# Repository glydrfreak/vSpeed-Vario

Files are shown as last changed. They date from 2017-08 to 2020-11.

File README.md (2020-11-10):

### This repository contains all previous prototypes. </br>
### Click <a href="https://github.com/glydrfreak/vSpeedVario-mini">here</a> for the final product repository. </br>
<table float="center">
  <tr>
    <td align="center" width=50%>
      <h1>v^Speed Vario</h1>
      Contents:</br>
      <a href="https://github.com/glydrfreak/vSpeedVario-mini">v^SPEED VARIO mini</a></br>
      <a href="#compare">Compare</a> </br>
      <a href="#vspeed-vario">Android App</a></br>
      <a href="#flyskyhy">iPhone App</a> </br>
      <a href="#solidworks">3D Printing</a> </br>
      <a href="#arduino-ide">Arduino Code</a> </br>
      <a href="#eagle-cad">Custom Circuit Board</a> </br>
      <a href="#bill-of-materials">Parts List</a> </br>
    </td>
    <td align="center"> 
      <h3>DIY Paragliding Variometer</h3>
       
      <h6>(Vertical Speed Indicator)</h6>
    </td>
  </tr>
</table>

<table>
  <tr>
    <td width=33% vAlign="top" align="center">
      <h2>v^SPEED VARIO mini</h2>
      <h3>$99</h3>
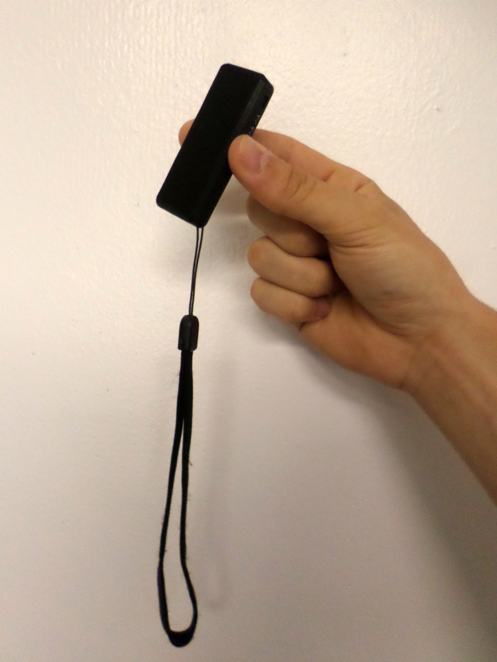
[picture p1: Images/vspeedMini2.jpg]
       </br>
         Email vSpeedVario@gmail.com to purchase </br>
      <a href="#vspeed-vario">Back to Top</a> </br>
    </td>
    <td width=66%> 
      <ul>
        <h3>SPECS:</h3>
        <li>Ultra-high precision barometric pressure sensor detects altitude changes as small as 10cm</li>
        <li>Lowest priced Bluetooth Variometer on the market</li>
        <li>iPhone users: Fully compatible with <a href="#flyskyhy">FlySkyHy</a> app</li>
        <li>Android users: <a href="#vspeed">v^SPEED</a> app new in Google Play Store</li>
        <li>Fully compatiple with Arduino IDE to easily change custom settings</li>
        <li>Mounts on risers with velcro</li>
        (leash, and velcro for both riser and vario included)
        <li>Tiny Size: 68x25x10mm (about the size of a man's thumb)</li>
        <li>3D printed cover screws onto circuit board </li>
          (black, white, yellow, or light blue)
        <li>Power switch, and volume buttons</li>
        <li>100mAh lipo battery with microUSB charging port</li>
        <li>7hr battery life while streaming bluetooth data</li>
        <li>1hr charging time</li>
        <li>Sale price: $99 each (subject to change)</li>
        <h3>OR -- DIY! --</h3><h6>(assuming you have a 3D printer, an SWD programmer, and a reflow oven)</h6>
        <li>1 hand assembled: ~ $70 each </li>
        <li>10 hand assembled: ~ $38 each</li>
        <li>10 machine assembled: ~ $89 each</li>
        <li>100 machine assembled: ~ $59 each</li>
      </ul>
    </td>
  </tr>
</table>

<table>
  <tr>
    <td width=33% vAlign="top" align="center">
      <h2>v^SPEED Vario</h2>
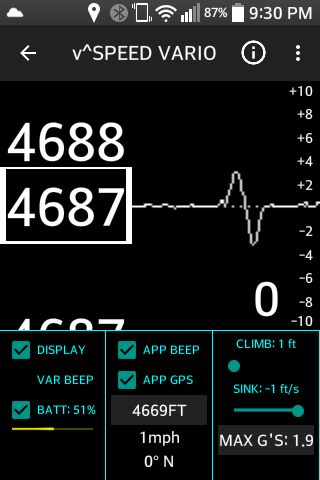
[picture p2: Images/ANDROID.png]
      
      <a href="#vspeed-vario">Back to Top</a> </br>
    </td>
    <td width="66%"> 
      <ul>
        <h3>Android App--</h3>
        I have modified Adafruit's "Bluefruit LE Connect" for Android and the source code can be found in the Android folder. Now published to Google Play! </br>
  </br>
        This app will give you a better image of what your v^SPEED Vario is doing as it transmits live bluetooth data of barometric altitude, vertical speed, and battery level. Other features include implemented GPS for GPS altitude, ground speed, and heading. The implemented Audio beeps are helpful for listening to each foot of climb as well as a variable sink tone. An implemented accelerometer is for keeping track of max G-force during a hard turn or spiral. The visual display includes a line chart of vertical speed, as well as scrolling altitude numbers so you can see your precise vertical velocity. The climb and sink thresholds are adjustable within the app, which also change the thresholds on the external vario automatically.
      </ul>
    </td>
  </tr>
</table>

<table>
  <tr>
    <td width=33% vAlign="top" align="center">
      <h2>Flyskyhy</h2>
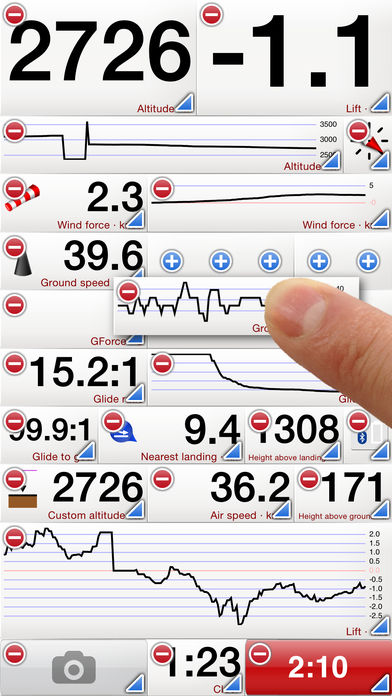
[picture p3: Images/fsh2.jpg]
      
      <a href="#vspeed-vario">Back to Top</a> </br>
    </td>
    <td width=66%> 
      <ul>
        <h3>iOS App by Renevision--</h3>
        I've been working with Rene to get v^SPEED VARIO compatible with the World's most popular Paragliding app! He's been very helpful throughout the process, and Flyskyhy is an unbeatable iPhone application when it comes to flying. v^Speed Vario is currently using the same protocol as SkyDrop variometers, so in the app when selecting your device, you must choose SkyDrop for the time being.  
      </ul>
    </td>
  </tr>
</table>

<h1>Prior Prototypes:</h1>

<table>
  <tr>
    <td width=33% vAlign="top" align="center">
      <h2>PROTOTYPE5</h2>
      <h4>(In Progress)</h4>
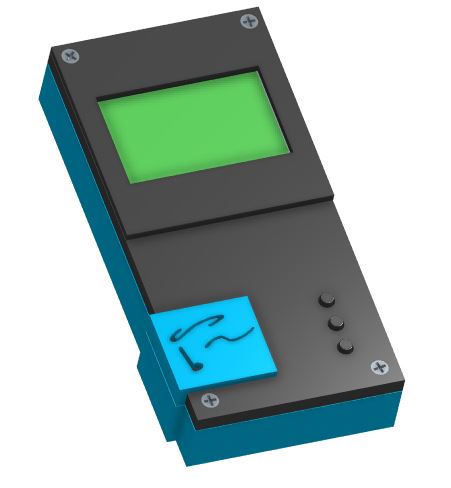
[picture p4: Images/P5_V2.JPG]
      
      <a href="#vspeed-vario">Back to Top</a> </br>
    </td>
    <td width=66%> 
      <ul>
        <h3>IMPROVEMENTS:</h3>
        <li>Nokia 5110 LCD is much cheaper</li>
        <li>2.9" e-Paper display was having interference issues</li>
        <li>Three buttons used for interfacing with menu</li>
        <li>Screw-together 3D printed case is much more printer friendly</li>
        <li>Size: 97x47x18mm</li>
        <li>Material cost for ten: ~ $54 each</li>
        <li>Material cost for one: ~ $96 each</li>
      </ul>
    </td>
  </tr>
</table>

<table>
  <tr>
    <td width=33% vAlign="top" align="center">
      <h2>PROTOTYPE4</h2>
      <h4>(Aborted)</h4>
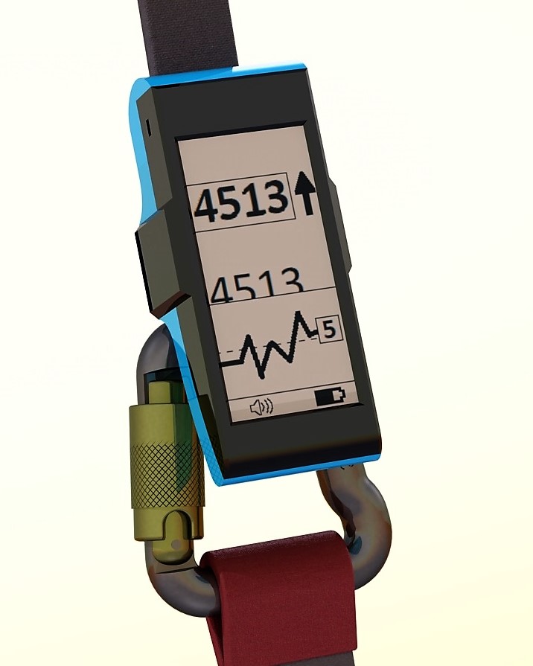
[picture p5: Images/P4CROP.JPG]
      
      <a href="#vspeed-vario">Back to Top</a> </br>
    </td>
    <td width=66%> 
      <ul>
        <h3>IMPROVEMENTS:</h3>
        <li>Bluetooth compatible with:</li>
        <ul>
          <li>iPhone: Flyskyhy</li>
          <li>Android: v^Speed (soon to be published)</li>
        </ul>
        <li>2.9" e-Paper display is much larger</li>
        <li>Amplified electromagnetic buzzer is much louder</li>
        <li>Micro SD saves settings and any desired flight data</li>
        <li>Single Button power-on also used for interfacing with menu</li>
        <li>Machine assembly potential: All SMD components, except the switch</li>
        <li>Size: 100x40x30mm</li>
        <li>Material cost for ten: $69 each</li>
        <li>Material cost for one: $111 each</li>
      </ul>
    </td>
  </tr>
</table>

<table>
  <tr>
    <td width=33% align="center" vAlign="top">
      <h2>PROTOTYPE3</h2>
      <h4>(Fully Working)</h4>
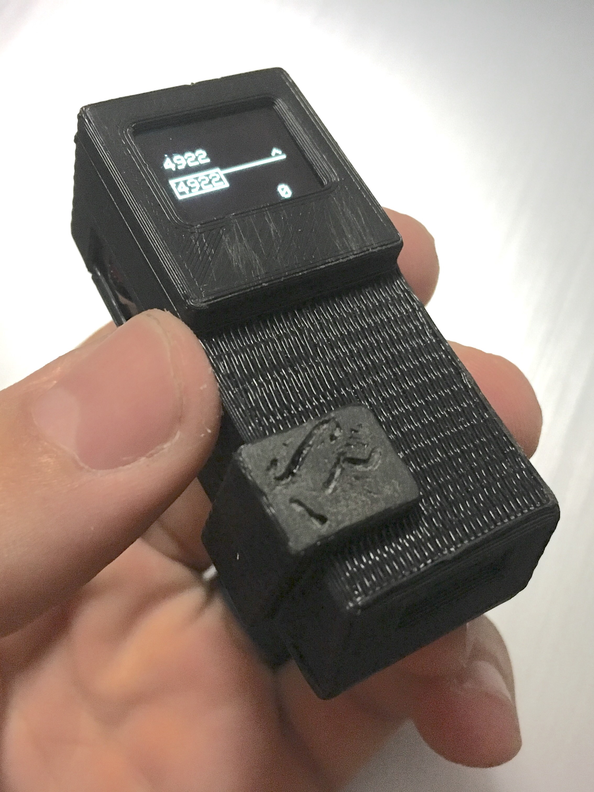
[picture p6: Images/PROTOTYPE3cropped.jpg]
       
      <a href="#vspeed-vario">Back to Top</a> </br>
    </td>
    <td width=66%> 
      <ul>
        <h3>IMPROVEMENTS:</h3>
        <li>Bluetooth compatible with:</li>
        <ul>
          <li>iPhone: Flyskyhy</li>
          <li>Android: v^SPEED (soon to be published)</li>
        </ul>
        <li>Adafruit Feather Bluefruit M0</li>
        <li>MS5611 Barometric Pressure/Temperature Sensor (SPI mode) </li>
        <li>Less than several INCHES of altitude noise with a simple averaging filter</li>
        <li>37 Altitude samples per second with the display screen ON</li>
        <li>56 Altitude samples per second while connected to your phone with the display screen OFF</li>
        <li>Size: 60x28x20mm (perfect for wrist watch, or riser mounting)</li>
        <li>0.66" OLED display (SPI mode)</li>
        <li>PS1740 Piezo Buzzer</li>
        <li>3D Printed Case</li>
        <li>Custom designed PCB</li>
        <li>Audio and a handful of widgets are implemented in each app</li>
        <li>Material cost for ten: $45 each</li>
        <li>Material cost for one: $77 each</li>
      </ul>
    </td>
  </tr>
</table>

<table>
  <tr>
    <td width=33% align="center" vAlign="top">
      <h2>PROTOTYPE2</h2>
      <h4>(Discontinued)</h4>
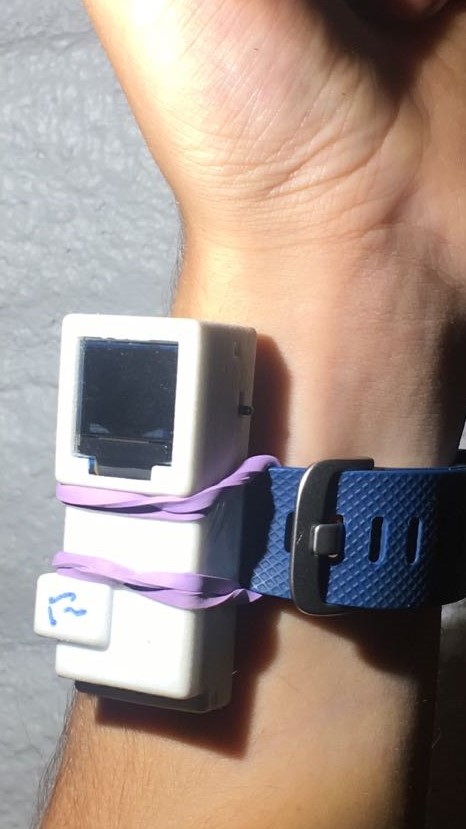
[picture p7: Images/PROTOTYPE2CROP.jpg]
       
      <a href="#vspeed-vario">Back to Top</a> </br>
    </td>
    <td width=66%> 
      <ul>
        <h3>IMPROVEMENTS:</h3>
        <li>Bluetooth compatible with:</li>
        <ul>
          <li>iPhone: (Not yet compatible) </li>
          <li>Android: v^SPEED (soon to be published)</li>
        </ul>
        <li>Adafruit Feather Bluefruit 32u4</li>
        <li>MS5611 Barometric Pressure/Temperature Sensor (SPI mode) </li>
        <li>Less than several INCHES of altitude noise with a simple averaging filter</li>
        <li>21 Altitude samples per second with the display screen ON</li>
        <li>49 Altitude samples per second while connected to your phone with the display screen OFF</li>
        <li>Size: 60x20x28mm (perfect for wrist watch, or riser mounting)</li>
        <li>0.66" OLED display (SPI mode)</li>
        <li>PS1740 Piezo Buzzer</li>
        <li>3D Printed Case</li>
        <li>Custom designed PCB</li>
        <li>Audio and a handful of widgets are implemented in the  v^SPEED app</li>
        <li>Material cost for ten: $45 each</li>
        <li>Material cost for one: $77 each</li>
      </ul>
    </td>
  </tr>
</table>

<table>
  <tr>
    <td width=33% align="center" vAlign="top">
      <h2>PROTOTYPE1</h2>
      <h4>(One of a kind)</h4>
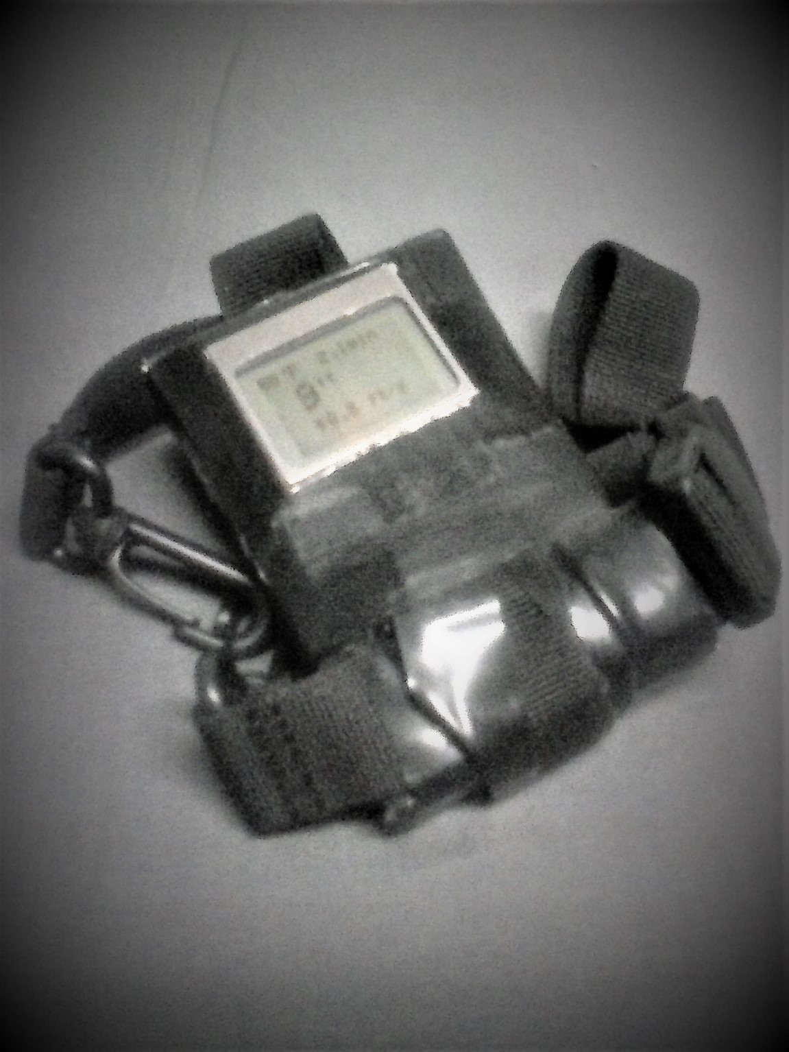
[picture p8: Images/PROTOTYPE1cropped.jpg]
      
      <a href="#vspeed-vario">Back to Top</a> </br>
    </td>
    <td width=66%> 
      <ul>
        <h3>SPECIFICATIONS:</h3>
        <li>Arduino Nano</li>
        <li>BMP180 Barometric Pressure/Temperature Sensor (I2C mode)</li>
        <li>Just about a foot of altitude noise with a simple averaging filter</li>
        <li>13 Altitude samples per second</li>
        <li>Size: 60x20x28mm (perfect for wrist watch, or riser mounting)</li>
        <li>NOKIA5110 LCD Display (SPI mode)</li>
        <li>Backlight Control</li>
        <li>Volume Control</li>
        <li>PS1240 Piezo Buzzer</li>
        <li>Material cost for one: $20</li>
      </ul>
    </td>
  </tr>
</table>

<table border="1" align="center" >
  <tr> 
    <td VAlign="bottom"> 
      <h3>COMPARE:</h3><br/>
      <a href="#vspeed-vario">Back to Top</a> </br>
       
    </td>
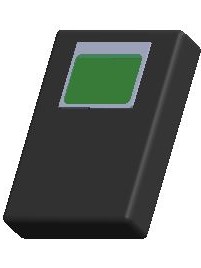
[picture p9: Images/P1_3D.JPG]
    <td width="20%" align="center"> 	</td>
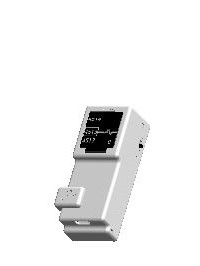
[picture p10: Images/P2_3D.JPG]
    <td width="20%" align="center"> 	</td>	
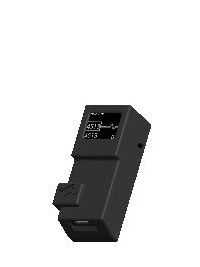
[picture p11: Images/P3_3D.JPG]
    <td width="20%" align="center"> 	</td>
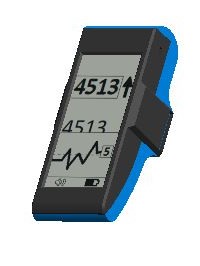
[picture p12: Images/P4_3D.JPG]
    <td width="20%" align="center"> 	</td>
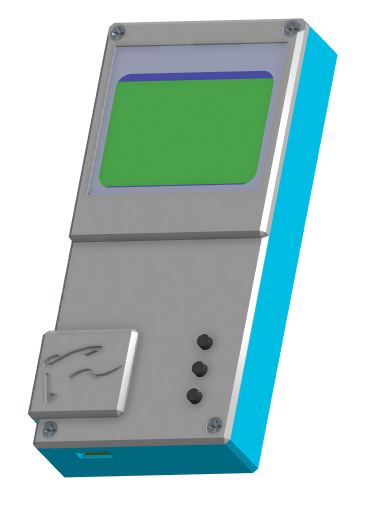
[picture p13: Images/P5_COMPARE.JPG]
    <td width="20%" align="center"> 	</td>
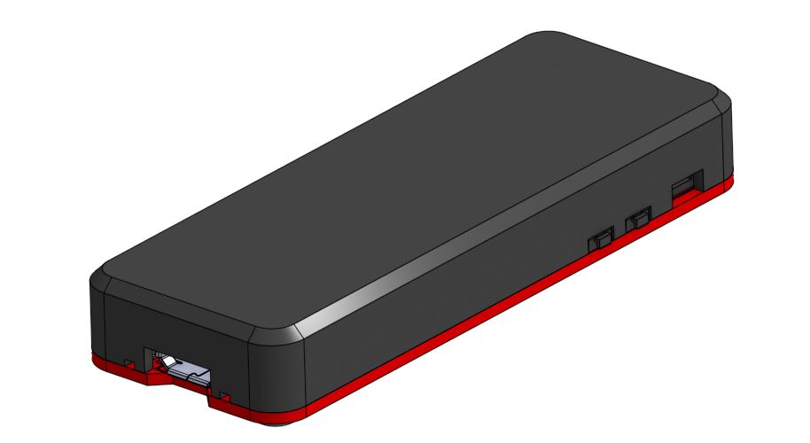
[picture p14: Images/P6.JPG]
    <td width="20%" align="center"> 	</td>
  </tr>
  <tr> 
    <td align="center"> <b>Model</b> </td>
    <td align="center"> <b>PROTOTYPE1</b>	</td>
    <td align="center"> <b>PROTOTYPE2</b>	</td>	
    <td align="center"> <b>PROTOTYPE3</b>	</td>
    <td align="center"> <b>PROTOTYPE4</b>	</td>
    <td align="center"> <b>PROTOTYPE5</b>	</td>
    <td align="center"> <b>PROTOTYPE6</b>	</td>
  </tr>
  <tr> 
    <td align="center"> <b>Height x Width x Thickness (mm)</b>	 </td>
    <td align="center"> 100 x 70 x 20		</td>
    <td align="center"> 	60 x 28 x 20	</td>	
    <td align="center">  60 x 28 x 20	</td>
    <td align="center"> 100 x 40 x 30	</td>
    <td align="center"> 97 x 47 x 18	</td>
    <td align="center"> 68 x 25 x 10	</td>
  </tr>
  <tr> 
    <td align="center"> <b>Controller</b>	 </td>
    <td align="center"> Arduino Nano		</td>
    <td align="center"> Bluefruit Feather 32u4	</td>	
    <td align="center"> Bluefruit Feather M0	</td>
    <td align="center"> Bluefruit Feather M0	</td>
    <td align="center"> Bluefruit Feather M0	</td>
    <td align="center"> ATSAMD21G18A-MU	</td>
  </tr>
  <tr> 
    <td align="center"> <b>Barometer</b>	 </td>
    <td align="center"> BMP180		</td>
    <td align="center"> MS5611	</td>	
    <td align="center"> MS5611	</td>
    <td align="center"> MS5611	</td>
    <td align="center"> MS5611	</td>
    <td align="center"> MS5611	</td>
  </tr>
  <tr> 
    <td align="center"> <b>Altitude Sample Rate (Hz)</b>	 </td>
    <td align="center"> 13		</td>
    <td align="center"> 21-49	</td>	
    <td align="center"> 37-56	</td>
    <td align="center"> (Not Tested Yet)	</td>
    <td align="center"> ~ 60 </td>
    <td align="center"> ~ 80 </td>
  </tr>  
  <tr> 
    <td align="center"> <b>Altitude Precision (cm)</b> </td>
    <td align="center"> 35		</td>
    <td align="center"> 11	</td>	
    <td align="center"> 10	</td>
    <td align="center"> (Not Tested Yet)	</td>
    <td align="center"> 10	</td>
    <td align="center"> ~ 8	</td>
  </tr>  
  <tr> 
    <td align="center"> <b>Android App Compatibility</b> </td>
    <td align="center"> -		</td>
    <td align="center"> v^SPEED	</td>	
    <td align="center"> v^SPEED	</td>
    <td align="center"> v^SPEED	</td>
    <td align="center"> v^SPEED	</td>
    <td align="center"> v^SPEED	</td>
  </tr> 
  <tr> 
    <td align="center"> <b>iPhone App Compatibility</b> </td>
    <td align="center"> - </td>
    <td align="center"> -	</td>	
    <td align="center"> Flyskyhy	</td>
    <td align="center"> Flyskyhy	</td>
    <td align="center"> Flyskyhy	</td>
    <td align="center"> Flyskyhy	</td>
  </tr> 
  <tr> 
    <td align="center"> <b>Battery</b> </td>
    <td align="center"> 9V </td>
    <td align="center"> BTG 150 mAh Li-Po 3.7V	</td>	
    <td align="center"> BTG 150 mAh Li-Po 3.7V	</td>
    <td align="center"> BTG 150 mAh Li-Po 3.7V	</td>
    <td align="center"> BTG 150 mAh Li-Po 3.7V	</td>
    <td align="center"> Adafruit 100 mAh Li-Po 3.7V	</td>
  </tr> 
  <tr> 
    <td align="center"> <b>Battery Life w/ Full Function</b> </td>
    <td align="center"> (Hasn't Died Yet) </td>
    <td align="center"> (Approx 8 hr)	</td>	
    <td align="center"> (Approx 8 hr)	</td>
    <td align="center"> (Not Tested Yet)	</td>
    <td align="center"> (Not Tested Yet)	</td>
    <td align="center"> (Not Tested Yet)	</td>
  </tr> 
  <tr> 
    <td align="center"> <b>Buzzer</b> </td>
    <td align="center"> PS1240 </td>
    <td align="center"> PS1740	</td>	
    <td align="center"> PS1740	</td>
    <td align="center"> BOT-03D-BUJEON	</td>
    <td align="center"> BOT-03D-BUJEON	</td>
    <td align="center"> SMT-1127-S-R	</td>
  </tr> 
  <tr> 
    <td align="center"> <b>Amplification</b> </td>
    <td align="center"> - </td>
    <td align="center"> - </td>	
    <td align="center"> -	</td>
    <td align="center"> Yes	</td>
    <td align="center"> Yes	</td>
    <td align="center"> Yes	</td>
  </tr> 
  <tr> 
    <td align="center"> <b>Volume Control</b> </td>
    <td align="center"> Thumbwheel </td>
    <td align="center"> Thumbwheel	</td>	
    <td align="center"> Thumbwheel	</td>
    <td align="center"> Digital	</td>
    <td align="center"> Digital	</td>
    <td align="center"> Digital	</td>
  </tr> 
  <tr> 
    <td align="center"> <b>Display</b> </td>
    <td align="center"> Nokia5110 LCD </td>
    <td align="center"> 0.66" OLED	</td>	
    <td align="center"> 0.66" OLED	</td>
    <td align="center"> 2.9" e-Paper	</td>
    <td align="center"> Nokia5110 LCD </td>
    <td align="center"> (Use Bluetooth) </td>
  </tr> 
  <tr> 
    <td align="center"> <b>Micro SD Slot</b> </td>
    <td align="center"> - </td>
    <td align="center"> -	</td>	
    <td align="center"> -	</td>
    <td align="center"> Yes	</td>
    <td align="center"> Yes	</td>
    <td align="center"> -	</td>
  </tr> 
  <tr> 
    <td align="center"> <b>User Control</b> </td>
    <td align="center"> Volume, Brightness, Power </td>
    <td align="center"> Volume, Power	</td>	
    <td align="center"> Volume, Power	</td>
    <td align="center"> Single Button	</td>
    <td align="center"> Three Button, Power	</td>
    <td align="center"> Two Button, Power	</td>
  </tr> 
  <tr> 
    <td align="center"> <b>Custom Settings</b> </td>
    <td align="center"> Arduino Upload </td>
    <td align="center"> Arduino Upload </td>	
    <td align="center"> Arduino Upload </td>
    <td align="center"> Settings Menu	</td>
    <td align="center"> Settings Menu	</td>
    <td align="center"> Arduino Upload </td>
  </tr> 
  <tr> 
    <td align="center"> <b>Mounting</b> </td>
    <td align="center"> Leg Strap </td>
    <td align="center"> Riser, Wrist	</td>	
    <td align="center"> Riser, Wrist	</td>
    <td align="center"> Riser	</td>
    <td align="center"> Leg Strap </td>
    <td align="center"> Leg Strap, Riser </td>
  </tr> 
  <tr> 
    <td align="center"> <b>Assembly</b> </td>
    <td align="center"> Cardboard, Protoboard, Wire </td>
    <td align="center"> Custom PCB Through-hole </td>    
    <td align="center"> Custom PCB Through-hole </td>
    <td align="center"> Custom PCB Surface Mount </td>  
    <td align="center"> Custom PCB Surface Mount </td>  
    <td align="center"> 100% machine assembly potential </td>  
  </tr> 
  <tr> 
    <td align="center"> <b>Qty 10 Unit Material Cost (USD)</b> </td>
    <td align="center"> $20 </td>
    <td align="center"> $45 </td>    
    <td align="center"> $45 </td>
    <td align="center"> $69 </td>  
    <td align="center"> $54 </td> 
    <td align="center"> $37 </td> 
  </tr> 
  <tr> 
    <td align="center"> <b>Qty 1 Unit Material Cost (USD)</b> </td>
    <td align="center"> $20 </td>
    <td align="center"> $77 </td>    
    <td align="center"> $77 </td>
    <td align="center"> $111 </td> 
    <td align="center"> $96 </td> 
    <td align="center"> $70 </td> 
  </tr> 
</table>

## ADDITIONAL INFORMATION: <br />
### Footage: <br />
Introduction: https://www.youtube.com/watch?v=gFNgn0X94sw <br />
In-Flight Test: https://www.youtube.com/watch?v=RXyAx8dpHaY <br />

The only footage I have for the app is during an Imagine Dragons concert in a low averaging setting--  <br />
Android App: https://www.youtube.com/watch?v=2kcBOBjCzPE&t=4s <br />
(At about 1:20 the heavy base ramps up during the song and makes the barometric sensor data go nuts!) <br />

## Contact with questions or concerns:
Contact: vSpeedVario@gmail.com

#### This is an open-source project 

<table>
  <tr>
    <td width=33% vAlign="top" align="center">
      <h2>SolidWorks</h2>
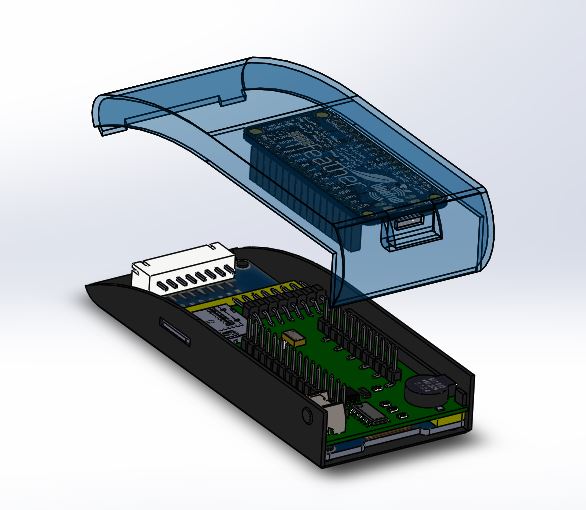
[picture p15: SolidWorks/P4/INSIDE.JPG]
      
      <a href="#vspeed-vario">Back to Top</a> </br>
    </td>
    <td width="66%"> 
      <ul>
        <h3>3D Printing--</h3>
        Printing the cases for each variometer should be quite a bit cheaper now that my dad purchased a Prusa i3 MK3 3D printer. SOLIDWORKS is my software of choice, but if it's not available for you, I would suggest OnShape.com for designing your 3D printed parts.
      </ul>
    </td>
  </tr>
</table>

<table>
  <tr>
    <td width=33% vAlign="top" align="center">
      <h2>Arduino IDE</h2>
      
      <a href="#vspeed-vario">Back to Top</a> </br>
    </td>
    <td width="66%"> 
      <ul>
        <h3>Programing Code--</h3>
        The Arduino integrated development environment (IDE) is the free software and programming language compatible with this device. Paul McWhorter got me hooked on his YouTube video series of lessons for learning Arduino. Before the summer of 2017, I had no interest in electronics, until I realized you can do almost anything when you combine it with computer programming. I ended up pulling an all nighter as I watched every single one of those videos, and suddenly I knew how electronics worked, and I knew how to implement my own ideas in the Arduino Software. 
      </ul>
    </td>
  </tr>
</table>

<table>
  <tr>
    <td width=33% vAlign="top" align="center">
      <h2>Eagle CAD</h2>
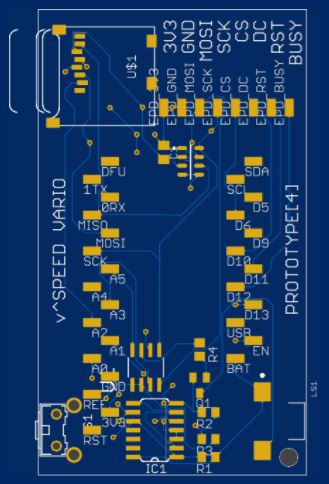
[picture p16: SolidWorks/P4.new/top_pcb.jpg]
      
      <a href="#vspeed-vario">Back to Top</a> </br>
    </td>
    <td width="66%"> 
      <ul>
        <h3>Custom PCB--</h3>
        A Custom PCB is designed in the free Eagle CAD software and ordered through SEEED Studios. 
      </ul>
    </td>
  </tr>
</table>

<table>
  <tr>
    <td width=33% vAlign="top" align="center">
      <h2>Bill of Materials</h2>
      
      <a href="#vspeed-vario">Back to Top</a> </br>
    </td>
    <td width="66%"> 
      <ul>
        <h3>Full Parts List--</h3>
        <a href="https://github.com/glydrfreak/vSpeedVario/blob/master/BillOfMaterials/P5_BOM.xlsx?raw=true">Download PROTOTYPE5 Parts List</a></br>
        <a href="https://github.com/glydrfreak/vSpeedVario/blob/master/BillOfMaterials/P6_BOM.xlsx?raw=true">Download PROTOTYPE6 Parts List</a></br>
      </ul>
    </td>
  </tr>
</table>

##### Where Did I Learn All This?--
Besides the fact that I've been teaching myself all this stuff,<br />
HUGE bragging rights within this project can be claimed by:<br />
Paul Butler ( my Dad )<br />
Paul McWhorter ( http://toptechboy.com )<br />
Adafruit Industries ( https://www.adafruit.com/ )<br />
Sparkfun Electronics ( https://www.sparkfun.com/ )<br />
BlueFlyVario ( http://blueflyvario.blogspot.com.au/ )<br />

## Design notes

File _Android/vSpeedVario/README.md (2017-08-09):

v^SPEED VARIO for Android
================================

## (Modified) Bluefruit LE Connect for Android

Android port of Adafruit's Bluefruit LE Connect app for iOS.

This application works with the following Adafruit breakouts:

- [Bluefruit LE Friend](https://www.adafruit.com/product/2267)
- [Bluefruit LE UART Friend](https://www.adafruit.com/product/2479)
- [Bluefruit LE SPI Friend](https://www.adafruit.com/product/2633)
- [Bluefruit LE Shield](https://www.adafruit.com/products/2746)
- [Bluefruit LE Micro](https://www.adafruit.com/product/2661)
- [Feather 32u4 Bluefruit LE](https://www.adafruit.com/product/2829)
- [Feather M0 Bluefruit LE](https://www.adafruit.com/products/2995)

Bluefruit LE Connect enables the exchange of information between your Bluefruit LE breakout and your BLE enabled Android device (Android 4.4 and higher required).  

The application also enables [over the air updates](https://learn.adafruit.com/introducing-the-adafruit-bluefruit-le-uart-friend/dfu-updates) to keep your Bluefruit module up to date with the latest [Bluefruit LE firmware](https://github.com/adafruit/Adafruit_BluefruitLE_Firmware).

## License

Unless otherwise specified, all files produced by Adafruit are covered by an [MIT license](https://github.com/adafruit/Bluefruit_LE_Connect_Android/blob/master/license.txt).  

Files produced by Nordic Semiconductors are covered by their own license terms, as detailed in the file headers and appropriate folders. Please carefully review the license requirements before using this source code in your own application.

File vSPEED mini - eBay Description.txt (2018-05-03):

<table float="center">
  <tr>
    <td align="center" width=50%>
      <h1>v^Speed Vario</h1>
      <h3>DIY Paragliding Variometer</h3>
       
      <h6>(Vertical Speed Indicator)</h6>
    </td>
  </tr>
</table>

</br>
</br>

<table>
  <tr>
    <td width=33% vAlign="top" align="center">
      <h2>v^SPEED VARIO mini</h2>
      <h3>$99</h3>
      
      <h2>COMING SOON</h2></br>
        Be the first to know about availability! </br>
        (contact seller through eBay) </br>
    </td>
    <td width=66%> 
      <ul>
        <h3>SPECS:</h3>
        <li>Ultra-high precision barometric pressure sensor detects altitude changes as small as 10cm</li>
        <li>Lowest priced Bluetooth Variometer on the market</li>
        <li>iPhone users: Fully compatible with FlySkyHy</li>
        <li>Android users: Fully compatible with v^SPEED</li>
        <li>Fully compatiple with Arduino IDE to easily change custom settings</li>
        <li>Mounts on risers with sticky velcro</li>
        (leash, and velcro for both riser and vario included)
        <li>Tiny Size: 68x25x10mm (about the size of a man's thumb)</li>
        <li>3D printed cover screws onto circuit board </li>
          (black, white, yellow, or light blue)
        <li>Power switch, and volume buttons</li>
        <li>100mAh lipo battery with microUSB charging port</li>
        <li>Battery should last all day while streaming bluetooth data (not yet tested)</li>
      </ul>
    </td>
  </tr>
</table>

</br>
</br>

<table>
  <tr>
    <td width=33% vAlign="top" align="center">
      <h2>v^SPEED</h2>
      
    </td>
    <td width="66%"> 
      <ul>
        <h3>Android App--</h3>
        I have modified Adafruit's "Bluefruit LE Connect" for Android and the source code can be found in the Android folder. Coming soon to Google Play, but for now, just plop it into Android Studio and upload it to your Android device.
      </ul>
    </td>
  </tr>
</table>

</br>
</br>

<table>
  <tr>
    <td width=33% vAlign="top" align="center">
      <h2>Flyskyhy</h2>
      
    </td>
    <td width=66%> 
      <ul>
        <h3>iOS App by Renevision--</h3>
        I've been working with Rene to get v^SPEED VARIO compatible with the World's most popular Paragliding app! He's been very helpful throughout the process, and Flyskyhy is an unbeatable iPhone application when it comes to flying. v^Speed Vario is currently using the same protocol as SkyDrop variometers, so in the app when selecting your device, you must choose SkyDrop for the time being.  
      </ul>
    </td>
  </tr>
</table>

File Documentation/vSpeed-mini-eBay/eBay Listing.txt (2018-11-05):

<table float="center">
  <tr>
    <td align="center" width=66%>
      <h1>v^SPEED Vario mini</h1>
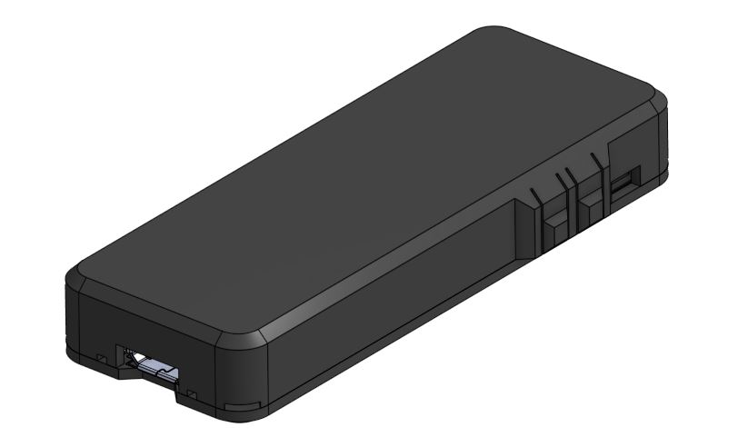
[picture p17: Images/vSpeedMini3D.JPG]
      
    </td>
    <td align="center" width=33%> 
      <h3>Open Source Paragliding Variometer</h3>
       
      <h6>(Vertical Speed Indicator)</h6>
    </td>
  </tr>
</table>

<h2>ABOUT</h2>
This is an open source project, with all public files available at the "vSpeed-Vario" repository on GitHub. The v^SPEED mini is based on PROTOTYPE6, which is found within that same repository. This variometer was designed to be compatible with the Arduino IDE for advanced usage, which allows users to modify the existing source code to their pleasure. In another GitHub repository called "vSpeedVario-mini", you will find the most up-to-date source code for use in the Arduino IDE. The hardware is based on another great open source product, Adafruit's Bluefruit Feather M0. The v^SPEED mini is basically just a Bluefruit Feather M0 development board, but without the header pins broken out, and with the added variometer circuitry.
</br>
</br>
</br>
</br>
<table>
  <tr>
    <td width=66%> 
      <ul>
        <h3>SPECS:</h3>
        <li>Ultra-high precision barometric pressure sensor detects altitude changes as small as 10cm</li>
        <li>Measures altitude 84 times per second</li>
          (72 while transmitting bluetooth data)
        <li>Lowest priced Bluetooth Variometer on the market</li>
        <li>iPhone users: Fully compatible with FlySkyHy app</li>
        <li>Android users: v^SPEED app new in Google Play Store</li>
        <li>Fully compatiple with Arduino IDE to easily change custom settings</li>
          (such as beep thresholds, audio pitches, startup bluetooth mode, etc...)
        <li>Mounts on risers with velcro</li>
          (Leash, and velcro for both riser and vario included)
        <li>Tiny Size: 68x25x10mm (about the size of a man's thumb)</li>
        <li>3D printed cover screws onto circuit board </li>
        <li>Power switch, and volume buttons</li>
        <li>Amplified buzzer for audio beeps</li>
        <li>150mAh lipo battery with microUSB charging port</li>
        <li>~10hr battery life while streaming bluetooth data</li>
        <li>~1.5hr charging time</li>
         (Micro USB cable included)
        <li>Sale price: $99 each</li>
      </ul>
    </td>
    <td width=33% vAlign="top" align="center">
      <h2>v^SPEED VARIO mini</h2>
      <h3>$99</h3>
      
    </td>
  </tr>
</table>
</br>
</br>
</br>
</br>
More information including instructions for usage, see https://github.com/glydrfreak/vSpeedVario-mini

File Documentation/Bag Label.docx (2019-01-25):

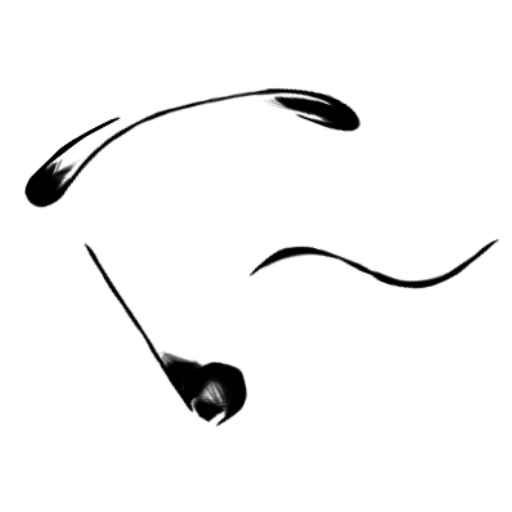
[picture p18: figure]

v^SPEED VARIO mini

Instructions:

github.com/glydrfreak/vSpeedVario-mini#start-here

v^SPEED VARIO mini

Instructions:

github.com/glydrfreak/vSpeedVario-mini#start-here

PART QTY _

v^SPEED VARIO mini 1

Micro USB Cable 1

6’’ x 2’’ Double Sided Velcro Riser Wrap 1 _ _

Total (before tax) $99.00 USD

PART QTY _

v^SPEED VARIO mini 1

Micro USB Cable 1

6’’ x 2’’ Double Sided Velcro Riser Wrap 1 _ _

Total (before tax and shipping) $99.00 USD

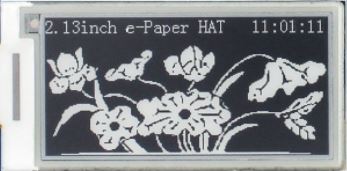
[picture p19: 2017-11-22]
SolidWorks/P4/P4_2.13_EPAPER.JPG

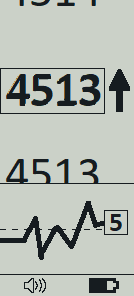
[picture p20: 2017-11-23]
SolidWorks/P4.new/epaper_graphic.png

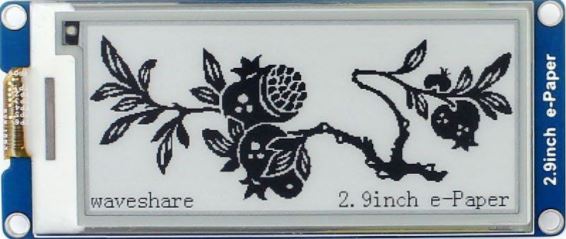
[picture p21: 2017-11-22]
SolidWorks/P4.new/p4_2.9_epaper.jpg

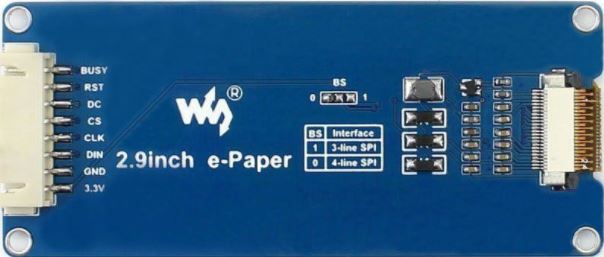
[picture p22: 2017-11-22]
SolidWorks/P4.new/p4_2.9_epaper_back.jpg

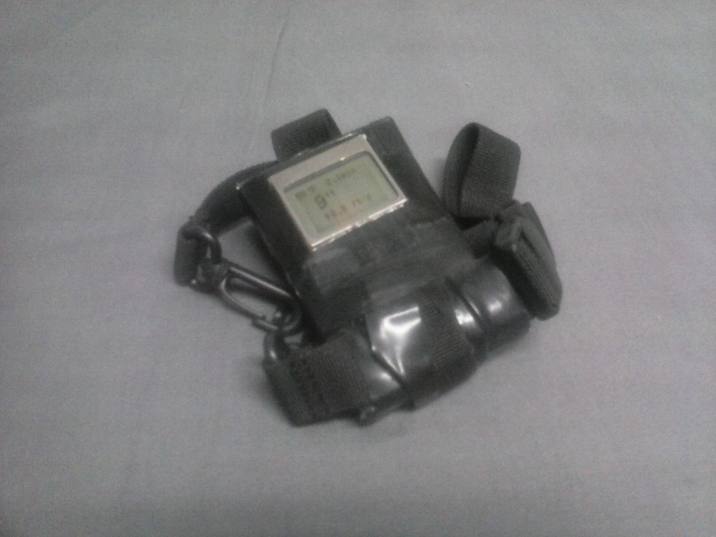
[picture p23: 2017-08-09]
PROTOTYPE1uncropped.jpg

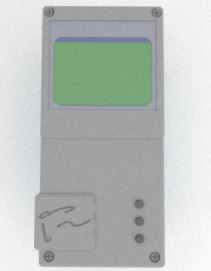
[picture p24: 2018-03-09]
Images/P5_FRONT.JPG

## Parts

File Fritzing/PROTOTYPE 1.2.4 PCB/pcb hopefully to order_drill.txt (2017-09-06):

; NON-PLATED HOLES START AT T1
; THROUGH (PLATED) HOLES START AT T100
M48
INCH
T100C0.015748
T101C0.035433
T102C0.011811
%
T100
X014360Y000342
X008360Y001342
X015354Y007345
X013360Y006342
X015360Y003342
X010360Y006342
X011360Y003342
X005360Y006342
X014360Y004342
X015360Y000342
X017362Y001349
X008360Y004342
X006360Y005342
X016358Y007338
X013360Y004342
X007360Y004342
X013368Y003336
T101
X001360Y000342
X018360Y007342
X015360Y002342
X010360Y000342
X018360Y005342
X014360Y006342
X007360Y008342
X019360Y007342
X008360Y008342
X011360Y000342
X012360Y006342
X014360Y002342
X019360Y002342
X016360Y006342
X018360Y002342
X015360Y006342
X018360Y001342
X018360Y006342
X008360Y002342
X018360Y003342
X009360Y008342
X000360Y008342
X019360Y001342
X009360Y000342
X019360Y004342
X019360Y006342
X003360Y000342
X010360Y008342
X012360Y000342
X018360Y004342
X005360Y008342
X016360Y002342
X019360Y005342
X019360Y003342
T102
X013360Y001342
X017360Y000342
T00
M30

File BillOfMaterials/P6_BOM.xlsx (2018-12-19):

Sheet: V1
INSTOCK | REQUIRED QTY | PRICE BREAKS | Parts | MPN | DESCRIPTION | DISTRIBUTER | PRICE @ QTY 1 VARIO | PRICE @ QTY 10 VARIOS
0 | 1 | 1, 10 | Q1 | MMBT2222LT1G (https://www.digikey.com/product-detail/en/on-semiconductor/MMBT2222LT1G/MMBT2222LT1GOSCT-ND/1139808) | NPN SOT23 | DIGIKEY | $0.1300 | $0.1150
9 | 1 | 1, 10 | C10 | CL21B104KOANNNC (https://www.digikey.com/scripts/DkSearch/dksus.dll?Detail&itemSeq=255687110&uq=636573319776344879) | CAP 0.1uF 0805 | DIGIKEY | $0.1000 | $0.0290
0 | 3 | 10, 100 | R1, R3, R6 | RC0603JR-07100KL (https://www.digikey.com/scripts/DkSearch/dksus.dll?Detail&itemSeq=255688809&uq=636573327832494815) | RES 100K 0603 | DIGIKEY | $0.0110 | $0.0046
0 | 1 | 1, 10 | R8 | RC0603JR-0710KL (https://www.digikey.com/scripts/DkSearch/dksus.dll?Detail&itemSeq=255688956&uq=636573328681559713) | RES 10K 0603 | DIGIKEY | $0.1000 | $0.0110
0 | 5 | 10, 100 | C3, C5, C6, C8, C9 | CL21A106KQCLRNC (https://www.digikey.com/scripts/DkSearch/dksus.dll?Detail&itemSeq=255687461&uq=636573320529169726) | CAP 10uF 0805 | DIGIKEY | $0.0700 | $0.0313
0 | 2 | 10, 100 | R2, R9 | RC0603JR-071KL (https://www.digikey.com/scripts/DkSearch/dksus.dll?Detail&itemSeq=255689053&uq=636573329310919726) | RES 1K 0603 | DIGIKEY | $0.0110 | $0.0046
0 | 3 | 10, 100 | C1, C7, C14 | CL10A105KQ8NNNC (https://www.digikey.com/scripts/DkSearch/dksus.dll?Detail&itemSeq=255687743&uq=636573321888037133) | CAP 1uF 0603 | DIGIKEY | $0.0320 | $0.0143
0 | 3 | 10, 100 | R4, R7, R10 | RC0603JR-072K2L (https://www.digikey.com/scripts/DkSearch/dksus.dll?Detail&itemSeq=255689221&uq=636573330063847928) | RES 2.2K 0603 | DIGIKEY | $0.0110 | $0.0046
0 | 2 | 10, 100 | C2, C4 | CL10C220JB8NCNC (https://www.digikey.com/scripts/DkSearch/dksus.dll?Detail&itemSeq=255687905&uq=636573322862249726) | CAP 22pF 0603 | DIGIKEY | $0.0320 | $0.0143
0 | 1 | 10, 10 | X2 | XTAL3215 | CRYSTAL 32.768KHz | EBAY | $2.1600 | $2.1600
0 | 1 | 1, 10 | X5 | 3220-10-0300-00 (https://www.digikey.com/scripts/DkSearch/dksus.dll?Detail&itemSeq=255577954&uq=636573292806079726) | SWD 10PIN CONNECTOR | DIGIKEY | $0.6100 | $0.5700
0 | 1 | 1, 10 | U2 | AP2112K-3.3TRG1 (https://www.digikey.com/scripts/DkSearch/dksus.dll?Detail&itemSeq=255007807&uq=636573292806059726) | VOLTAGE REGULATOR | DIGIKEY | $0.4800 | $0.3620
0 | 1 | 1, 25 | U$4 | ATSAMD21G18A-MU (https://www.digikey.com/scripts/DkSearch/dksus.dll?Detail&itemSeq=255008032&uq=636573292806069726) | ATSAMD21G18_QFN | DIGIKEY | $3.1800 | $2.8832
0 | 1 | 1, 10 | D3 | XZCBD54W-1 (https://www.digikey.com/scripts/DkSearch/dksus.dll?Detail&itemSeq=255686028&uq=636573315948419447) | LED BLUE 0805 | DIGIKEY | $0.5000 | $0.3560
0 | 1 | 1, 10 | S1 | JS202011SCQN (https://www.digikey.com/scripts/DkSearch/dksus.dll?Detail&itemSeq=255287263&uq=636573292806069726) | SLIDE SWITCH | DIGIKEY | $0.4800 | $0.4630
1 | 1 | 1, 10 | X1 | S2B-PH-SM4-TB(LF)(SN) (https://www.digikey.com/scripts/DkSearch/dksus.dll?Detail&itemSeq=255006885&uq=636573277011671173) | JSTPH | DIGIKEY | $0.5800 | $0.5470
0 | 1 | 1, 10 | D1 | MBR120LSFT3G (https://www.digikey.com/scripts/DkSearch/dksus.dll?Detail&itemSeq=255007915&uq=636573292806059726) | DIODE | DIGIKEY | $0.4300 | $0.3210
0 | 1 | 1, 10 | U1 | MDBT40 | NRF51822 BLE MODULE | EBAY | $10.5000 | $6.5250
0 | 1 | 1, 25 | U3 | MCP73831T-2ACI/OT (https://www.digikey.com/scripts/DkSearch/dksus.dll?Detail&itemSeq=255007731&uq=636573292806049726) | LIPO CHARGER | DIGIKEY | $0.5900 | $0.4984
0 | 1 | 1, 1 | IC2 | MS5611 | PRESSURE SENSOR | EBAY | $7.4300 | $7.4300
0 | 1 | 1, 10 | CHG | XZMOK54W-1 (https://www.digikey.com/scripts/DkSearch/dksus.dll?Detail&itemSeq=255685923&uq=636573315130419726) | LED ORANGE 0805 | DIGIKEY | $0.4400 | $0.3170
0 | 2 | 10, 25 | D2, L | XZMDK54W-1 (https://www.digikey.com/scripts/DkSearch/dksus.dll?Detail&itemSeq=255686232&uq=636573317079069726) | LED RED 0805 | DIGIKEY | $0.3170 | $0.2428
13 | 1 | 1, 10 | LS1 | SMT-1127-S-R (https://www.digikey.com/scripts/DkSearch/dksus.dll?Detail&itemSeq=255683609&uq=636573305216640966) | SMT-1127-S-R | DIGIKEY | $2.2700 | $2.0630
0 | 3 | 10, 50 | SW1, SW2, SW3 | KMR231NG LFS (https://www.digikey.com/scripts/DkSearch/dksus.dll?Detail&itemSeq=255008508&uq=636573292806069726) | TACT SWITCH | DIGIKEY | $0.4990 | $0.4712
0 | 1 | 1, 10 | IC1 | X9313ZSZ (https://www.digikey.com/scripts/DkSearch/dksus.dll?Detail&itemSeq=255582543&uq=636573277011711177) | DIGIPOT 1K SOIC8 | DIGIKEY | $3.6000 | $3.2370
0 | 1 | 1, 10 | X3 | 10118194-0001LF (https://www.digikey.com/scripts/DkSearch/dksus.dll?Detail&itemSeq=255006924&uq=636573277011681174) | microUSB | DIGIKEY | $0.4600 | $0.4370
0 | 1 | 10, 10 |  |  | PCB AND STENCIL | SEEED | $29.3500 | $2.9350
 |  |  |  | 1570 (https://www.digikey.com/scripts/DkSearch/dksus.dll?Detail&itemSeq=255712800&uq=636573577435916489) | 100 mAh LIPO | DIGIKEY | $5.9500 | $5.9500
 |  |  |  |  |  |  | $70.3230 | $37.9973

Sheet: V3
INSTOCK | REQUIRED QTY | PRICE BREAKS | Parts | MPN | DESCRIPTION | DISTRIBUTER | PRICE @ QTY 1 VARIO | PRICE @ QTY 10 VARIOS | EXTENDED PRICE | EXTENDED PRICE
0 | 3 | 10, 100 | C1, C7, C14 | CL10A105KQ8NNNC (https://www.digikey.com/scripts/DkSearch/dksus.dll?Detail&itemSeq=255687743&uq=636573321888037133) | CAP 1uF 0603 | DIGIKEY | $0.0320 | $0.0143 | $0.10 | $0.04
9 | 1 | 1, 10 | C10 | CL21B104KOANNNC (https://www.digikey.com/scripts/DkSearch/dksus.dll?Detail&itemSeq=255687110&uq=636573319776344879) | CAP 0.1uF 0805 | DIGIKEY | $0.1000 | $0.0290 | $0.10 | $0.03
0 | 2 | 10, 100 | C2, C4 | CL10C220JB8NCNC (https://www.digikey.com/scripts/DkSearch/dksus.dll?Detail&itemSeq=255687905&uq=636573322862249726) | CAP 22pF 0603 | DIGIKEY | $0.0320 | $0.0143 | $0.06 | $0.03
0 | 5 | 10, 100 | C3, C5, C6, C8, C9 | CL21A106KQCLRNC (https://www.digikey.com/scripts/DkSearch/dksus.dll?Detail&itemSeq=255687461&uq=636573320529169726) | CAP 10uF 0805 | DIGIKEY | $0.0700 | $0.0313 | $0.35 | $0.16
0 | 1 | 1, 10 | CHG | XZMOK54W-1 (https://www.digikey.com/scripts/DkSearch/dksus.dll?Detail&itemSeq=255685923&uq=636573315130419726) | LED ORANGE 0805 | DIGIKEY | $0.4400 | $0.3170 | $0.44 | $0.32
0 | 1 | 1, 10 | D1 | MBR120LSFT3G (https://www.digikey.com/scripts/DkSearch/dksus.dll?Detail&itemSeq=255007915&uq=636573292806059726) | DIODE | DIGIKEY | $0.4300 | $0.3210 | $0.43 | $0.32
0 | 2 | 10, 25 | D2, L | XZMDK54W-1 (https://www.digikey.com/scripts/DkSearch/dksus.dll?Detail&itemSeq=255686232&uq=636573317079069726) | LED RED 0805 | DIGIKEY | $0.3170 | $0.2428 | $0.63 | $0.49
0 | 1 | 1, 10 | D3 | XZCBD54W-1 (https://www.digikey.com/scripts/DkSearch/dksus.dll?Detail&itemSeq=255686028&uq=636573315948419447) | LED BLUE 0805 | DIGIKEY | $0.5000 | $0.3560 | $0.50 | $0.36
0 | 1 | 1, 10 | IC1 | X9313ZSZ (https://www.digikey.com/scripts/DkSearch/dksus.dll?Detail&itemSeq=255582543&uq=636573277011711177) | DIGIPOT 1K SOIC8 | DIGIKEY | $3.6000 | $3.2370 | $3.60 | $3.24
0 | 1 | 1, 1 | IC2 | MS5611 | PRESSURE SENSOR | EBAY | $7.4300 | $7.4300 | $7.43 | $7.43
13 | 1 | 1, 10 | LS1 | SMT-1127-S-R (https://www.digikey.com/scripts/DkSearch/dksus.dll?Detail&itemSeq=255683609&uq=636573305216640966) | SMT-1127-S-R | DIGIKEY | $2.2700 | $2.0630 | $2.27 | $2.06
0 | 1 | 1, 10 | Q1 | MMBT2222LT1G (https://www.digikey.com/product-detail/en/on-semiconductor/MMBT2222LT1G/MMBT2222LT1GOSCT-ND/1139808) | NPN SOT23 | DIGIKEY | $0.1300 | $0.1150 | $0.13 | $0.12
0 | 3 | 10, 100 | R1, R3, R6 | RC0603JR-07100KL (https://www.digikey.com/scripts/DkSearch/dksus.dll?Detail&itemSeq=255688809&uq=636573327832494815) | RES 100K 0603 | DIGIKEY | $0.0110 | $0.0046 | $0.03 | $0.01
0 | 4 | 10, 100 | R2, R5, R9, R11 | RC0603JR-071KL (https://www.digikey.com/scripts/DkSearch/dksus.dll?Detail&itemSeq=255689053&uq=636573329310919726) | RES 1K 0603 | DIGIKEY | $0.0110 | $0.0046 | $0.04 | $0.02
0 | 3 | 10, 100 | R4, R7, R10 | RC0603JR-072K2L (https://www.digikey.com/scripts/DkSearch/dksus.dll?Detail&itemSeq=255689221&uq=636573330063847928) | RES 2.2K 0603 | DIGIKEY | $0.0110 | $0.0046 | $0.03 | $0.01
0 | 1 | 1, 10 | R8 | RC0603JR-0710KL (https://www.digikey.com/scripts/DkSearch/dksus.dll?Detail&itemSeq=255688956&uq=636573328681559713) | RES 10K 0603 | DIGIKEY | $0.1000 | $0.0110 | $0.10 | $0.01
0 | 1 | 1, 10 | S2 | PCM12SMTR (https://www.digikey.com/scripts/DkSearch/dksus.dll?Detail&itemSeq=255287263&uq=636573292806069726) | SLIDE SWITCH | DIGIKEY | $0.9100 | $0.8700 | $0.91 | $0.87
0 | 1 | 1, 10 | SW1 | KMR231NG LFS (https://www.digikey.com/scripts/DkSearch/dksus.dll?Detail&itemSeq=255008508&uq=636573292806069726) | TACT SWITCH | DIGIKEY | $0.5200 | $0.4990 | $0.52 | $0.50
0 | 1 | 1, 25 | U$4 | ATSAMD21G18A-MU (https://www.digikey.com/scripts/DkSearch/dksus.dll?Detail&itemSeq=255008032&uq=636573292806069726) | ATSAMD21G18_QFN | DIGIKEY | $3.1800 | $2.8832 | $3.18 | $2.88
0 | 1 | 1, 10 | U1 | MDBT40 | NRF51822 BLE MODULE | EBAY | $10.5000 | $6.5250 | $10.50 | $6.53
0 | 1 | 1, 10 | U2 | AP2112K-3.3TRG1 (https://www.digikey.com/scripts/DkSearch/dksus.dll?Detail&itemSeq=255007807&uq=636573292806059726) | VOLTAGE REGULATOR | DIGIKEY | $0.4800 | $0.3620 | $0.48 | $0.36
0 | 2 | 10, 25 | U25, U41 | EVQ-P7A01P (https://www.digikey.com/scripts/DkSearch/dksus.dll?Detail&itemSeq=255882403&uq=636583008495157306) | TACT SWITCH RA | DIGIKEY | $0.2850 | $0.2748 | $0.57 | $0.55
0 | 1 | 1, 25 | U3 | MCP73831T-2ACI/OT (https://www.digikey.com/scripts/DkSearch/dksus.dll?Detail&itemSeq=255007731&uq=636573292806049726) | LIPO CHARGER | DIGIKEY | $0.5900 | $0.4984 | $0.59 | $0.50
1 | 1 | 1, 10 | X1 | S2B-PH-SM4-TB(LF)(SN) (https://www.digikey.com/scripts/DkSearch/dksus.dll?Detail&itemSeq=255006885&uq=636573277011671173) | JSTPH | DIGIKEY | $0.5800 | $0.5470 | $0.58 | $0.55
0 | 1 | 10, 10 | X2 | FC-135 32.7680KA-A5 (https://www.digikey.com/scripts/DkSearch/dksus.dll?Detail&itemSeq=256670207&uq=636583008495177308) | CRYSTAL 32.768KHz | DIGIKEY | $0.5900 | $0.4950 | $0.59 | $0.49
0 | 1 | 1, 10 | X3 | 10118194-0001LF (https://www.digikey.com/scripts/DkSearch/dksus.dll?Detail&itemSeq=255006924&uq=636573277011681174) | microUSB | DIGIKEY | $0.4600 | $0.4370 | $0.46 | $0.44
0 | 1 | 1, 10 | X5 | 3220-10-0300-00 (https://www.digikey.com/scripts/DkSearch/dksus.dll?Detail&itemSeq=255577954&uq=636573292806079726) | SWD 10PIN CONNECTOR | DIGIKEY | $0.6100 | $0.5700 | $0.61 | $0.57
0 | 1 | 10, 10 |  |  | PCB AND STENCIL | SEEED | $29.3500 | $2.9350 | $29.35 | $2.94
0 | 1 | 1, 1 |  | 1570 (https://www.digikey.com/scripts/DkSearch/dksus.dll?Detail&itemSeq=255712800&uq=636573577435916489) | 100 mAh LIPO | DIGIKEY | $5.9500 | $5.9500 | $5.95 | $5.95
 |  |  |  |  |  |  |  |  | $70.5440 | $37.7598

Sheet: V4
QTY REQUIRED | QTY PURCHASED | PRICE BREAKS | Parts | MPN | DESCRIPTION | DISTRIBUTER | PRICE @ QTY 1 VARIO | PRICE @ QTY 10 VARIOS | EXTENDED PRICE | PRICE @ QTY PURCHASED | PRICE PER VARIO
3 | 30 | 10, 100 | C1, C7, C14 | CL10A105KQ8NNNC (https://www.digikey.com/scripts/DkSearch/dksus.dll?Detail&itemSeq=255687743&uq=636573321888037133) | CAP 1uF 0603 | DIGIKEY | $0.0320 | $0.0143 | $0.10 | $0.9600 | $0.10
1 | 10 | 1, 10 | C10 | CL21B104KOANNNC (https://www.digikey.com/scripts/DkSearch/dksus.dll?Detail&itemSeq=255687110&uq=636573319776344879) | CAP 0.1uF 0805 | DIGIKEY | $0.1000 | $0.0290 | $0.10 | $0.2900 | $0.03
2 | 20 | 10, 100 | C2, C4 | CL10C220JB8NCNC (https://www.digikey.com/scripts/DkSearch/dksus.dll?Detail&itemSeq=255687905&uq=636573322862249726) | CAP 22pF 0603 | DIGIKEY | $0.0320 | $0.0143 | $0.06 | $0.6400 | $0.06
5 | 50 | 10, 100 | C3, C5, C6, C8, C9 | CL21A106KQCLRNC (https://www.digikey.com/scripts/DkSearch/dksus.dll?Detail&itemSeq=255687461&uq=636573320529169726) | CAP 10uF 0805 | DIGIKEY | $0.0700 | $0.0313 | $0.35 | $3.5000 | $0.35
1 | 10 | 1, 10 | CHG | XZMOK54W-1 (https://www.digikey.com/scripts/DkSearch/dksus.dll?Detail&itemSeq=255685923&uq=636573315130419726) | LED ORANGE 0805 | DIGIKEY | $0.4400 | $0.3170 | $0.44 | $3.1700 | $0.32
1 | 10 | 1, 10 | D1 | MBR120LSFT3G (https://www.digikey.com/scripts/DkSearch/dksus.dll?Detail&itemSeq=255007915&uq=636573292806059726) | DIODE | DIGIKEY | $0.4300 | $0.3210 | $0.43 | $3.2100 | $0.32
2 | 25 | 10, 25 | D2, L | XZMDK54W-1 (https://www.digikey.com/scripts/DkSearch/dksus.dll?Detail&itemSeq=255686232&uq=636573317079069726) | LED RED 0805 | DIGIKEY | $0.3170 | $0.2428 | $0.63 | $6.0700 | $0.61
1 | 10 | 1, 10 | D3 | XZCBD54W-1 (https://www.digikey.com/scripts/DkSearch/dksus.dll?Detail&itemSeq=255686028&uq=636573315948419447) | LED BLUE 0805 | DIGIKEY | $0.5000 | $0.3560 | $0.50 | $3.5600 | $0.36
1 | 10 | 1, 10 | IC1 | X9313ZSZ (https://www.digikey.com/scripts/DkSearch/dksus.dll?Detail&itemSeq=255582543&uq=636573277011711177) | DIGIPOT 1K SOIC8 | DIGIKEY | $3.6000 | $3.2370 | $3.60 | $32.3700 | $3.24
1 | 10 | 1, 1 | IC2 | MS5611 | PRESSURE SENSOR | EBAY | $7.4300 | $7.4300 | $7.43 | $74.3000 | $7.43
1 | 10 | 1, 10 | LS1 | SMT-1127-S-R (https://www.digikey.com/scripts/DkSearch/dksus.dll?Detail&itemSeq=255683609&uq=636573305216640966) | SMT-1127-S-R | DIGIKEY | $2.2700 | $2.0630 | $2.27 | $20.6300 | $2.06
1 | 10 | 1, 10 | Q1 | MMBT2222LT1G (https://www.digikey.com/product-detail/en/on-semiconductor/MMBT2222LT1G/MMBT2222LT1GOSCT-ND/1139808) | NPN SOT23 | DIGIKEY | $0.1300 | $0.1150 | $0.13 | $1.1500 | $0.12
3 | 30 | 10, 100 | R1, R3, R6 | RC0603JR-07100KL (https://www.digikey.com/scripts/DkSearch/dksus.dll?Detail&itemSeq=255688809&uq=636573327832494815) | RES 100K 0603 | DIGIKEY | $0.0110 | $0.0046 | $0.03 | $0.3300 | $0.03
4 | 40 | 10, 100 | R2, R5, R9, R11 | RC0603JR-071KL (https://www.digikey.com/scripts/DkSearch/dksus.dll?Detail&itemSeq=255689053&uq=636573329310919726) | RES 1K 0603 | DIGIKEY | $0.0110 | $0.0046 | $0.04 | $0.4400 | $0.04
3 | 30 | 10, 100 | R4, R7, R10 | RC0603JR-072K2L (https://www.digikey.com/scripts/DkSearch/dksus.dll?Detail&itemSeq=255689221&uq=636573330063847928) | RES 2.2K 0603 | DIGIKEY | $0.0110 | $0.0046 | $0.03 | $0.3300 | $0.03
1 | 10 | 1, 10 | R8 | RC0603JR-0710KL (https://www.digikey.com/scripts/DkSearch/dksus.dll?Detail&itemSeq=255688956&uq=636573328681559713) | RES 10K 0603 | DIGIKEY | $0.1000 | $0.0110 | $0.10 | $0.1100 | $0.01
1 | 10 | 1, 10 | S2 | PCM12SMTR (https://www.digikey.com/scripts/DkSearch/dksus.dll?Detail&itemSeq=255287263&uq=636573292806069726) | SLIDE SWITCH | DIGIKEY | $0.9100 | $0.8700 | $0.91 | $8.7000 | $0.87
1 | 10 | 1, 10 | SW1 | KMR231NG LFS (https://www.digikey.com/scripts/DkSearch/dksus.dll?Detail&itemSeq=255008508&uq=636573292806069726) | TACT SWITCH | DIGIKEY | $0.5200 | $0.4990 | $0.52 | $4.9900 | $0.50
1 | 10 | 1, 25 | U$4 | ATSAMD21G18A-MU (https://www.digikey.com/scripts/DkSearch/dksus.dll?Detail&itemSeq=255008032&uq=636573292806069726) | ATSAMD21G18_QFN | DIGIKEY | $3.1800 | $2.8832 | $3.18 | $31.8000 | $3.18
1 | 10 | 1, 10 | U1 | MDBT40 | NRF51822 BLE MODULE | EBAY | $10.5000 | $6.5250 | $10.50 | $65.2500 | $6.53
1 | 10 | 1, 10 | U2 | AP2112K-3.3TRG1 (https://www.digikey.com/scripts/DkSearch/dksus.dll?Detail&itemSeq=255007807&uq=636573292806059726) | VOLTAGE REGULATOR | DIGIKEY | $0.4800 | $0.3620 | $0.48 | $3.6200 | $0.36
2 | 25 | 10, 25 | U25, U41 | EVQ-P7A01P (https://www.digikey.com/scripts/DkSearch/dksus.dll?Detail&itemSeq=255882403&uq=636583008495157306) | TACT SWITCH RA | DIGIKEY | $0.2850 | $0.2748 | $0.57 | $6.8700 | $0.69
1 | 10 | 1, 25 | U3 | MCP73831T-2ACI/OT (https://www.digikey.com/scripts/DkSearch/dksus.dll?Detail&itemSeq=255007731&uq=636573292806049726) | LIPO CHARGER | DIGIKEY | $0.5900 | $0.4984 | $0.59 | $5.9000 | $0.59
1 | 10 | 1, 10 | X1 | S2B-PH-SM4-TB(LF)(SN) (https://www.digikey.com/scripts/DkSearch/dksus.dll?Detail&itemSeq=255006885&uq=636573277011671173) | JSTPH | DIGIKEY | $0.5800 | $0.5470 | $0.58 | $5.4700 | $0.55
1 | 10 | 1, 10 | X2 | FC-135 32.7680KA-A5 (https://www.digikey.com/scripts/DkSearch/dksus.dll?Detail&itemSeq=256670207&uq=636583008495177308) | CRYSTAL 32.768KHz | DIGIKEY | $0.5900 | $0.4950 | $0.59 | $4.9500 | $0.49
1 | 10 | 1, 10 | X3 | 10118193-0001LF (https://www.digikey.com/scripts/DkSearch/dksus.dll?Detail&itemSeq=260619861&uq=636617232035274916) | microUSB | DIGIKEY | $0.4200 | $0.3930 | $0.42 | $3.9300 | $0.39
1 | 10 | 10, 10 |  |  | PCB AND STENCIL | SEEED | $29.3500 | $2.9350 | $29.35 | $29.3500 | $2.94
1 | 10 | 1, 1 |  | 1570 (https://www.digikey.com/scripts/DkSearch/dksus.dll?Detail&itemSeq=255712800&uq=636573577435916489) | 100 mAh LIPO | DIGIKEY | $5.9500 | $5.9500 | $5.95 | $59.5000 | $5.95
1 | 5 |  |  |  | VELCRO WRAP | EBAY |  |  |  | $23.3500 | $2.33
1 | 5 |  |  |  | VELCRO STICKY | EBAY |  |  |  | $14.2500 | $1.43
1 | 2 |  |  |  | MOUNTING LEASH | EBAY |  |  |  | $11.2000 | $1.12
 | 10 | 1, 1 |  |  | USB CABLE | EBAY |  |  |  | $9.1000 | $0.91
 |  |  |  |  | DIGIKEY SHIPPING | DIGIKEY |  |  |  | $8.9900 | $0.90
 |  |  |  |  | DIGIKEY SALES TAX | DIGIKEY |  |  |  | $2.5900 | $0.26
 |  |  |  |  |  |  |  |  | $69.8940 | PRODUCTION | $45.0870
 |  |  |  |  |  |  |  |  |  | SELL PRICE | $99.00
 |  |  |  |  |  |  |  |  |  | LISTING FEES | $13.37
 |  |  |  |  |  |  |  |  |  | PROFIT | $40.55
 |  |  |  |  |  |  |  |  |  | INVESTMENT | $448.28
 |  |  |  |  |  |  |  |  |  | GROSS | $856.35
 |  |  |  |  |  |  |  |  |  | NET | $408.07

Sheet: SALES PLAN
DESCRIPTION | Parts | MPN | DISTRIBUTER | REQUIRED QTY | INVENTORY | NEED | INVEST | NEW INVENTORY | SELL | INVENTORY | NEED | INVEST | NEW INVENTORY | SELL | INVENTORY | NEED | INVEST | NEW INVENTORY | SELL | INVENTORY
CAP 1uF 0603 | C1, C7, C14 | CL10A105KQ8NNNC (https://www.digikey.com/scripts/DkSearch/dksus.dll?Detail&itemSeq=255687743&uq=636573321888037133) | DIGIKEY | 3 | 4 |  |  | 4 | 1 | 1 | 100 | $1.43 | 101 | 1 | 98 |  |  | 98 | 3 | 89
CAP 0.1uF 0805 | C10 | CL21B104KOANNNC (https://www.digikey.com/scripts/DkSearch/dksus.dll?Detail&itemSeq=255687110&uq=636573319776344879) | DIGIKEY | 1 | 8 |  |  | 8 |  | 7 |  |  | 7 |  | 6 |  |  | 6 |  | 3
CAP 22pF 0603 | C2, C4 | CL10C220JB8NFNC (https://www.digikey.com/scripts/DkSearch/dksus.dll?Detail&itemSeq=255687905&uq=636573322862249726) | DIGIKEY | 2 | 6 |  |  | 6 |  | 4 |  |  | 4 |  | 2 | 100 | $2.23 | 102 |  | 96
CAP 10uF 0805 | C3, C5, C6, C8, C9 | CL21A106KQCLRNC (https://www.digikey.com/scripts/DkSearch/dksus.dll?Detail&itemSeq=255687461&uq=636573320529169726) | DIGIKEY | 5 | 0 | 100 | $4.44 | 100 |  | 95 |  |  | 95 |  | 90 |  |  | 90 |  | 75
LED ORANGE 0805 | CHG | XZMOK54W-1 (https://www.digikey.com/scripts/DkSearch/dksus.dll?Detail&itemSeq=255685923&uq=636573315130419726) | DIGIKEY | 1 | 9 |  |  | 9 |  | 8 |  |  | 8 |  | 7 |  |  | 7 |  | 4
DIODE | D1 | MBR120LSFT3G (https://www.digikey.com/scripts/DkSearch/dksus.dll?Detail&itemSeq=255007915&uq=636573292806059726) | DIGIKEY | 1 | 0 | 10 | $3.21 | 10 |  | 9 |  |  | 9 |  | 8 |  |  | 8 |  | 5
LED RED 0805 | D2, L | XZMDK54W-1 (https://www.digikey.com/scripts/DkSearch/dksus.dll?Detail&itemSeq=255686232&uq=636573317079069726) | DIGIKEY | 2 | 18 |  |  | 18 |  | 16 |  |  | 16 |  | 14 |  |  | 14 |  | 8
LED BLUE 0805 | D3 | XZCBD54W-1 (https://www.digikey.com/scripts/DkSearch/dksus.dll?Detail&itemSeq=255686028&uq=636573315948419447) | DIGIKEY | 1 | 9 |  |  | 9 |  | 8 |  |  | 8 |  | 7 |  |  | 7 |  | 4
DIGIPOT 1K SOIC8 | IC1 | X9313ZSZ (https://www.digikey.com/scripts/DkSearch/dksus.dll?Detail&itemSeq=255582543&uq=636573277011711177) | DIGIKEY | 1 | 0 | 1 | $3.60 | 1 |  | 0 | 10 | $32.37 | 10 |  | 9 |  |  | 9 |  | 6
SMT-1127-S-R | LS1 | SMT-1127-S-R (https://www.digikey.com/scripts/DkSearch/dksus.dll?Detail&itemSeq=255683609&uq=636573305216640966) | DIGIKEY | 1 | 9 |  |  | 9 |  | 8 |  |  | 8 |  | 7 |  |  | 7 |  | 4
NPN SOT23 | Q1 | MMBT2222LT1G (https://www.digikey.com/product-detail/en/on-semiconductor/MMBT2222LT1G/MMBT2222LT1GOSCT-ND/1139808) | DIGIKEY | 1 | 0 | 10 | $1.18 | 10 |  | 9 |  |  | 9 |  | 8 |  |  | 8 |  | 5
RES 100K 0603 | R1, R3, R6 | RC0603JR-07100KL (https://www.digikey.com/scripts/DkSearch/dksus.dll?Detail&itemSeq=255688809&uq=636573327832494815) | DIGIKEY | 3 | 4 |  |  | 4 |  | 1 | 100 | $0.51 | 101 |  | 98 |  |  | 98 |  | 89
RES 1K 0603 | R2, R5, R9, R11 | RC0603JR-071KL (https://www.digikey.com/scripts/DkSearch/dksus.dll?Detail&itemSeq=255689053&uq=636573329310919726) | DIGIKEY | 4 | 2 | 100 | $0.51 | 102 |  | 98 |  |  | 98 |  | 94 |  |  | 94 |  | 82
RES 2.2K 0603 | R4, R7, R10 | RC0603JR-072K2L (https://www.digikey.com/scripts/DkSearch/dksus.dll?Detail&itemSeq=255689221&uq=636573330063847928) | DIGIKEY | 3 | 4 |  |  | 4 |  | 1 | 100 | $0.51 | 101 |  | 98 |  |  | 98 |  | 89
RES 10K 0603 | R8 | RC0603JR-0710KL (https://www.digikey.com/scripts/DkSearch/dksus.dll?Detail&itemSeq=255688956&uq=636573328681559713) | DIGIKEY | 1 | 8 |  |  | 8 |  | 7 |  |  | 7 |  | 6 |  |  | 6 |  | 3
SLIDE SWITCH | S2 | PCM12SMTR (https://www.digikey.com/scripts/DkSearch/dksus.dll?Detail&itemSeq=255287263&uq=636573292806069726) | DIGIKEY | 1 | 0 | 1 | $0.91 | 1 |  | 0 | 10 | $8.70 | 10 |  | 9 |  |  | 9 |  | 6
TACT SWITCH | SW1 | KMR231NG LFS (https://www.digikey.com/scripts/DkSearch/dksus.dll?Detail&itemSeq=255008508&uq=636573292806069726) | DIGIKEY | 1 | 0 | 1 | $0.52 | 1 |  | 0 | 10 | $4.99 | 10 |  | 9 |  |  | 9 |  | 6
ATSAMD21G18_QFN | U$4 | ATSAMD21G18A-MU (https://www.digikey.com/scripts/DkSearch/dksus.dll?Detail&itemSeq=255008032&uq=636573292806069726) | DIGIKEY | 1 | 0 | 1 | $3.09 | 1 |  | 0 | 1 | $3.09 | 1 |  | 0 | 3 | $9.27 | 3 |  | 0
VOLTAGE REGULATOR | U2 | AP2112K-3.3TRG1 (https://www.digikey.com/scripts/DkSearch/dksus.dll?Detail&itemSeq=255007807&uq=636573292806059726) | DIGIKEY | 1 | 0 | 10 | $3.62 | 10 |  | 9 |  |  | 9 |  | 8 |  |  | 8 |  | 5
TACT SWITCH RA | U25, U41 | EVQ-P7A01P (https://www.digikey.com/scripts/DkSearch/dksus.dll?Detail&itemSeq=255882403&uq=636583008495157306) | DIGIKEY | 2 | 0 | 10 | $2.85 | 10 |  | 8 |  |  | 8 |  | 6 |  |  | 6 |  | 0
LIPO CHARGER | U3 | MCP73831T-2ACI/OT (https://www.digikey.com/scripts/DkSearch/dksus.dll?Detail&itemSeq=255007731&uq=636573292806049726) | DIGIKEY | 1 | 0 | 10 | $5.80 | 9 |  | 8 |  |  | 8 |  | 7 |  |  | 7 |  | 4
JSTPH | X1 | S2B-PH-SM4-TB(LF)(SN) (https://www.digikey.com/scripts/DkSearch/dksus.dll?Detail&itemSeq=255006885&uq=636573277011671173) | DIGIKEY | 1 | 0 | 1 | $0.58 | 1 |  | 0 | 10 | $5.47 | 10 |  | 9 |  |  | 9 |  | 6
CRYSTAL 32.768KHz | X2 | FC-135 32.7680KA-A5 (https://www.digikey.com/scripts/DkSearch/dksus.dll?Detail&itemSeq=256670207&uq=636583008495177308) | DIGIKEY | 1 | 0 | 10 | $4.95 | 10 |  | 9 |  |  | 9 |  | 8 |  |  | 8 |  | 5
microUSB | X3 | 10118193-0001LF (https://www.digikey.com/scripts/DkSearch/dksus.dll?Detail&itemSeq=260619861&uq=636617232035274916) | DIGIKEY | 1 | 0 | 1 | $0.42 | 1 |  | 0 | 10 | $3.93 | 10 |  | 9 |  |  | 9 |  | 6
150 mAh LIPO |  | 1317 (https://www.digikey.com/scripts/DkSearch/dksus.dll?Detail&itemSeq=255712800&uq=636573577435916489) | DIGIKEY | 1 | 0 | 1 | $5.95 | 1 |  | 0 | 1 | $5.95 | 1 |  | 0 | 3 | $17.85 | 3 |  | 0
PCB AND STENCIL |  |  | SEEED | 1 | 8 |  |  | 7 |  | 6 |  |  | 6 |  | 0 | 10 | $24.17 | 10 |  | 7
PRESSURE SENSOR | IC2 | MS5611 | EBAY | 1 | 0 | 2 | $13.03 | 2 |  | 2 |  |  | 2 |  | 1 | 5 | $29.80 | 6 |  | 3
NRF51822 BLE MODULE | U1 | MDBT40 | EBAY | 1 | 0 | 4 | $35.32 | 2 |  | 1 |  |  | 1 |  | 0 | 5 | $36.25 | 5 |  | 2
IPA WIPES |  |  | EBAY | 1 | 0 | 100 | $3.66 | 100 |  | 99 |  |  | 99 |  | 98 |  |  | 98 |  | 95
VELCRO WRAP |  |  | EBAY | 1 | 1 | 2 | $4.67 | 3 |  | 2 |  |  | 2 |  | 0 | 4 | $9.34 | 4 |  | 1
VELCRO STICKY |  |  | EBAY | 1 | 2 |  |  | 2 |  | 128 |  |  | 128 |  | 127 |  |  | 127 |  | 124
MOUNTING LEASH |  |  | EBAY | 1 | 3 |  |  | 3 |  | 1 |  |  | 1 |  | 0 | 25 | $12.71 | 25 |  | 21
USB CABLE |  |  | EBAY | 1 | 0 | 1 | $0.88 | 1 |  | 0 | 10 | $8.80 | 10 |  | 9 |  |  | 9 |  | 6
M2 X 10 BOLTS |  |  | EBAY | 4 | 26 |  |  | 26 |  | 22 |  |  | 22 |  | 0 | 20 | $6.26 | 20 |  | 8
DIGIKEY SHIPPING |  |  | DIGIKEY |  |  | SHIPPING | $8.99 |  |  |  | SHIPPING | $8.99 |  |  |  | SHIPPING | $8.99
EBAY LISTING FEE |  |  |  |  |  |  | $8.00 |  |  |  |  | $9.90 |  |  |  | EBAY | $29.70
PAYPAL FEE |  |  |  |  |  |  | $2.62 |  |  |  |  | $3.17 |  |  |  | PAYPAL | $9.50
FIRST CLASS SHIPPING |  |  |  |  |  |  | $2.66 |  |  |  |  | $2.79 |  |  |  | FIRST CLASS | $8.37
DIGIKEY SALES TAX |  |  | DIGIKEY | 5.37% |  | SALES TAX | $2.24 |  |  |  | SALES TAX | $3.60 |  |  |  | SALES TAX | $2.01
SPENDINGS/EARNINGS |  |  |  |  |  | EXPENSES | -$123.70 | INCOME | $69.20 |  | EXPENSES | -$104.20 | INCOME | $99.00 |  | EXPENSES | -$206.45 | INCOME | $297.00
PROFIT |  |  |  |  |  |  |  | INVEST | -$54.50 |  |  |  | PROFIT | -$5.20 |  |  |  | PROFIT | $90.55
 |  |  |  |  | PHASE 1 |  |  |  |  | PHASE 2 |  |  |  |  | PHASE 3
 |  |  |  |  |  | SELL PRICE: | $80.00

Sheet: Just One More Build
DESCRIPTION | Parts | MPN | DISTRIBUTER | REQUIRED QTY | INVENTORY | NEED | INVEST | NEW INVENTORY | SELL
CAP 1uF 0603 | C1, C7, C14 | CL10A105KQ8NNNC (https://www.digikey.com/scripts/DkSearch/dksus.dll?Detail&itemSeq=255687743&uq=636573321888037133) | DIGIKEY | 3 | 4 |  |  | 4 | 1
CAP 0.1uF 0805 | C10 | CL21B104KOANNNC (https://www.digikey.com/scripts/DkSearch/dksus.dll?Detail&itemSeq=255687110&uq=636573319776344879) | DIGIKEY | 1 | 8 |  |  | 8
CAP 22pF 0603 | C2, C4 | CL10C220JB8NCNC (https://www.digikey.com/scripts/DkSearch/dksus.dll?Detail&itemSeq=255687905&uq=636573322862249726) | DIGIKEY | 2 | 6 |  |  | 6
CAP 10uF 0805 | C3, C5, C6, C8, C9 | CL21A106KQCLRNC (https://www.digikey.com/scripts/DkSearch/dksus.dll?Detail&itemSeq=255687461&uq=636573320529169726) | DIGIKEY | 5 | 0 | 100 | $4.44 | 100
LED ORANGE 0805 | CHG | XZMOK54W-1 (https://www.digikey.com/scripts/DkSearch/dksus.dll?Detail&itemSeq=255685923&uq=636573315130419726) | DIGIKEY | 1 | 9 |  |  | 9
DIODE | D1 | MBR120LSFT3G (https://www.digikey.com/scripts/DkSearch/dksus.dll?Detail&itemSeq=255007915&uq=636573292806059726) | DIGIKEY | 1 | 0 | 10 | $3.21 | 10
LED RED 0805 | D2, L | XZMDK54W-1 (https://www.digikey.com/scripts/DkSearch/dksus.dll?Detail&itemSeq=255686232&uq=636573317079069726) | DIGIKEY | 2 | 18 |  |  | 18
LED BLUE 0805 | D3 | XZCBD54W-1 (https://www.digikey.com/scripts/DkSearch/dksus.dll?Detail&itemSeq=255686028&uq=636573315948419447) | DIGIKEY | 1 | 9 |  |  | 9
DIGIPOT 1K SOIC8 | IC1 | X9313ZSZ (https://www.digikey.com/scripts/DkSearch/dksus.dll?Detail&itemSeq=255582543&uq=636573277011711177) | DIGIKEY | 1 | 0 | 1 | $3.60 | 1
SMT-1127-S-R | LS1 | SMT-1127-S-R (https://www.digikey.com/scripts/DkSearch/dksus.dll?Detail&itemSeq=255683609&uq=636573305216640966) | DIGIKEY | 1 | 9 |  |  | 9
NPN SOT23 | Q1 | MMBT2222LT1G (https://www.digikey.com/product-detail/en/on-semiconductor/MMBT2222LT1G/MMBT2222LT1GOSCT-ND/1139808) | DIGIKEY | 1 | 0 | 10 | $1.18 | 10
RES 100K 0603 | R1, R3, R6 | RC0603JR-07100KL (https://www.digikey.com/scripts/DkSearch/dksus.dll?Detail&itemSeq=255688809&uq=636573327832494815) | DIGIKEY | 3 | 4 |  |  | 4
RES 1K 0603 | R2, R5, R9, R11 | RC0603JR-071KL (https://www.digikey.com/scripts/DkSearch/dksus.dll?Detail&itemSeq=255689053&uq=636573329310919726) | DIGIKEY | 4 | 2 | 100 | $0.51 | 102
RES 2.2K 0603 | R4, R7, R10 | RC0603JR-072K2L (https://www.digikey.com/scripts/DkSearch/dksus.dll?Detail&itemSeq=255689221&uq=636573330063847928) | DIGIKEY | 3 | 4 |  |  | 4
RES 10K 0603 | R8 | RC0603JR-0710KL (https://www.digikey.com/scripts/DkSearch/dksus.dll?Detail&itemSeq=255688956&uq=636573328681559713) | DIGIKEY | 1 | 8 |  |  | 8
SLIDE SWITCH | S2 | PCM12SMTR (https://www.digikey.com/scripts/DkSearch/dksus.dll?Detail&itemSeq=255287263&uq=636573292806069726) | DIGIKEY | 1 | 0 | 1 | $0.91 | 1
TACT SWITCH | SW1 | KMR231NG LFS (https://www.digikey.com/scripts/DkSearch/dksus.dll?Detail&itemSeq=255008508&uq=636573292806069726) | DIGIKEY | 1 | 0 | 1 | $0.52 | 1
ATSAMD21G18_QFN | U$4 | ATSAMD21G18A-MU (https://www.digikey.com/scripts/DkSearch/dksus.dll?Detail&itemSeq=255008032&uq=636573292806069726) | DIGIKEY | 1 | 0 | 1 | $3.09 | 1
VOLTAGE REGULATOR | U2 | AP2112K-3.3TRG1 (https://www.digikey.com/scripts/DkSearch/dksus.dll?Detail&itemSeq=255007807&uq=636573292806059726) | DIGIKEY | 1 | 0 | 10 | $3.62 | 10
TACT SWITCH RA | U25, U41 | EVQ-P7A01P (https://www.digikey.com/scripts/DkSearch/dksus.dll?Detail&itemSeq=255882403&uq=636583008495157306) | DIGIKEY | 2 | 0 | 10 | $2.85 | 10
LIPO CHARGER | U3 | MCP73831T-2ACI/OT (https://www.digikey.com/scripts/DkSearch/dksus.dll?Detail&itemSeq=255007731&uq=636573292806049726) | DIGIKEY | 1 | 0 | 10 | $5.80 | 10
JSTPH | X1 | S2B-PH-SM4-TB(LF)(SN) (https://www.digikey.com/scripts/DkSearch/dksus.dll?Detail&itemSeq=255006885&uq=636573277011671173) | DIGIKEY | 1 | 0 | 1 | $0.58 | 1
CRYSTAL 32.768KHz | X2 | FC-135 32.7680KA-A5 (https://www.digikey.com/scripts/DkSearch/dksus.dll?Detail&itemSeq=256670207&uq=636583008495177308) | DIGIKEY | 1 | 0 | 10 | $4.95 | 10
microUSB | X3 | 10118193-0001LF (https://www.digikey.com/scripts/DkSearch/dksus.dll?Detail&itemSeq=260619861&uq=636617232035274916) | DIGIKEY | 1 | 0 | 1 | $0.42 | 1
150 mAh LIPO |  | 1317 (https://www.digikey.com/scripts/DkSearch/dksus.dll?Detail&itemSeq=255712800&uq=636573577435916489) | DIGIKEY | 1 | 0 | 1 | $5.95 | 1
PCB AND STENCIL |  |  | SEEED | 1 | 8 |  |  | 8
PRESSURE SENSOR | IC2 | MS5611 | EBAY | 1 | 0 | 1 | $7.44 | 1
NRF51822 BLE MODULE | U1 | MDBT40 | EBAY | 1 | 0 | 1 | $8.91 | 1
IPA WIPES |  |  | EBAY | 1 | 0 | 100 | $3.66 | 100
VELCRO WRAP |  |  | EBAY | 1 | 1 |  |  | 1
VELCRO STICKY |  |  | EBAY | 1 | 2 |  |  | 2
MOUNTING LEASH |  |  | EBAY | 1 | 3 |  |  | 3
USB CABLE |  |  | EBAY | 1 | 0 | 1 | $0.88 | 1
DIGIKEY SHIPPING |  |  | DIGIKEY |  |  | SHIPPING | $8.99
DIGIKEY SALES TAX |  |  | DIGIKEY | 5.37% |  | SALES TAX | $2.24
SPENDINGS/EARNINGS |  |  |  |  |  | EXPENSES | -$73.75 | INCOME | $99.00
PROFIT |  |  |  |  |  |  |  | PROFIT | $25.25
 |  |  |  |  | PHASE 1

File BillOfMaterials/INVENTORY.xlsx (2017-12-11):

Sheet: INVENTORY
 | ORDERED | ITEM | INCLUDED | PRICE | SUBTOTAL | SHIP | TAX | ORDER
 | 2017-05-27 | Arduino Nano | 1 | $6.99 | $48.10 | $0.00 |  | $48.10 | $6.99
 |  | BMP180 | 1 | $6.99 |  |  |  |  | $6.99
 |  | LARGE SWITCH | 20 | $4.97 |  |  |  |  | $0.25
 |  | 9V BATTERY CLIPS | 20 | $5.99 |  |  |  |  | $0.30
 |  | PS1240 PIEZO BUZZER | 1 | $6.25 |  |  |  |  | $6.25
 |  | 5 SIZES PCB | 20 | $11.59 |  |  |  |  | $0.58
 |  | B103 10K WHEEL POT | 5 | $5.32 |  |  |  |  | $1.06
 | 2017-05-31 | NOKIA 5110 LCD | 1 | $6.19 | $6.19 | $0.00 |  | $6.19
 | 2017-06-21 | Bluefruit Feather 32U4 | 1 | $33.57 | $33.57 | $0.00 |  | $33.57
 | 2017-06-21 | MS5611 | 1 | $6.56 | $7.55 | $0.00 |  | $7.55
 | 2017-06-21 | SMALL SWITCH | 50 | $0.99
 | 2017-07-08 | BTG 150MAH LIPO | 5 | $12.85 | $12.85 | $0.00 |  | $12.85
 | 2017-07-09 | 3V/3.3V 9x5.5mm Small Active Buzzer Alarm Continuous Beep | 10 | $2.56 | $17.23 | $5.65 |  | $22.88
 |  | 3V 80mA 2700Hz 92dB 9x3.2mm Black Passive Electromagnetic SMD Buzzer | 5 | $1.80
 |  | 8 PIN FEMALE HEADERS | 10 | $3.99
 |  | NOKIA 5110 LCD | 1 | $1.97
 |  | MS5611 | 1 | $6.91
 | 2017-07-11 | JST FEMALE | 1 | $0.75 | $3.44 | $4.99 |  | $8.43
 |  | JST MALE CABLE | 1 | $0.75
 |  | P081S-71F2CAR10K POT SWITCH | 1 | $1.94
 | 2017-07-13 | 0.66 INCH OLED | 1 | $5.22 | $5.22 | $1.97 |  | $7.19
 | 2017-07-13 | PS1740P02E PIEZO TRANSDUCER | 1 | $0.77 | $2.30 | $3.39 |  | $5.69
 |  | 3352T-1-102LF POT 1.0K OHM THUMBWHEEL | 1 | $1.53
 | 2017-07-14 | PROTOTYPE 1.2.4 PCB FROM SEEED | 10 | $4.90 | $4.90 | $10.37 |  | $15.27
 | 2017-07-15 | PROTOTYPE 1.2.4 SHAPEWAYS FRONT CASE | 1 | $5.72 | $8.55 | $4.99 |  | $13.54
 |  | PROTOTYPE 1.2.4 SHAPEWAYS BACK | 1 | $2.83
 | 2017-07-20 | ADJUSTABLE SOLDERING IRON | 1 | $10.58 | $18.65 | $0.25 |  | $18.90
 |  | 830 BREADBOARD + 65X JUMPERS | 1 | $3.86
 |  | SOLERDING IRON STAND | 1 | $1.89
 |  | SOLDERING IRON SPONGE | 10 | $0.94
 |  | 5FT 3MM SOLDERING WICK | 1 | $1.38
 | 2017-09-07 | 3D HUBS (BEN'S HUB) BLACK CASING V2 | 1 | $3.78 | $3.78 | $0.00 |  | $3.78
 | 2017-09-08 | 0.66 INCH OLED (EBAY) | 1 | $4.94 | $4.94 | $1.97 |  | $6.91
 | 2017-09-08 | FEATHER M0 BLUEFRUIT LE (DIGIKEY) | 1 | $29.95 | $34.38 | $3.03 |  | $37.41
 |  | PS1740 PIEZO TRANSDUCER (DIGIKEY) | 1 | $0.77
 |  | POT 1.0K OHM THUMBWHEEL (DIGIKEY) | 1 | $1.53
 | 2017-09-13 | FLYSKYHY IOS APP | 1 | $8.99 | $8.99 | $0.00 |  | $8.99
 | 2017-10-09 | MS5611 (EBAY) | 1 | $4.99 | $4.99 | $1.39 |  | $6.38
 | 2017-10-09 | BREAK AWAY 40 PIN FEMAL HEADER (EBAY) | 10 | $9.05 | $9.05 | $9.05 |  | $9.05
 | 1902-10-15 | 5PCS 40PIN SHORT FEMALE HEADER (EBAY) | 5 | $4.99 | $4.99 | $0.00 |  | $4.99
 | 2017-10-19 | 668 SMT 0931 MAGNETIC BUZZER (DIGIKEY) | 1 | $2.66 | $10.18 | $3.75 |  | $13.93
 |  | POT 1K THUMBWHEEL VERTICAL (DIGIKEY) | 1 | $1.53
 |  | PS1740 PIEZO TRANSDUCER (DIGIKEY) | 1 | $0.77
 |  | X9C102 DIP DIGITAL POT (DIGIKEY) | 1 | $5.22
 | 2017-10-28 | 10PCS DIAL TOGGLE SWITCH (ALIEXPRESS) | 10 | $1.51 | $1.51 | $0.00 |  | $1.51
 | 2017-11-01 | RES 100K OHM 1/4W 5% AXIAL (DIGIKEY) | 10 | $0.40 | $3.58 | $3.39 | $0.25 | $7.22 | TAX
 |  | RES 5.00M OHM 1/2W 1% AXIAL | 1 | $0.90 |  |  |  |  | $0.25
 |  | CAP CER 1UF 50V X5R RADIAL | 2 | $0.64
 |  | RES 30K OHM 1/4W 5% AXIAL | 10 | $0.40
 |  | MJTP1236G SWITCH TACTILE | 1 | $0.32
 |  | SN74HC00N IC GATE NAND 4CH 2-INP 14-DIP | 1 | $0.46
 |  | SN74HC08N IC GATE AND 4CH 2-INP 14-DIP | 1 | $0.46
 | 2017-11-06 | SWITCH TACTILE SPST-NO (DIGIKEY) | 1 | $0.10 | $4.15 | $3.93 | $0.27 | $8.35 | TAX
 |  | RES 1K OHM 1/4W 5% AXIAL | 10 | $0.40 |  |  |  |  | $0.27
 |  | RES 10K OHM 1/4W 5% AXIAL | 10 | $0.40
 |  | RES 200K OHM 1/4W 5% AXIAL | 10 | $0.40
 |  | CAP CER 10UF 25V X7R RADIAL | 1 | $0.63
 |  | DIODE SCHOTTKY 100V 1A DO41 | 1 | $0.55
 |  | ZVNL120A MOSFET N-CH | 1 | $0.86
 |  | TP2104N3-G MOSFET P-CH | 1 | $0.61
 |  | 2N3904BU TRANSISTOR NPN | 1 | $0.20
 |  | (DIGIKEY)
 | 2017-11-25 | RC0805FR-0730KL RES 30K 1% 0805 | 10 | $0.22 | $13.70 | $4.11 | $0.90 | $18.71
 |  | MJTP1236G TACTILE SWITCH | 1 | $0.32
 |  | 74HC00D,652 NAND 14-SO | 1 | $0.36
 |  | 08055C104JAT2A CAP 0.1UF 50V 0805 | 10 | $0.70
 |  | RC0805JR-0710KL RES 10K 5% 0805 | 10 | $0.19
 |  | RC0805JR-071KL RES 1K 5% 0805 | 20 | $0.38
 |  | 2908-05WB-MG MICRO SD SLOT | 1 | $3.60
 |  | AD8400ARZ1 DGTL POT 1K 8BIT 8-SOIC | 1 | $3.31
 |  | MMBT2222ALT1G NPN TRANSISTOR S0T23 | 1 | $0.12
 |  | B3F-3120 TACTILE SWITCH | 1 | $0.44
 |  | 878980426 4POS VERT HEADER SMD | 10 | $2.53
 |  | GEC08SBSN-M89 8POS RT/A HEADER SMD | 1 | $1.53
 |  | (EBAY)
 | 2017-11-24 | 10pcs Black Passive Electromagnetic SMD Buzzer 3V 80mA 2700Hz 92dB 9x3.2mm (https://www.ebay.com/itm/10pcs-Black-Passive-Electromagnetic-SMD-Buzzer-3V-80mA-2700Hz-92dB-9x3-2mm/361907482119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) | 10 | $3.61 | $27.87 | $0.00 | $0.00 | $31.04
 |  | 1PCS MS5611 Pressure Sensor Altimeter Sensor IC M (https://www.ebay.com/itm/1PCS-MS5611-Pressure-Sensor-Altimeter-Sensor-IC-M/191905077800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) | 1 | $5.58 |  | $1.85 | $0.00
 |  | 2.9 inch E-Ink Display e-Paper Module for Raspberry Pi3 Arduino SPI interface SG (https://www.ebay.com/itm/2-9-inch-E-Ink-Display-e-Paper-Module-for-Raspberry-Pi3-Arduino-SPI-interface-SG/112543054022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) | 1 | $18.68 |  | $1.32 | $0.00
 |  | (SEEED)
 | 2017-11-24 | PROTOTYPE4 PCB | 10 | $4.90 | $4.90 | $11.14 | - | $16.04
TODAY: | 2017-12-09 |  |  |  |  | TOTAL |  | $374.47 | IN | 6.4 | MONTHS
 |  |  |  |  |  | AVERAGE |  | $58.11 | PER |  | MONTH
 |  | PRICES BASED ON MY INVENTORY: | (NOT ACCURATE DUE TO QTY AND SHIPPING COSTS)
 | PROTOTYPE1
 |  | Arduino Nano |  | $2.19
 |  | BMP180 |  | $1.06
 |  | NOKIA 5110 LCD |  | $1.97
 |  | LARGE SWITCH |  | $0.25
 |  | 9V BATTERY CLIP |  | $0.30
 |  | 9V BATTERY CLIPS FOR WIRING (ESTIMATE) |  | $1.00
 |  | PS1240 PIEZO BUZZER |  | $6.25
 |  | BLANK PCB |  | $0.58
 |  | B103 10K WHEEL POT |  | $1.06
 |  | 63X100X18MM CARDBOARD BOX (ESTIMATE) |  | $0.50
 |  | 9V BATTERY (ESTIMATE) |  | $2.00
 |  |  |  | $17.16
 | PROTOTYPE2
 |  | PROTOTYPE2 ~~1.2.4~~ PCB FROM SEEED |  | $1.53
 |  | BLUEFRUIT FEATHER 32U4 |  | $33.57
 |  | MS5611 |  | $6.56
 |  | BTG 150MAH LIPO |  | $2.57
 |  | 0.66 INCH OLED |  | $5.22
 |  | 8 PIN FEMALE HEADER |  | $0.40
 |  | PS1740 PIEZO TRANSDUCER |  | $0.77
 |  | SMALL SWITCH |  | $0.02
 |  | PROTOTYPE2 ~~1.2.4~~ SHAPEWAYS FRONT CASE |  | $8.21
 |  | PROTOTYPE2 ~~1.2.4~~ SHAPEWAYS BACK |  | $5.33
 |  | POT 1.0K OHM THUMBWHEEL |  | $1.53
 |  |  |  | $65.71
 | PROTOTYPE3
 |  | PROTOTYPE2 PCB FROM SEEED |  | $1.53
 |  | BLUEFRUIT FEATHER M0 |  | $33.57
 |  | MS5611 |  | $6.56
 |  | 0.66 INCH OLED |  | $6.91
 |  | 8 PIN FEMALE HEADER |  | $0.40
 |  | BTG 150MAH LIPO |  | $2.57
 |  | SMALL SWITCH |  | $0.02
 |  | PS1740 PIEZO TRANSDUCER |  | $0.77
 |  | POT 1.0K OHM THUMBWHEEL |  | $1.53
 |  | BLACK CASE V2 (3D HUBS) |  | $3.78
 |  |  |  | $57.64

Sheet: (OLD) 1.2.4 PCB & PINOUTS
 | A | B | C | D | E | F | G | H | I | J | K | L | M | N | O | P | Q | R | S | T |  | WIRE DESCRIPTION | # | ABR
9 | DUM |  |  |  |  | PEN |  | SCE | RST | DCE | DDC |  |  |  |  |  |  |  |  |  | 9 | BLUEFRUIT FEATHER 3.3V | 1 | 3V3 | B1 | S2 | T7
8 |  |  |  |  |  |  |  |  |  |  |  |  |  |  |  |  |  |  | GND | GND | 8 | GND | 2 | GND | D1 | P3 | S3 | S8 | T8 | I3 | O7
7 |  |  |  |  |  |  |  |  |  |  |  |  | PTB |  | GND | PTB | SIG |  | MIS | 3V3 | 7 | SENSOR MISO / SDO | 3 | MIS | M1 | S7
6 |  |  |  |  |  |  |  |  |  |  |  |  |  |  |  |  |  |  | SCE | SCK | 6 | SENSOR CSB / CHIP ENABLE | 4 | SCE | H9 | S6
5 |  |  |  |  |  |  |  |  |  |  |  |  |  |  |  |  |  |  | MOS | MOS | 5 | CLOCK | 5 | SCK | K1 | T6 | S4
4 |  |  |  |  |  |  |  |  |  |  |  |  |  |  |  |  |  |  | SCK | RST | 4 | MOSI | 6 | MOS | L1 | T5 | S5
3 |  |  |  |  |  |  |  |  | GND |  |  |  |  |  | PEN | GND | DUM |  | GND | DDC | 3 | DISPLAY RESET | 7 | RST | I9 | T4
2 |  |  |  |  |  |  |  |  |  |  |  |  |  | OPE | OPE | OPE | OPE | OPE | 3V3 | DCE | 2 | DISPLAY CHIP ENABLE | 8 | DCE | J9 | T2
1 |  | 3V3 |  | GND |  |  |  |  |  | SIG | SCK | MOS | MIS | OPE | OPE | OPE | OPE | OPE |  |  | 1 | DISPLAY DATA/COMMAND | 9 | DDC | K9 | T3
 | A | B | C | D | E | F | G | H | I | J | K | L | M | N | O | P | Q | R | S | T |  | BUZZER SIGNAL | 10 | SIG | J1 | Q7
 | ... | ... | ... | ... | ... | ... | ... | ... | ... | ... | ... | ... | ... | ... | ... | ... | ... | ... | ... | ... |  | POWER ENABLE PIN | 11 | PEN | F9 | O3
 | 1 | 2 | 3 | 4 | 5 | 6 | 7 | 8 | 9 | 10 | 11 | 12 | 13 | 14 | 15 | 16 | 17 | 18 | 19 | 20 |  | POTENTIOMETER TO BUZZER | 12 | PTB | P7 | M7
 |  |  |  |  |  |  |  |  |  |  |  |  |  |  |  |  |  |  |  |  |  | DUMMY PIN TO HOLD LIPO | 13 | OPE | A1 |  |  |  |  |  |  |  |  | CUSTOM CASE DESIGNED IN SOLIDWORKS AND ORDERED THROUGH SHAPEWAYS |  |  |  | CUSTOM PCB DESIGNED IN FRITZING AND ORDERED THROUGH SEEED
 |  |  |  |  |  |  |  |  |  |  |  |  |  |  |  |  |  |  |  |  |  | OPEN HOLE TO SECURE SWITCH | 14 | DUM | Q3 |  |  |  |  |  |  | APPROX ACTUAL SIZE
 |  |  |  |  |  |  |  |  |  |  |  |  |  |  |  |  |  |  |  |  |  |  |  |  |  |  |  |  |  |  |  |  |  |  | ORIGINAL: | $65.71 | TODO -- INSERT EXPLODED ASSEMBLY VIEWS
 |  |  |  |  |  |  |  |  |  |  |  |  |  |  |  |  |  |  |  |  |  |  |  |  |  |  |  |  |  |  |  |  | PROTOTYPE 1.2.4 - MULTIVIEW |  | AS OF AUG '17: | $45.23 |  |  | END

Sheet: (OLD) SHARED PARTS LIST
 | AS OF AUG '17 | OPTIMIZATION FOR QTY: | 10
QTY | UNIT PRICE | PROTOTYPE2 PARTS | DISTIBUTOR | CONTAINS | COST | SHIP | NOTES
10 | $26.9600 | BLUEFRUIT FEATHER M0 | ADAFRUIT (https://www.amazon.com/gp/offer-listing/B01E1RESIM?s=electronics&condition=new) | 1 | $269.6000 | $0.00 | 32U4'S MEMORY WILL ALMOST MAX OUT WITH CURRENT ARDUINO IDE CODE; M0 IS COMPATIBLE, BUT CURRENTLY UNTESTED
2 | $2.5700 | BTG 150MAH LIPO* | AMAZON (https://www.amazon.com/gp/offer-listing/B01N3YQOC5/ref=dp_olp_new_mbc?ie=UTF8&condition=new) | 5 | $25.7000 | $0.00 | SWITCH THE POLARITY BEFORE PLUGGING THE BATTERY INTO A FEATHER BOARD!!!
10 | $4.9900 | MS5611 PRESSURE SENSOR | EBAY (http://www.ebay.com/itm/MS5611-Atmospheric-Pressure-Module-Precision-Height-Sensor-IIC-SPI-Electronic-/152646959866) | 1 | $49.9000 | $1.39 | THIS PRESSURE SENSOR IS CHEAPER TO BUY AS A BREAKOUT BOARD ON EBAY ($6), THAN THE PART ITSELF ON DIGIKEY ($12)
10 | $4.7400 | 0.66 INCH OLED DISPLAY SPI | EBAY (http://www.ebay.com/itm/0-66-White-OLED-Display-Module-64x48-0-66-Screen-SPI-for-Arduino-AVR-STM32-/122614297452) | 1 | $47.4000 | $1.97 | MAKE SURE THE DISPLAY SCREEN'S BREAKOUT BOARD HAS 7 TOTAL PINS
1 | $0.0990 | 8 PIN FEMALE HEADER* | EBAY (http://www.ebay.com/itm/10pcs-8-pin-2-54-mm-stackable-long-legs-femal-header-for-arduino-shield-st/172272653410) | 10 | $0.9900 | $0.00 | CUT DOWN TO A 7 PIN SOCKET
1 | $0.0198 | SMALL SLIDE SWITCH* | EBAY (http://www.ebay.com/itm/50-pcs-2-position-spdt-1p2t-3-pin-pcb-panel-vertical-slide-switch-lw/171865305033) | 50 | $0.9900 | $0.00 | MUST BEND THE STRAIGHT PINS TO 90 DEGREES FOR A SIDE MOUNTED SWITCH
10 | $0.6630 | PS1740 PIEZO TRANSDUCER* | DIGIKEY (https://www.digikey.com/product-detail/en/tdk-corporation/PS1740P02E/445-2528-ND/935933) | 1 | $6.6300 | $3.39 | PINS MUST BE BENT OUTWARD AND SURFACE MOUNTED ON PCB HOLES DUE TO MIS-ALIGNMENT
10 | $1.3500 | POT 1.0K OHM THUMBWHEEL | DIGIKEY (https://www.digikey.com/product-detail/en/bourns-inc/3352T-1-102LF/3352T-102LF-ND/1088340) | 1 | $13.5000 |  | VOLUME CONTROL
1 | $0.4900 | PROTOTYPE2 PCB** | SEEED (https://github.com/glydrfreak/vSpeedVario/tree/master/Fritzing) | 10 | $4.9000 | $10.37 | TODO -- RE-POSITION PIEZO BUZZER PIN HOLES
10 | $5.7200 | PROTOTYPE2 FRONT CASE** | SHAPEWAYS (https://github.com/glydrfreak/vSpeedVario/tree/master/SolidWorks) | 1 | $57.2000 | $4.99 | TODO -- FIND A CHEAPER ALTERNATIVE
10 | $2.8300 | PROTOTYPE2 BACK CASE** | SHAPEWAYS (https://github.com/glydrfreak/vSpeedVario/tree/master/SolidWorks) | 1 | $28.3000 |  | TODO -- FIND A CHEAPER ALTERNATIVE
SUBTOTAL | $50.4318 | * MODIFICATION REQUIRED |  | SUBTOTAL | $505.1100
SHIPPING | $2.2110 | ** CUSTOM DESIGNED PARTS |  | SHIPPING | $22.1100
TOTAL | $52.6428 |  |  | TOTAL PURCHASE | $527.2200
 |  |  |  | EACH | $52.72
 |  |  |  | WASTE | $0.08
 | REFERENCE
 |  | FRONT & BACK CASING (SHAPEWAYS.COM) | SHAPEWAYS | EACH CASING | $9.0490 |  | POWDER BASED, STRONG AND FLEXIBLE PLASTIC
 | ALTERNATIVE 1
 |  | CASING -- OGDEN PICKUP (BEN'S HUB) | 3D HUBS | EACH CASING | $1.7370 |  | 200 MICRONS PLA FILAMENT, WHICH MEANS SIGNIFICANTLY LESSER QUALITY THAN SHAPEWAYS
 |  |  |  | SAVINGS | $7.3120
 |  |  |  | NEW EACH | $45.41
 |  |  |  | NEW PURCHASE | $454.10
 | ALTERNATIVE 2
 |  | CASING -- WEST HAVEN (ART OF MAKING IT'S HUB) | 3D HUBS | EACH CASING | $1.5620 |  | 200 MICRONS PLA FILAMENT, WHICH MEANS SIGNIFICANTLY LESSER QUALITY THAN SHAPEWAYS
 |  |  |  | SAVINGS | $7.4870
 |  |  |  | NEW EACH | $45.23
 |  |  |  | NEW PURCHASE | $452.35

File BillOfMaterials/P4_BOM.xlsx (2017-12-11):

PROTOTYPE[4]
Designator | Manufacturer Part Number | QTY | DESCRIPTION | DISTRIBUTER | DIVIDED PRICE | INCLUDED | DISTRIBUTER | DIVIDED PRICE | INCLUDED | DISTRIBUTER | EXTENDED PRICE | INCLUDED
R2 | RC0805FR-0730KL | 1 | RES 30K | DIGIKEY | $0.10 | 1 | DIGIKEY | $0.02 | 10 | DIGIKEY | $0.88 | 100
IC1 | 74HC00D,652 | 1 | NAND | DIGIKEY | $0.36 | 1 | DIGIKEY | $0.29 | 10 | DIGIKEY | $19.74 | 100
C1 | 08055C104JAT2A | 1 | CAP 0.1UF | DIGIKEY | $0.10 | 1 | DIGIKEY | $0.07 | 10 | DIGIKEY | $3.10 | 100
R3 | RC0805JR-0710KL | 1 | RES 10K | DIGIKEY | $0.10 | 1 | DIGIKEY | $0.02 | 10 | DIGIKEY | $0.76 | 100
R1,R4 | RC0805JR-071KL | 2 | RES 1K | DIGIKEY | $0.19 | 10 | DIGIKEY | $0.02 | 20 | DIGIKEY | $1.52 | 200
U$1 | 2908-05WB-MG | 1 | SD | DIGIKEY | $3.60 | 1 | DIGIKEY | $3.46 | 10 | DIGIKEY | $288.20 | 100
U1 | AD8400ARZ1 | 1 | SPI POT 1K | DIGIKEY | $3.31 | 1 | DIGIKEY | $3.31 | 10 | DIGIKEY | $281.25 | 100
Q1 | MMBT2222ALT1G | 1 | NPN TRANSISTOR | DIGIKEY | $0.12 | 1 | DIGIKEY | $0.11 | 10 | DIGIKEY | $5.75 | 100
S1 | B3F-3120 | 1 | BUTTON | DIGIKEY | $0.44 | 1 | DIGIKEY | $0.42 | 10 | DIGIKEY | $34.52 | 100
DFU,MOSI,A3,GND,SDA,D9,D13 | 878980426 | 7 | VERT HEADER | DIGIKEY | $2.53 | 10 | DIGIKEY | $1.77 | 100 | DIGIKEY | $106.13 | 700
EPD_3V3 | GEC08SBSN-M89 | 1 | RA HEADER | DIGIKEY | $1.53 | 1 | DIGIKEY | $1.37 | 10 | DIGIKEY | $112.60 | 100
 | ESTIMATED DIGIKEY SHIPPING | 1 | SHIPPING | SHIPPING | $3.69 | 1 | SHIPPING | $0.37 | 10 | SHIPPING | $3.69 | 100
IC2 | MS561101BA03-50 | 1 | SENSOR | EBAY | $5.58 | 1 | EBAY | $5.58 | 10 | EBAY | $558.00 | 100
LS1 | BOT-03D-BUJEON, SMT-1127-S-R (ALT) | 1 | BUZZER | EBAY | $3.61 | 10 | EBAY | $0.36 | 10 | EBAY | $36.10 | 100
 | 2.9 INCH E-PAPER MODULE WITH WIRES | 1 | EPAPER | EBAY | $18.76 | 1 | EBAY | $18.75 | 10 | EBAY | $1875.20 | 100
 | SOLDER PASTE | ? | SOLDER PASTE | EBAY | UNKNOWN |  | EBAY | UNKNOWN |  | EBAY | UNKNOWN
 | ESTIMATED EBAY SHIPPING | 1 | SHIPPING | SHIPPING | $3.18 | 1 | SHIPPING | $1.23 | 10 | SHIPPING | $113.85 | 100
 | BLUEFRUIT FEATHER M0 | 1 | CONTROLLER | ADAFRUIT | $29.95 | 1 | ADAFRUIT | $26.96 | 10 | ADAFRUIT | $2396.00 | 100
 | FEMALE HEADER SOCKETS 12 AND 16 PIN | 1 | SOCKET | ADAFRUIT | $0.95 | 1 | ADAFRUIT | $0.86 | 10 | ADAFRUIT | $76.00 | 100
 | ADAFRUIT SHIPPING | 1 | SHIPPING | SHIPPING | $4.05 | 1 | ADAFRUIT | FREE | 10 | ADAFRUIT | FREE | 100
 | BTG 150mAh LIPO BATTERY | 1 | BATTERY | AMAZON | $12.85 | 5 | AMAZON | $2.57 | 10 | AMAZON | $257.00 | 100
 | FREE SHIPPING WITH AMAZON PRIME | 1 | SHIPPING | SHIPPING | FREE | 5 | SHIPPING | FREE | 10 | SHIPPING | FREE | 100
 | PCB | 1 | EAGLE CAD | SEEED | $4.90 | 5 | SEEED | $0.49 | 10 | SEEED | $41.59 | 100
 | SEEED STUDIO SHIPPING | 1 | SHIPPING | SHIPPING | $10.85 | 5 | SEEED | $1.11 | 10 | SEEED | $17.55 | 100
 | SOLDER STENCIL | 1 | HOME 3D PRINTED | PRUSA MK3 | UNKNOWN | 1 | PRUSA MK3 | UNKNOWN | 10 | PRUSA MK3 | UNKNOWN | 100
 | CASE (THREE PIECES TOTAL) | 1 | HOME 3D PRINTED | PRUSA MK3 | UNKNOWN | 1 | PRUSA MK3 | UNKNOWN | 10 | PRUSA MK3 | UNKNOWN | 100
 | ASSUMING YOU HAVE YOUR OWN PRINTER | 1 | SHIPPING | SHIPPING | FREE |  | SHIPPING | FREE |  | SHIPPING | FREE
 |  |  |  | TOTAL PURCHASE | $110.75 |  | TOTAL PURCHASE | $691.42 |  | TOTAL PURCHASE | $6229.44
 |  |  |  | 1 VARIO | $110.75 | EACH | 10 VARIOS | $69.14 | EACH | 100 VARIOS | $62.29 | EACH

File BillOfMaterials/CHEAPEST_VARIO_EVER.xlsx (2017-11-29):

Component | Name | Cost | Shipping
Controller | Arduino Nano | $2.17 | $0.00
Altimeter | MS5611 | $4.87 | $1.39
Buzzer | 10pcs 2 Pins Black 14*7.5mm Passive Piezo Buzzer TB | $1.35 | $0.00
Battery | 9V | $3.77 | $0.00
Assembly | Wires | $1.30 | $0.00
Enclosure | Heat Shrink
 |  | $13.46 | $1.39
 | Total | $14.85

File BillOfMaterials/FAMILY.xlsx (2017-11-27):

Model | PROTOTYPE1 | PROTOTYPE2 | PROTOTYPE3 | PROTOTYPE4
Height x Width x Thickness (mm) | 100 x 70 x 20 | 60 x 28 x 20 | 60 x 28 x 20 | 100 x 40 x 30
Controller | ARDUINO NANO | Bluefruit Feather 32u4 | Bluefruit Feather M0 | Bluefruit Feather M0
Barometer | BMP180 | MS5611 | MS5611 | MS5611
Altitude Sample Rate (Hz) | 13 | 21-49 | 37-56 | (Not Tested Yet)
Altitude Precision (cm) | 35 | 11 | 10 | 10
Android App Compatibility | - | v^SPEED | v^SPEED | v^SPEED
iPhone App Compatibility | - | - | Flyskyhy | Flyskyhy
Battery | 9V | BTG 150 mAh Li-Po 3.7V | BTG 150 mAh Li-Po 3.7V | BTG 150 mAh Li-Po 3.7V
Battery Life w/ Full Function | (Hasn't Died Yet) | (Approx 8 hr) | (Approx 8 hr) | (Not Tested Yet)
Buzzer | PS1240 | PS1740 | PS1740 | BOT-03D-BUJEON
Amplification | - | - | - | Yes
Volume Control | Thumbwheel | Thumbwheel | Thumbwheel | Digital
Display | Nokia5110 LCD | 0.66" OLED | 0.66" OLED | 2.9" e-Paper
Micro SD Slot | - | - | - | Yes
User Control | Volume, Brightness, Power | Volume, Power | Volume, Power | Single Button
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

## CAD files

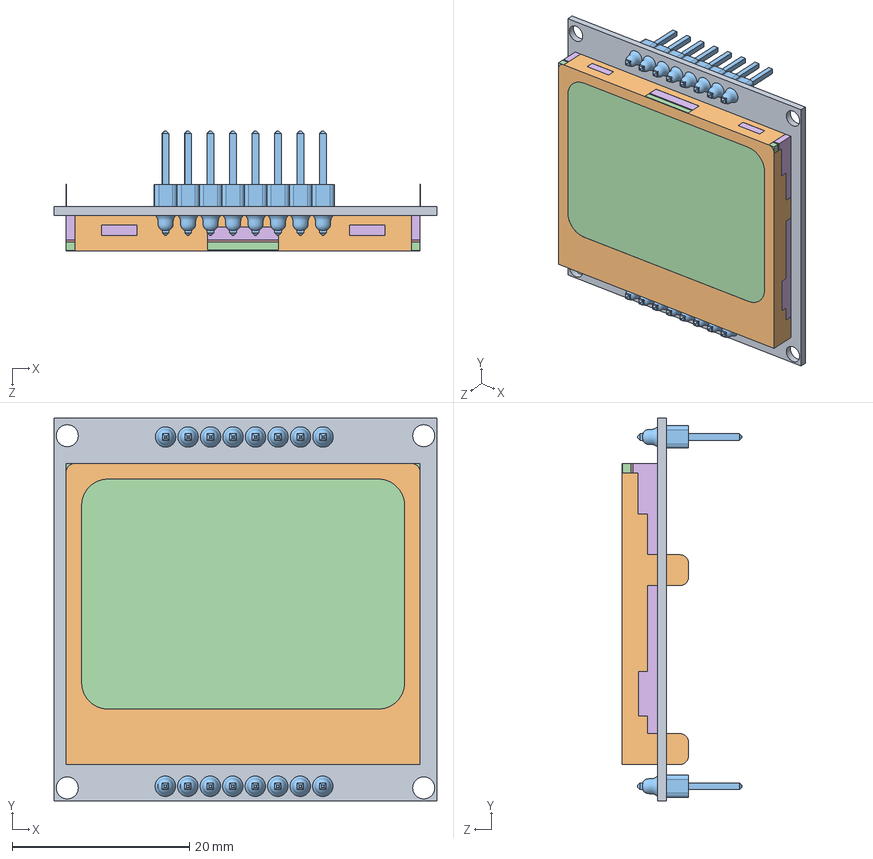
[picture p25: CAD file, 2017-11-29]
SolidWorks/P1.new/display.SLDASM
43.2 x 43.2 x 13.5 mm
placa
display
8pin_header x 2
vidro
cristal_liquido
cristal_inferior

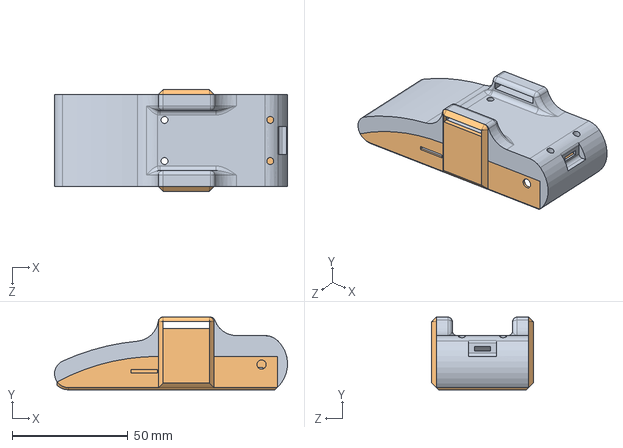
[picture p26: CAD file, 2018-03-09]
SolidWorks/P4.new/P4.1_CASE.SLDASM
100.8 x 31.5 x 44.0 mm
P4.1_2.9_EPD_CASE_BACK
P4.1_2.9_EPD_CASE_COVER

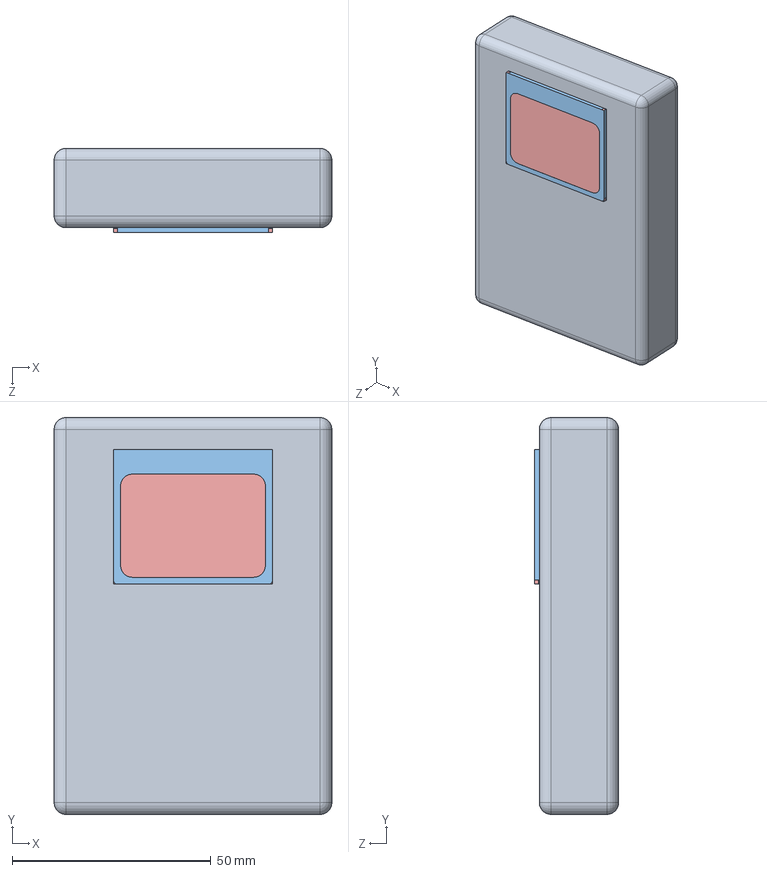
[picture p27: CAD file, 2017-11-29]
SolidWorks/P1.new/PROTOTYPE1.SLDASM
70.0 x 100.0 x 21.2 mm
P1_CARDBOARD_CASE
placa
display
8pin_header x 2
vidro
cristal_liquido
cristal_inferior

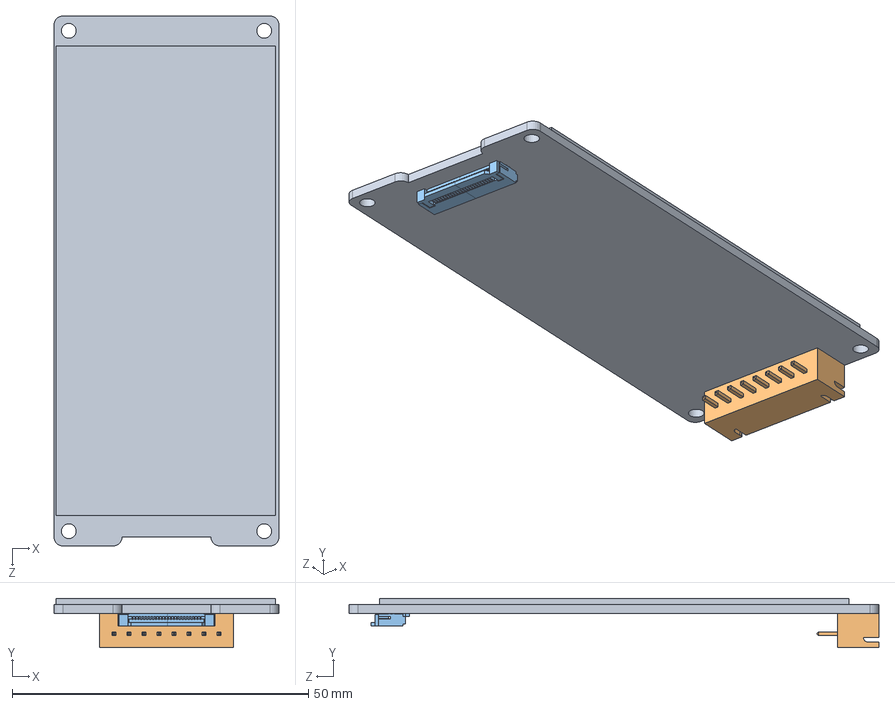
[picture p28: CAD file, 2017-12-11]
SolidWorks/P4/P4_2.9_EPD.SLDASM
38.0 x 8.30 x 89.5 mm
P4_2.9_EPD
P4_JST XH 8 S8B-XH-A1 shrouded header connector v4
P4_FPC_24

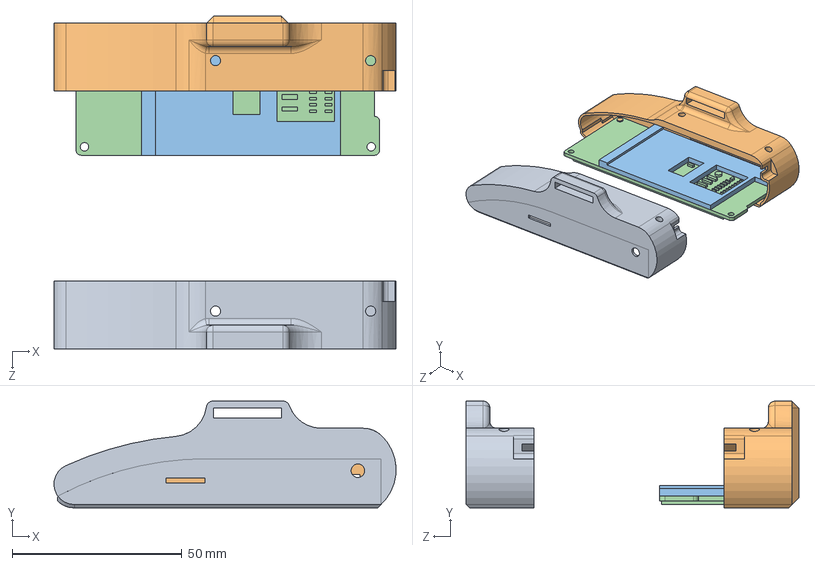
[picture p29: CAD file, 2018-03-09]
SolidWorks/P4.new/P4.2_CASE.SLDASM
100.8 x 31.5 x 98.0 mm
P4.1_CASE_LEFT
P4.1_CASE_RIGHT
P4.1_SPACER
P4_2.9_EPD

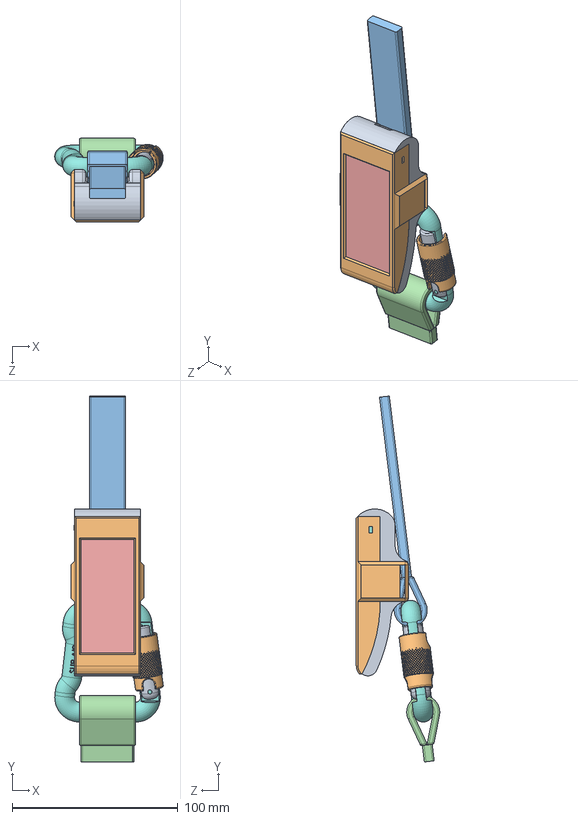
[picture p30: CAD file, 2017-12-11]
SolidWorks/P4/P4_ASSEMBLY.SLDASM
65.5 x 221.1 x 50.5 mm
P4_BTG 3.7V 150mAh LIPO
P4_CAPC-0805-T1.35-BN
P4_RESC-0805 x 4
P4_soic-14
P4_MICRO_SD_WITH_SLOT
P4_MS5611NOBREAKOUT
P4_TACTILE_SWITCH_SIDE
P4_BOT-03D PASSIVE BUZZER
P4_AB2_USB_MICRO_SMD
P4_JST 2pin rightangle
P4_BLUEFRUIT FEATHER
P4_1PIN_8.25_SHORT_SOCKET x 28
P4_2.9_EPD
P4_JST XH 8 S8B-XH-A1 shrouded header connector v4
P4_FPC_24
P4_PCB_FOR_2.9_EPD
P4_2.9_EPD_CASE_BACK
P4_2.9_EPD_CASE_COVER
P4_SO8
P4_SOT23
P4_878980426 x 7
P4_SPACER
P4_SMT_RA_PIN x 8
ALÇA
GATILHO
FECHO
RISER
HARNESS

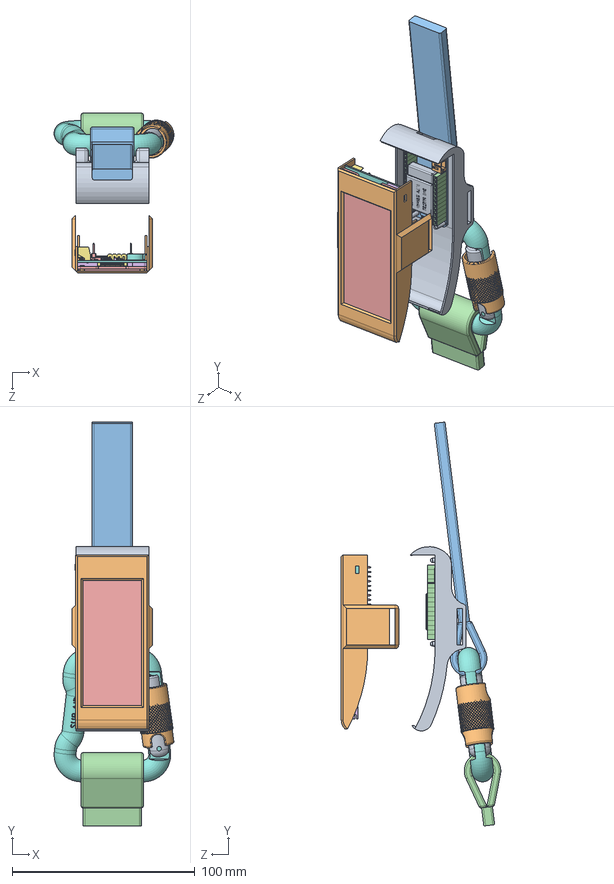
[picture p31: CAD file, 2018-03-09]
SolidWorks/P4.new/PROTOTYPE4.SLDASM
65.5 x 221.1 x 87.3 mm
P4_BTG 3.7V 150mAh LIPO
P4_CAPC-0805-T1.35-BN
P4_RESC-0805 x 4
P4_soic-14
P4_MICRO_SD_WITH_SLOT
P4_MS5611NOBREAKOUT
P4_TACTILE_SWITCH_SIDE
P4_BOT-03D PASSIVE BUZZER
P4_AB2_USB_MICRO_SMD
P4_JST 2pin rightangle
P4_BLUEFRUIT FEATHER
P4_1PIN_8.25_SHORT_SOCKET x 28
P4_2.9_EPD
P4_JST XH 8 S8B-XH-A1 shrouded header connector v4
P4_FPC_24
P4_PCB_FOR_2.9_EPD
P4_2.9_EPD_CASE_BACK
P4_2.9_EPD_CASE_COVER
P4_SO8
P4_SOT23
P4_878980426 x 7
P4_SPACER
P4_SMT_RA_PIN x 8
CARABINER_MAIN
CARABINER_ARM
CARABINER_LOCK
RISER
HARNESS

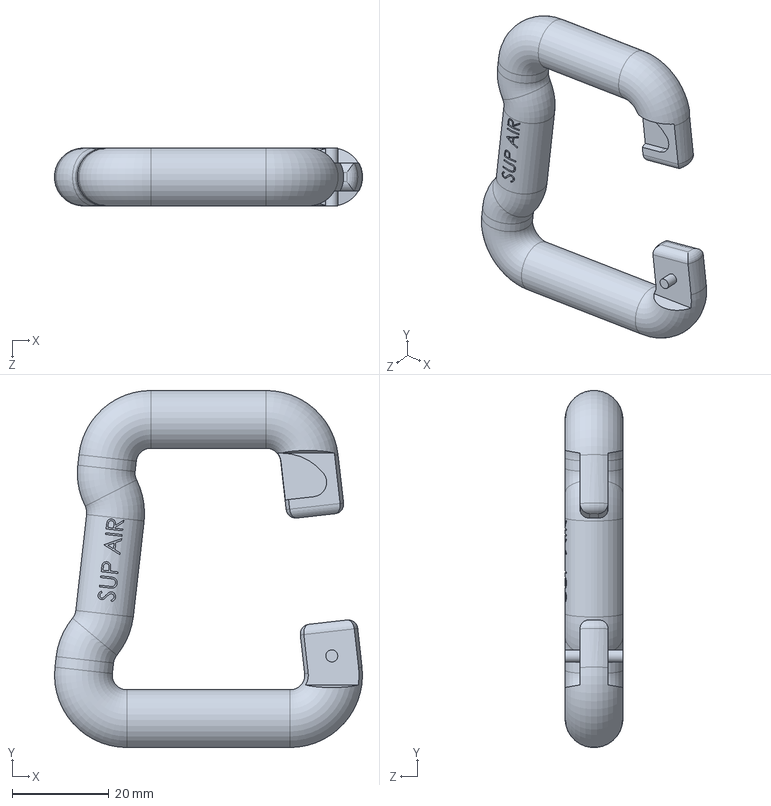
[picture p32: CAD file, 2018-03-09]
SolidWorks/P4.new/CARABINER_MAIN.SLDPRT
63.8 x 73.9 x 12.0 mm

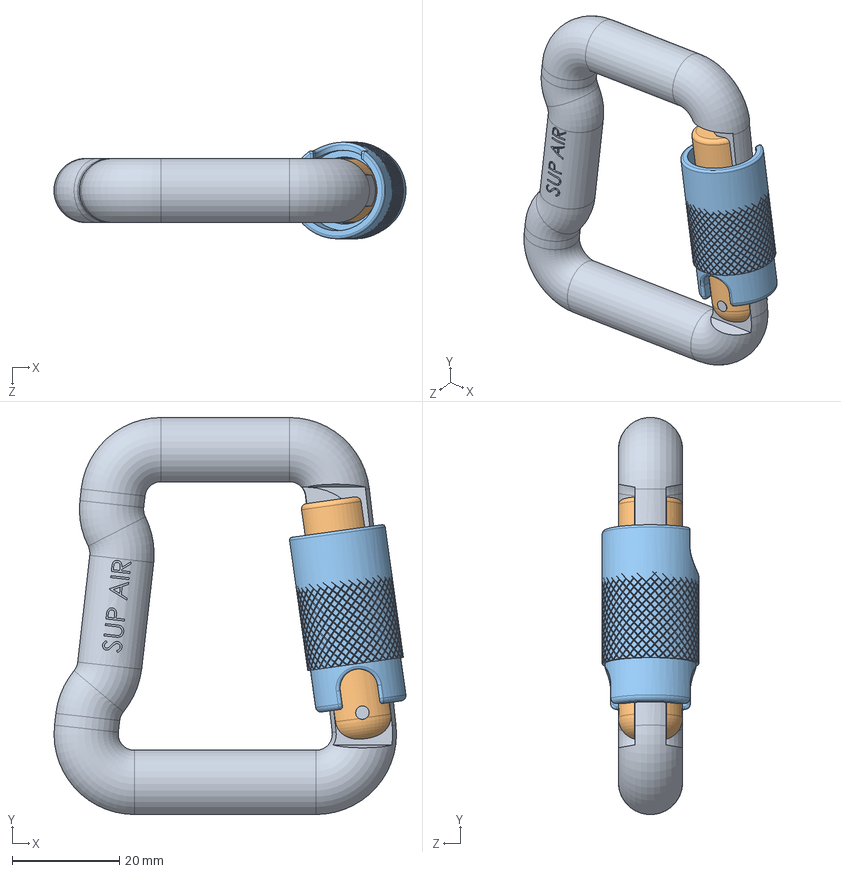
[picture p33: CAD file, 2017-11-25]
SolidWorks/P4/CARABINER SUP AIR Ø12.SLDASM
65.5 x 73.9 x 18.0 mm
ALÇA
GATILHO
FECHO

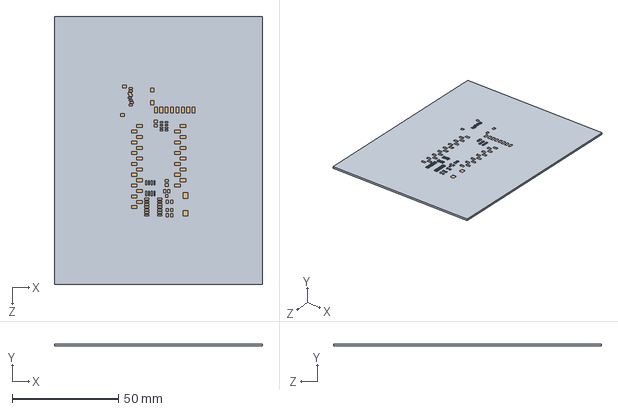
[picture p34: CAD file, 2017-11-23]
SolidWorks/P4/SOLDER_PASTE.SLDASM
98.0 x 1.12 x 126.0 mm
P4_SOLDER_STENCIL
P4_PCB_FOR_2.9_EPD

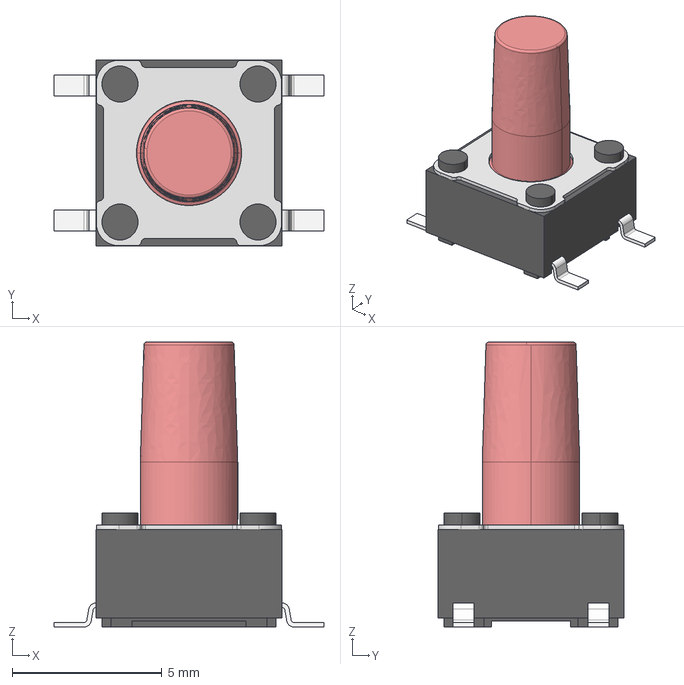
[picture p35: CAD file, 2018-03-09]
Eagle/P5/Tact Switch SMD 6x6x9.5mm.stp
9.00 x 6.20 x 9.50 mm

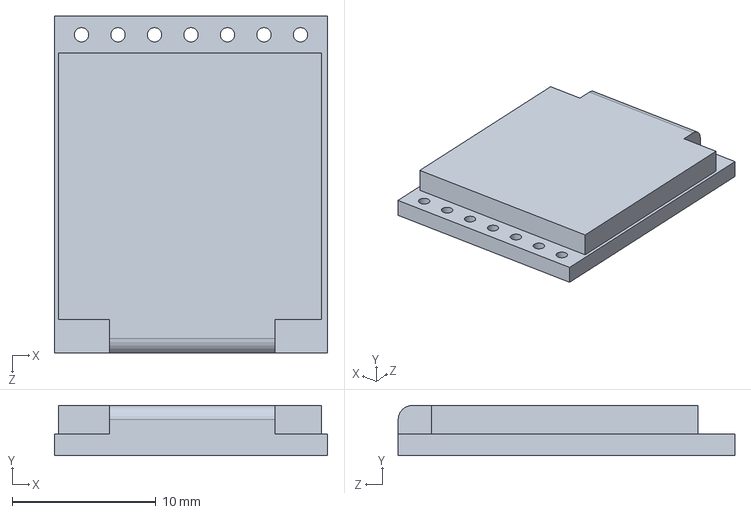
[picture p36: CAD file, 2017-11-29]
SolidWorks/P2.new/0.66 INCH OLED.SLDPRT
19.0 x 3.50 x 23.4 mm

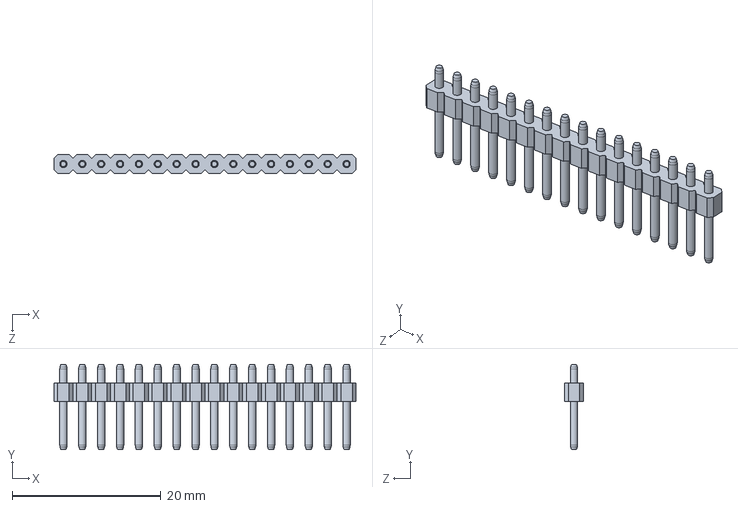
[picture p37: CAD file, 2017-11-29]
SolidWorks/P3.new/p3_3 PIN MALE HEADERS.SLDPRT
40.6 x 11.5 x 2.54 mm

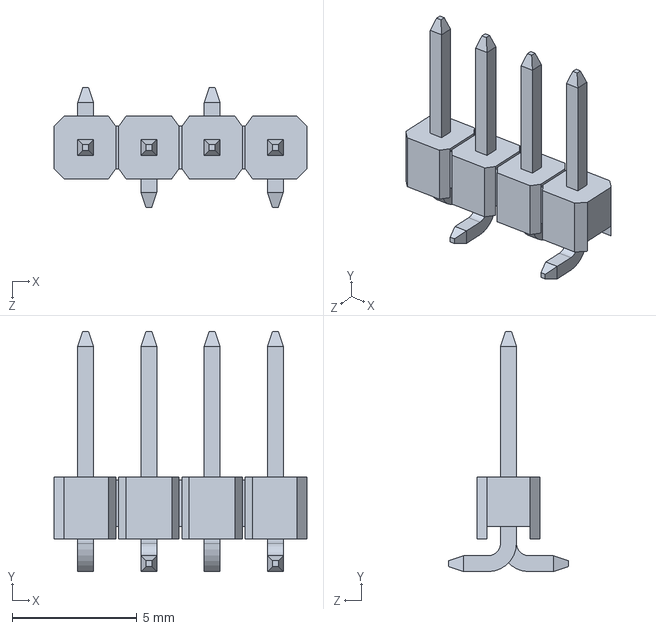
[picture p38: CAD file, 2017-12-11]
SolidWorks/P4/P4_878980426.SLDPRT
10.2 x 9.65 x 4.80 mm

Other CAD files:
SolidWorks/P4.new/P4_2.9_EPD.SLDASM
SolidWorks/P4.new/CARABINER SUP AIR.SLDASM
SolidWorks/P1.new/8pin_header.SLDPRT
SolidWorks/P1.new/P1_CARDBOARD_CASE.SLDPRT
SolidWorks/P1.new/cristal_inferior.SLDPRT
SolidWorks/P1.new/cristal_liquido.SLDPRT
SolidWorks/P1.new/display.SLDPRT
SolidWorks/P1.new/placa.SLDPRT
SolidWorks/P1.new/vidro.SLDPRT
SolidWorks/P2.new/1 PIN MALE HEADER.SLDPRT
SolidWorks/P2.new/2 PIN MALE HEADER.SLDPRT
SolidWorks/P2.new/3 PIN MALE HEADERS.SLDPRT
SolidWorks/P2.new/7 PIN MALE HEADERSS.SLDPRT
SolidWorks/P2.new/AB2_USB_MICRO_SMD.SLDPRT
SolidWorks/P2.new/BLUEFRUIT FEATHER.SLDPRT
SolidWorks/P2.new/BTG 3.7V 150mAh LIPO.SLDPRT
SolidWorks/P2.new/CUSTOM PCB.SLDPRT
SolidWorks/P2.new/JST 2pin rightangle.SLDPRT
SolidWorks/P2.new/MS5611.SLDPRT
SolidWorks/P2.new/P2 CASE - BACK COVER.SLDPRT
SolidWorks/P2.new/P2 CASE - FRONT SHELL.SLDPRT
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

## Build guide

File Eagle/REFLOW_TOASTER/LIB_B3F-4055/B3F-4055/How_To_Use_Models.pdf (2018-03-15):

ECAD PART WIZARD.

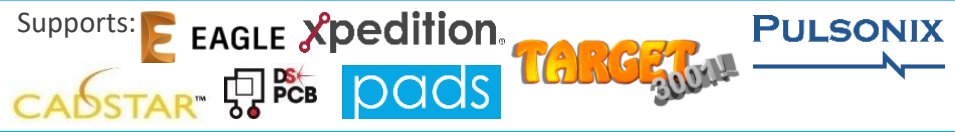
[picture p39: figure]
Supports:

Offers engineers full control of the symbol fracturing and symbol pin positions (left, right, top, bottom). ECAD Symbols & footprints can be downloaded directly from within the EPW application or from manufacturer and RS Component website.

DOWNLOAD: http://componentsearchengine.com/EPW.html

LIBRARY LOADER.
Allows Engineers to click our icon from any webpage and it injects the symbols and footprint directly into your chosen library and attached them to your cursor ready for placement.

DOWNLOAD: http://componentsearchengine.com/LibraryLoader.php

SamacSys is a leading developer of software tools for creating and managing electronic component ECAD data.

## 3 ways to use our ECAD Schematic Symbols & PCB footprints

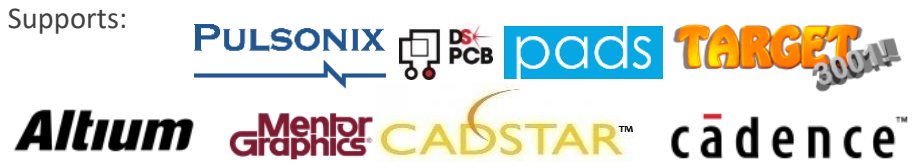
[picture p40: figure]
Supports:

DIRECT MODEL DOWNLOAD FOR MANUAL USE.
Our Schematic Symbols and PCB Footprint can be downloaded in a zip file for the user to manually load into their existing ECAD Library.

DOWNLOAD: http://componentsearchengine.com

Automatically load
models into your
library and attach
them to your cursor
by clicking our icon
on any website.

WATCH VIDEO (https://componentsearchengine.com/pcb-libraries.php)

Excel plug in. Search
for parts from within
Excel, customise the
fracturing and export
to your chosen ECAD
Tool.

WATCH VIDEO (http://www.samacsys.com/epw/)

You may download our
symbols & footprints in
the format of your
ECAD system for
manually loading into
your library.

MORE INFO (http://www.samacsys.com/pcb-part-libraries/)

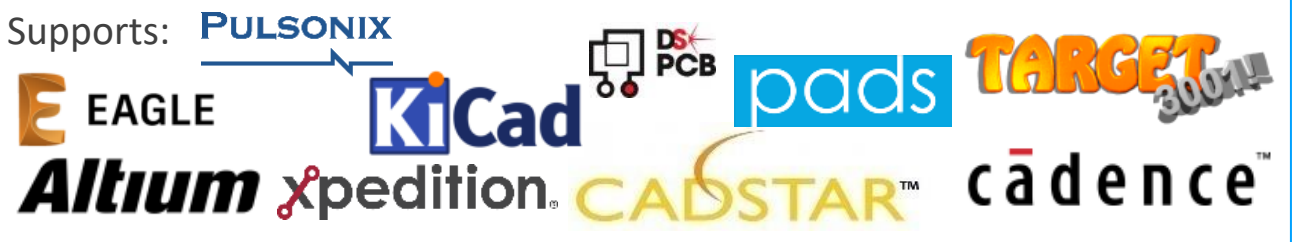
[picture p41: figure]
Supports:

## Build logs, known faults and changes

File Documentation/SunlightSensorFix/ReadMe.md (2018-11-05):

<h1>Sunlight Sensor Fix</h1>
An issue has been identified with bright sunlight having a negative effect on the MS5611 pressure sensor. </br>
A fix has been provided as shown below:

<table>
  <tr>
    <td width=60% vAlign="top" align="center">
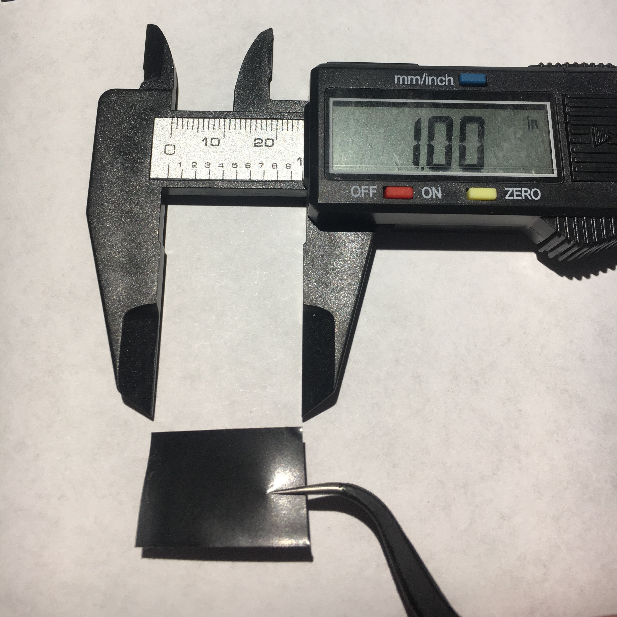
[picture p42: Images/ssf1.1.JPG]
      
    </td>
    <td width=40%> 
      <ul>
        <li>Cut a piece of electrical tape 1 inch long</li>
      </ul>
    </td>
  </tr>
</table>
<table>
  <tr>
    <td width=60% vAlign="top" align="center">
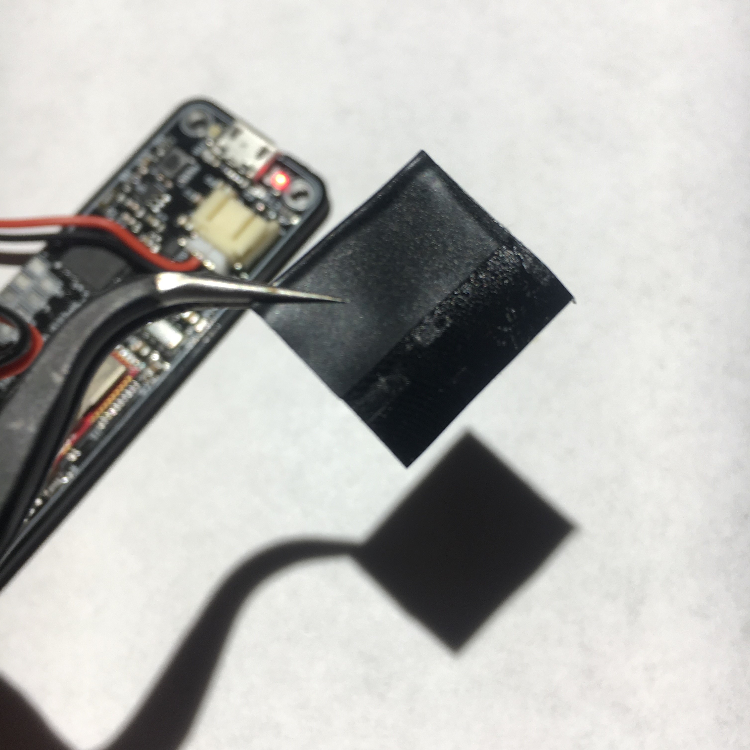
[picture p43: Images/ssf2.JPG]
      
    </td>
    <td width=40%> 
      <ul>
        <li>Fold over the edge just past the centerline</li>
      </ul>
    </td>
  </tr>
</table>
<table>
  <tr>
    <td width=60% vAlign="top" align="center">
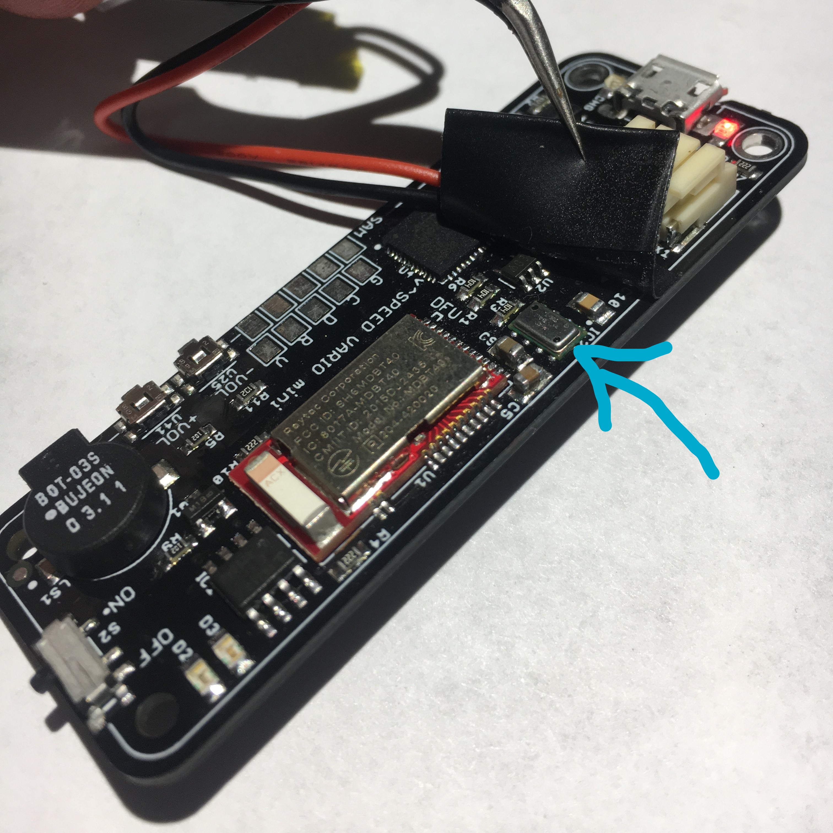
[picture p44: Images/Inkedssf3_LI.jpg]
      
    </td>
    <td width=40%> 
      <ul>
        <li>Apply the sticky side in front of the battery connector</li>
        <li>Make sure to have the pressure sensor free of the sticky part, or else the sensor will be suffocated</li>
        (The blue arrow indicates the pressure sensor)
      </ul>
    </td>
  </tr>
</table>
<table>
  <tr>
    <td width=60% vAlign="top" align="center">
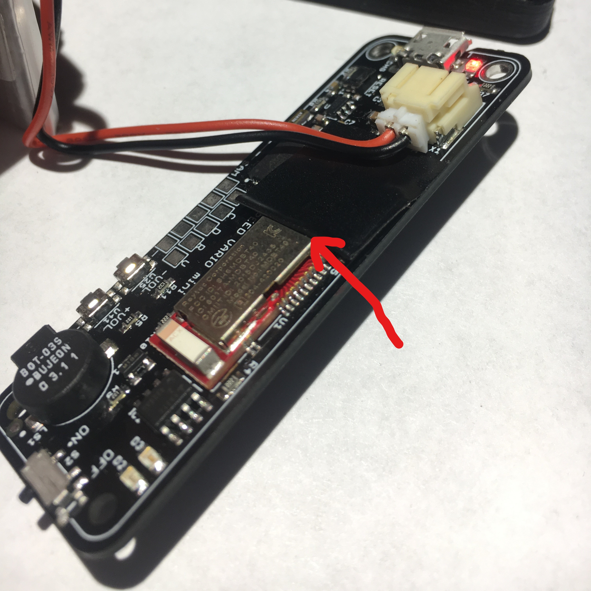
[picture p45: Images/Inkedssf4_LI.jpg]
      
    </td>
    <td width=40%> 
      <ul>
        <li>The folded edge should be flush with the bluetooth module</li>
      </ul>
    </td>
  </tr>
</table>
<table>
  <tr>
    <td width=60% vAlign="top" align="center">
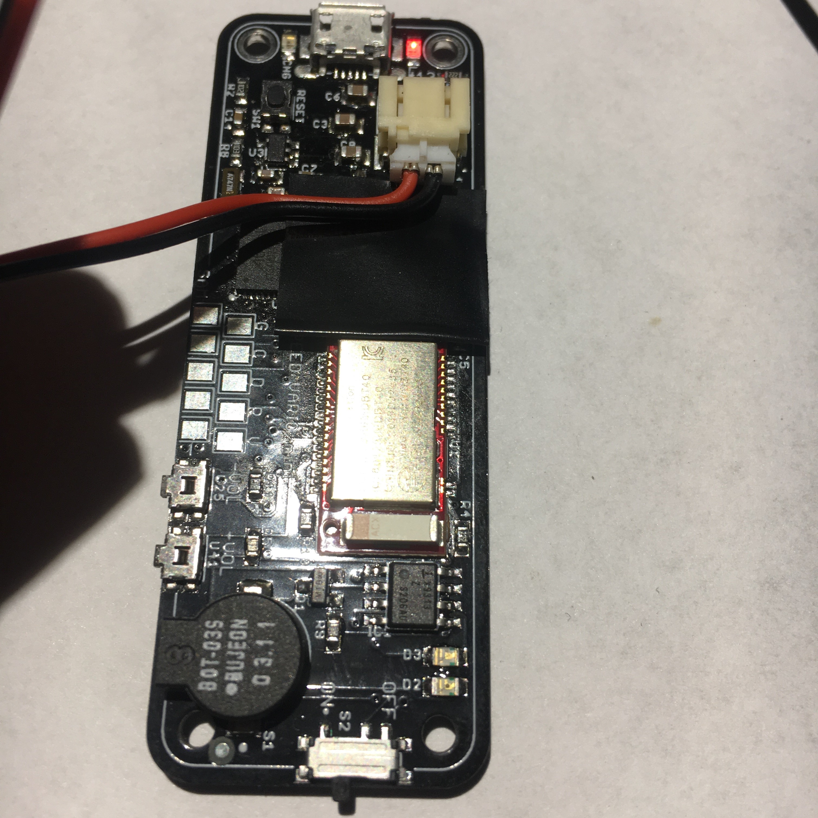
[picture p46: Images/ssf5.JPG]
      
    </td>
    <td width=40%> 
      <ul>
        <li>The edge of the tape should be flush with the edge of the circuit board</li>
        <li>This way, when the case is screwed on it will hold the tape in place</li>
      </ul>
    </td>
  </tr>
</table>
<table>
  <tr>
    <td width=60% vAlign="top" align="center">
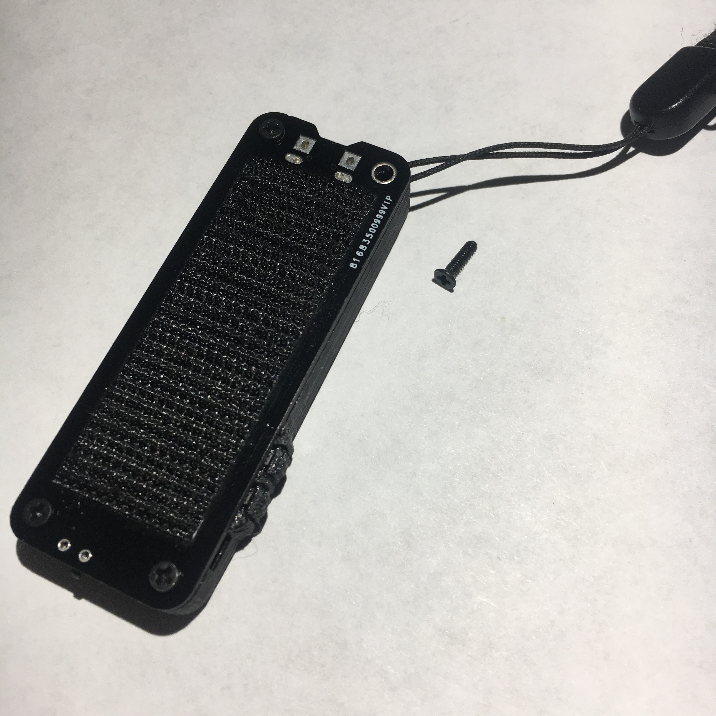
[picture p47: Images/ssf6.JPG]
      
    </td>
    <td width=40%> 
      <ul>
        <li>To re-attatch the leash, it is best to screw the other three screws in first</li>
        <li>Then insert the leash into the slot, followed by the fourth screw</li>
        <li><b>BE EXTRA CAUTIOUS TO NOT STRIP OUT THE CASE WITH THE SCREWS! THEY SHOULD NOT BE TORQUED AT ALL</b></li>
      </ul>
    </td>
  </tr>
</table>

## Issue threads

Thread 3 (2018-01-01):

Noisey Altitude when EPD Enabled

glydrfreak, 2018-01-01:
EPAPER TAKES SIGIFICANT TIME TO UPDATE EACH FRAME;
 *  WHEN THE DISPLAY IS ENABLED, THE ALTIDUDE DATA IS VERY NOISY AT 87 SAMPLES PER SECOND;
 *  WHEN THE DISPLAY IS OFF, THE ALTITUDE DATA IS VERY SMOOTH AT 91 SAMPLES PER SECOND;

glydrfreak, 2018-01-01:
When the epd is reset using...

digitalWrite(rst_pin, LOW);
delay(200);
digitalWrite(rst_pin, HIGH);
delay(200);

...then no more requests are sent to refresh the display, precision is regained. If there is another command sent to refresh the display after the reset sequence, noisy data remains.

glydrfreak, 2018-02-23:
- I wired up the MS5611 via I2C and still I get noisey data when the EPD is enabled.
- I also tried to slow down the loops while the EPD was disabled to ensure the same sample rate.

Still no avail. Looks like this isn't SPI interference like I thought it was. Perhaps something with the power line going through the EPD? I'm desperate for ideas now. Until then, it looks like the 2.9" e-Paper Display is a no go.

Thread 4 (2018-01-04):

Arduino IDE: Unpredictable Errors while Uploading Sketches

glydrfreak, 2018-01-04:
These errors have been happening to me a lot lately with the Adafruit Bluefruit Feather M0:

First it gets stuck at this stage for way longer than usual--
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

Then pressing reset (either once or twice) gets me to here--
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

A less frequent, but still annoying error (separate from the above error)--
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

I have a feeling it's not just a problem with the Arduino IDE because I've tried to upload via Visual Studio and I've had no luck. (I've also never successfully uploaded via Visual Studio before either. I only tried Visual Studio to see if it was a problem with the Arduino IDE.)

glydrfreak, 2018-01-04:
I've now tried to upload the "blink" sketch to the feather M0 via Visual Studio. It worked fine.

... I'll just be commenting my findings as I find them I guess...

glydrfreak, 2018-01-05:
I've finally been able to upload my PROTOTYPE4 Sketch via Visual Studio. The above errors that I have explained have come and gone repeatedly, and I find no pattern in what causes such errors.

<h1>When do the errors occur? </h1>
<b>TOTALLY UNPREDICTABLE!</b></br>
Some days seem flawless, while other days I can't make any progress with my code at all!

glydrfreak, 2018-01-05:
`...`
`Sketch uses 75232 bytes (28%) of program storage space. Maximum is 262144 bytes.`
`Forcing reset using 1200bps open/close on port COM10`
(Upload sequence is stuck after this line prints in the verbose output.)

- I usually get one successful upload with my PROTOTYPE4 sketch after running the "blink" sketch prior. then it repeatedly gets stuck on this line if I try to upload my PROTOTYPE4 sketch again.

- I cannot reproduce the same error with the "blink" sketch.

Closed 2018-01-05.

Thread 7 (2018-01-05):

Arduino IDE: Stuck Forcing reset using 1200bps open/close on port

glydrfreak, 2018-01-05:
`...`
`Sketch uses 75232 bytes (28%) of program storage space. Maximum is 262144 bytes.`
`Forcing reset using 1200bps open/close on port COM10`
(Upload sequence is stuck after this line prints in the verbose output.)

- I usually get one successful upload with my PROTOTYPE4 sketch after running the "blink" sketch prior. then it repeatedly gets stuck on this line if I try to upload my PROTOTYPE4 sketch again.

- I cannot reproduce the same error with the "blink" sketch.

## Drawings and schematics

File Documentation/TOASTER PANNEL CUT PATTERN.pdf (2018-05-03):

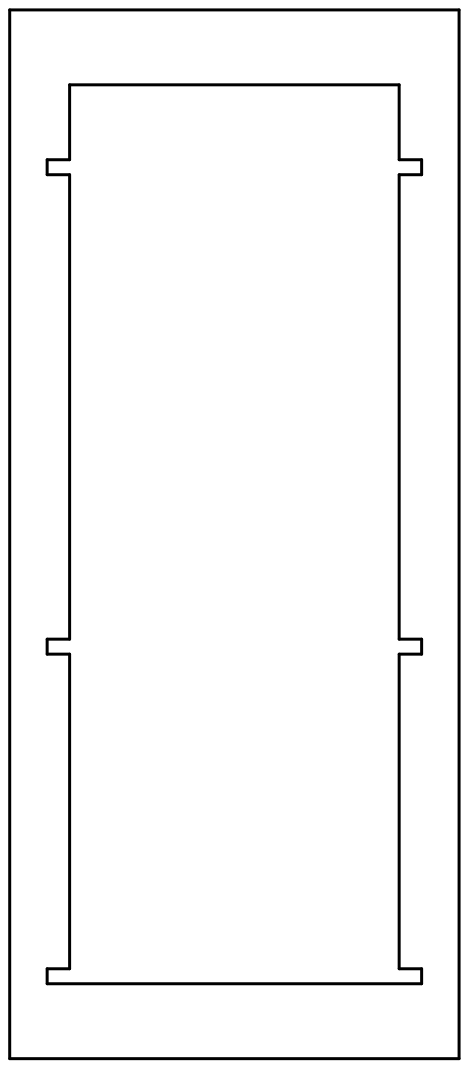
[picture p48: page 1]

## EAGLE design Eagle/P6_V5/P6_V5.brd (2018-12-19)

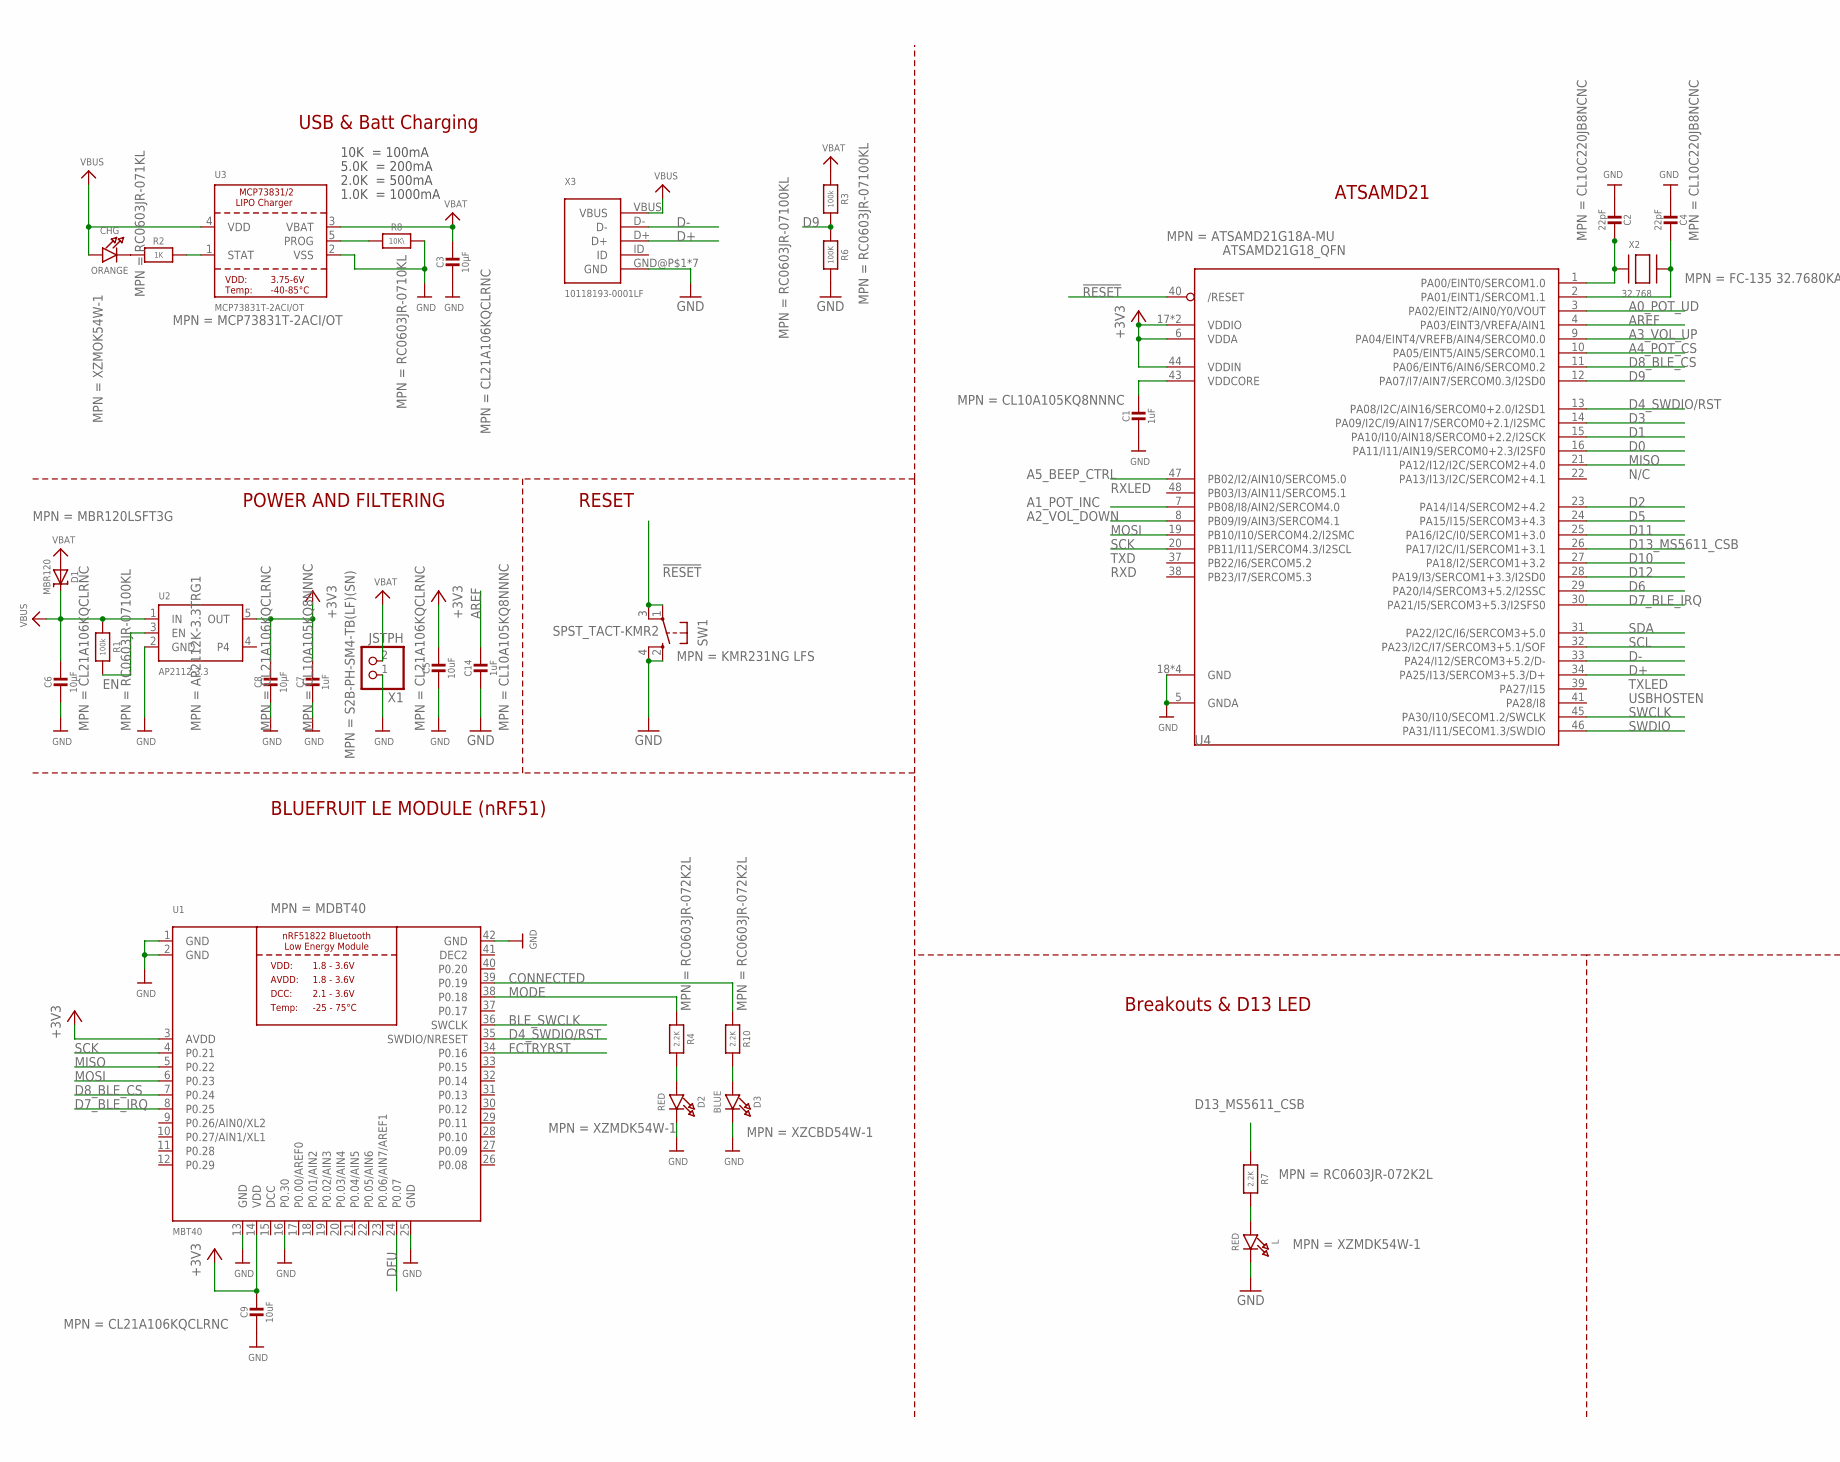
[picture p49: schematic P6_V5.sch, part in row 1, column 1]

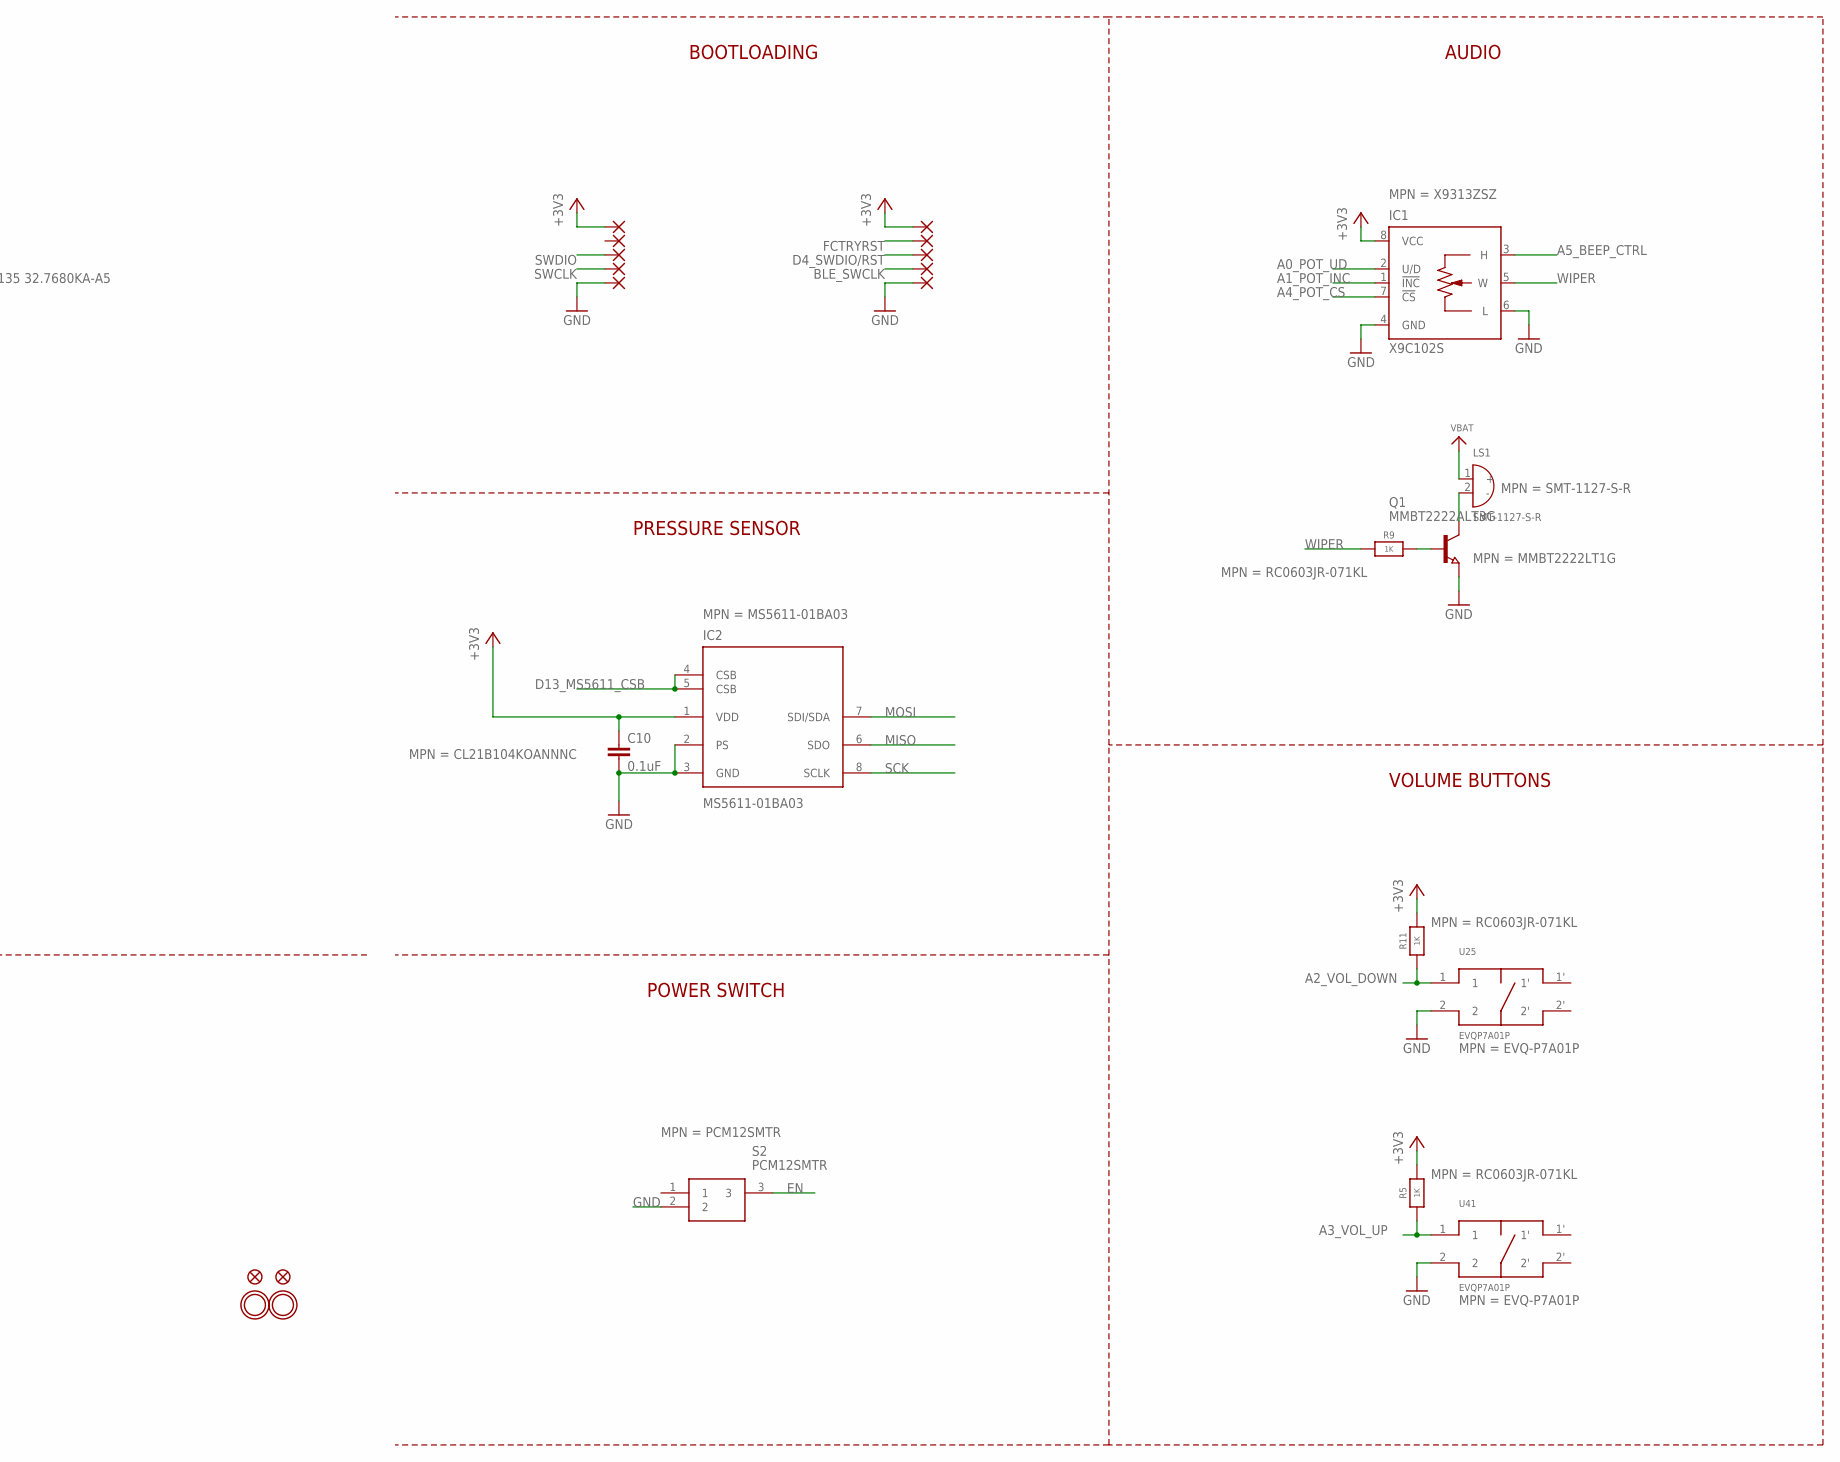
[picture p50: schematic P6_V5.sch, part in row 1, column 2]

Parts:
C1, C7, C14: 1uF; 0603-NO; MPN CL10A105KQ8NNNC
C2, C4: 22pF; 0603-NO; MPN CL10C220JB8NCNC
C3, C6, C8: 10µF; 0805-NO; MPN CL21A106KQCLRNC
C5, C9: 10uF; 0805-NO; MPN CL21A106KQCLRNC
C10: 0.1uF; C0805K; MPN CL21B104KOANNNC
CHG: ORANGE; CHIPLED_0805_NOOUTLINE; MPN XZMOK54W-1
D1: MBR120; SOD-123; MPN MBR120LSFT3G
D2: RED; CHIPLED_0805_NOOUTLINE; MPN XZMDK54W-1
D3: BLUE; CHIPLED_0805_NOOUTLINE; MPN XZCBD54W-1
IC1: X9C102S; SOIC08; MPN X9313ZSZ
IC2: MS5611-01BA03; SON125P300X500X100-8N; MPN MS5611-01BA03
L: RED; CHIPLED_0805_NOOUTLINE; MPN XZMDK54W-1
LS1: SMT-1127-S-R; XDCR_SMT-1127-S-R; MPN SMT-1127-S-R
PAD1, PAD2, PAD3, PAD4, PAD5, PAD6, PAD7, PAD8, PAD9, PAD10: 1,6/0,8
Q1: MMBT2222ALT3G; SOT23; MPN MMBT2222LT1G
R1, R3: 100k; 0603-NO; MPN RC0603JR-07100KL
R2, R5, R9, R11: 1K; 0603-NO; MPN RC0603JR-071KL
R4, R7, R10: 2.2K; 0603-NO; MPN RC0603JR-072K2L
R6: 100K; 0603-NO; MPN RC0603JR-07100KL
R8: 10K\; 0603-NO; MPN RC0603JR-0710KL
S2: PCM12SMTR; PCM12SMTR_1; MPN PCM12SMTR
SW1: SPST_TACT-KMR2; KMR2; MPN KMR231NG LFS
U1: MBT40; BLE_MODULE_RAYTAC_MDBT40; MPN MDBT40
U2: AP2112-3.3; SOT23-5; MPN AP2112K-3.3TRG1
U3: MCP73831T-2ACI/OT; SOT23-5; MPN MCP73831T-2ACI/OT
U4: ATSAMD21G18_QFN; TQFN48_7MM; MPN ATSAMD21G18A-MU
U25, U41: EVQP7A01P; MPN EVQ-P7A01P
U$31, U$32: MOUNTINGHOLE2.5; MOUNTINGHOLE_2.5_PLATED
U$34, U$35: FIDUCIAL""; FIDUCIAL_1MM
X1: JSTPH; JSTPH2; MPN S2B-PH-SM4-TB(LF)(SN)
X2: 32.768; XTAL3215; MPN FC-135 32.7680KA-A5
X3: 10118193-0001LF

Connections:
!RESET: SW1.1, SW1.3 (P1), U4.40 (/RESET)
+3V3: C5.1, C7.1, C8.1, C9.1, C10.1, IC1.8 (VCC), IC2.1 (VDD), PAD2.1, PAD6.1, R5.2, R11.2, U1.3 (AVDD), U1.14 (VDD), U2.5 (OUT), U4.6 (VDDA), U4.17 (VDDIO), U4.36 (VDDIO), U4.44 (VDDIN)
A0_POT_UD: IC1.2 (U/D), U4.3 (PA02/EINT2/AIN0/Y0/VOUT)
A1_POT_INC: IC1.1 (!INC), U4.7 (PB08/I8/AIN2/SERCOM4.0)
A2_VOL_DOWN: R11.1, U4.8 (PB09/I9/AIN3/SERCOM4.1), U25.1
A3_VOL_UP: R5.1, U4.9 (PA04/EINT4/VREFB/AIN4/SERCOM0.0), U41.1
A4_POT_CS: IC1.7 (!CS), U4.10 (PA05/EINT5/AIN5/SERCOM0.1)
A5_BEEP_CTRL: IC1.3 (H), U4.47 (PB02/I2/AIN10/SERCOM5.0)
AREF: C14.1, U4.4 (PA03/EINT3/VREFA/AIN1)
BLE_SWCLK: PAD9.1, U1.36 (SWCLK)
CONNECTED: R10.1, U1.39 (P0.19)
D0: U4.16 (PA11/I11/AIN19/SERCOM0+2.3/I2SF0)
D1: U4.15 (PA10/I10/AIN18/SERCOM0+2.2/I2SCK)
D2: U4.23 (PA14/I14/SERCOM2+4.2)
D3: U4.14 (PA09/I2C/I9/AIN17/SERCOM0+2.1/I2SMC)
D4_SWDIO/RST: PAD8.1, U1.35 (SWDIO/NRESET), U4.13 (PA08/I2C/AIN16/SERCOM0+2.0/I2SD1)
D5: U4.24 (PA15/I15/SERCOM3+4.3)
D6: U4.29 (PA20/I4/SERCOM3+5.2/I2SSC)
D7_BLE_IRQ: U1.8 (P0.25), U4.30 (PA21/I5/SERCOM3+5.3/I2SFS0)
D8_BLE_CS: U1.7 (P0.24), U4.11 (PA06/EINT6/AIN6/SERCOM0.2)
D9: R3.2, R6.1, U4.12 (PA07/I7/AIN7/SERCOM0.3/I2SD0)
D10: U4.27 (PA18/I2/SERCOM1+3.2)
D11: U4.25 (PA16/I2C/I0/SERCOM1+3.0)
D12: U4.28 (PA19/I3/SERCOM1+3.3/I2SD0)
D13_MS5611_CSB: IC2.4 (CSB), IC2.5 (CSB), R7.1, U4.26 (PA17/I2C/I1/SERCOM1+3.1)
D+: U4.34 (PA25/I13/SERCOM3+5.3/D+), X3.D+
D-: U4.33 (PA24/I12/SERCOM3+5.2/D-), X3.D-
DCC: U1.15 (DCC)
DEC2: U1.41 (DEC2)
DFU: U1.24 (P0.07)
EN: R1.2, S2.3, U2.3 (EN)
FCTRYRST: PAD7.1, U1.34 (P0.16)
GND: C1.2, C2.2, C3.2, C4.2, C5.2, C6.2, C7.2, C8.2, C9.2, C10.2, C14.2, D2.C, D3.C, IC1.4 (GND), IC1.6 (L), IC2.2 (PS), IC2.3 (GND), L.C, PAD5.1, PAD10.1, Q1.2 (E), R6.2, R8.2, S2.2, SW1.2 (S), SW1.4 (S1), U1.1 (GND), U1.2 (GND), U1.13 (GND), U1.16 (P0.30), U1.25 (GND), U1.42 (GND), U2.2 (GND), U3.2 (VSS), U4.5 (GNDA), U4.18 (GND), U4.35 (GND), U4.42 (GND), U4.THERMAL (GND), U25.2, U41.2, X1.1, X3.GND@P$1 (GND), X3.GND@P$2 (GND), X3.GND@P$5 (GND), X3.GND@P$6 (GND), X3.GND@P$7 (GND), X3.GND@P$8 (GND), X3.GND@P$9 (GND)
MISO: IC2.6 (SDO), U1.5 (P0.22), U4.21 (PA12/I12/I2C/SERCOM2+4.0)
MODE: R4.1, U1.38 (P0.18)
MOSI: IC2.7 (SDI/SDA), U1.6 (P0.23), U4.19 (PB10/I10/SERCOM4.2/I2SMC)
unnamed: CHG.C, R2.1
unnamed: L.A, R7.2
unnamed: R2.2, U3.1 (STAT)
unnamed: R8.1, U3.5 (PROG)
unnamed: C2.1, U4.1 (PA00/EINT0/SERCOM1.0), X2.P$1
unnamed: D2.A, R4.2
unnamed: C4.1, U4.2 (PA01/EINT1/SERCOM1.1), X2.P$2
unnamed: D3.A, R10.2
unnamed: Q1.1 (B), R9.2
unnamed: LS1.2 (-), Q1.3 (C)
SCK: IC2.8 (SCLK), U1.4 (P0.21), U4.20 (PB11/I11/SERCOM4.3/I2SCL)
SCL: U4.32 (PA23/I2C/I7/SERCOM3+5.1/SOF)
SDA: U4.31 (PA22/I2C/I6/SERCOM3+5.0)
SWCLK: PAD4.1, U4.45 (PA30/I10/SECOM1.2/SWCLK)
SWDIO: PAD3.1, U4.46 (PA31/I11/SECOM1.3/SWDIO)
VBAT: C3.1, D1.A, LS1.1 (+), R3.1, U3.3 (VBAT), X1.2
VBUS: C6.1, CHG.A, D1.C, R1.1, U2.1 (IN), U3.4 (VDD), X3.VBUS
VDDCORE: C1.1, U4.43 (VDDCORE)
WIPER: IC1.5 (W), R9.1

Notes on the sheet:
POWER AND FILTERING
RESET
10K = 100mA
5.0K = 200mA
2.0K = 500mA
1.0K = 1000mA
N/C
TXLED
USBHOSTEN
RXLED
TXD
RXD
BLUEFRUIT LE MODULE (nRF51)
ATSAMD21
USB & Batt Charging
Breakouts & D13 LED
BOOTLOADING
PRESSURE SENSOR
AUDIO
POWER SWITCH
VOLUME BUTTONS

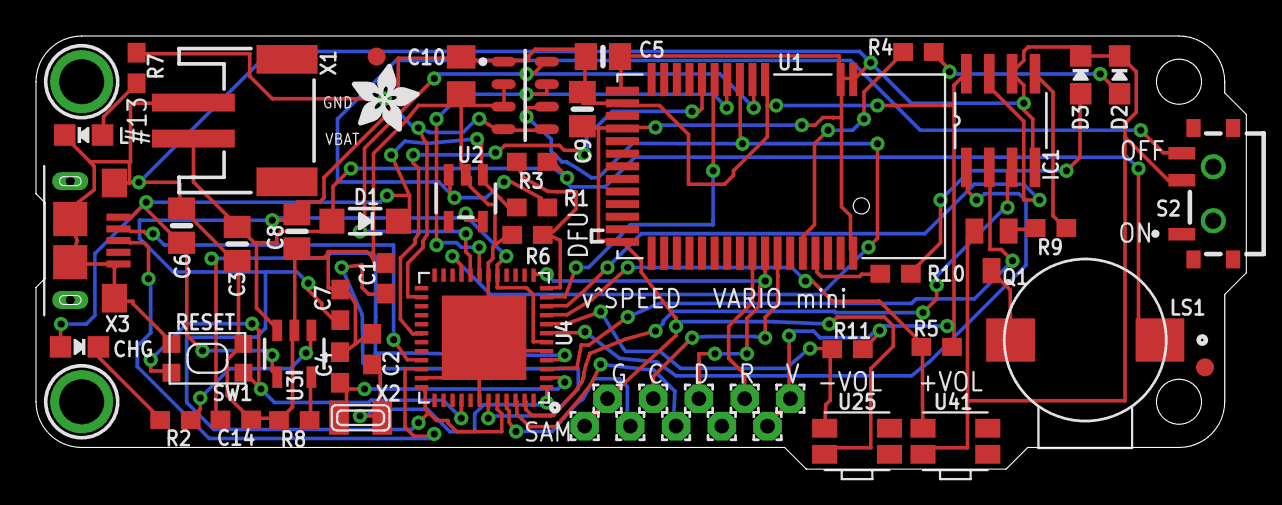
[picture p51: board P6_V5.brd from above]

Board: 2 copper layers, 67.2 x 24.1 mm, 57 parts (0 on the bottom side), 41 nets.

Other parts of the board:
U$7: ADAFRUIT_3.5MM

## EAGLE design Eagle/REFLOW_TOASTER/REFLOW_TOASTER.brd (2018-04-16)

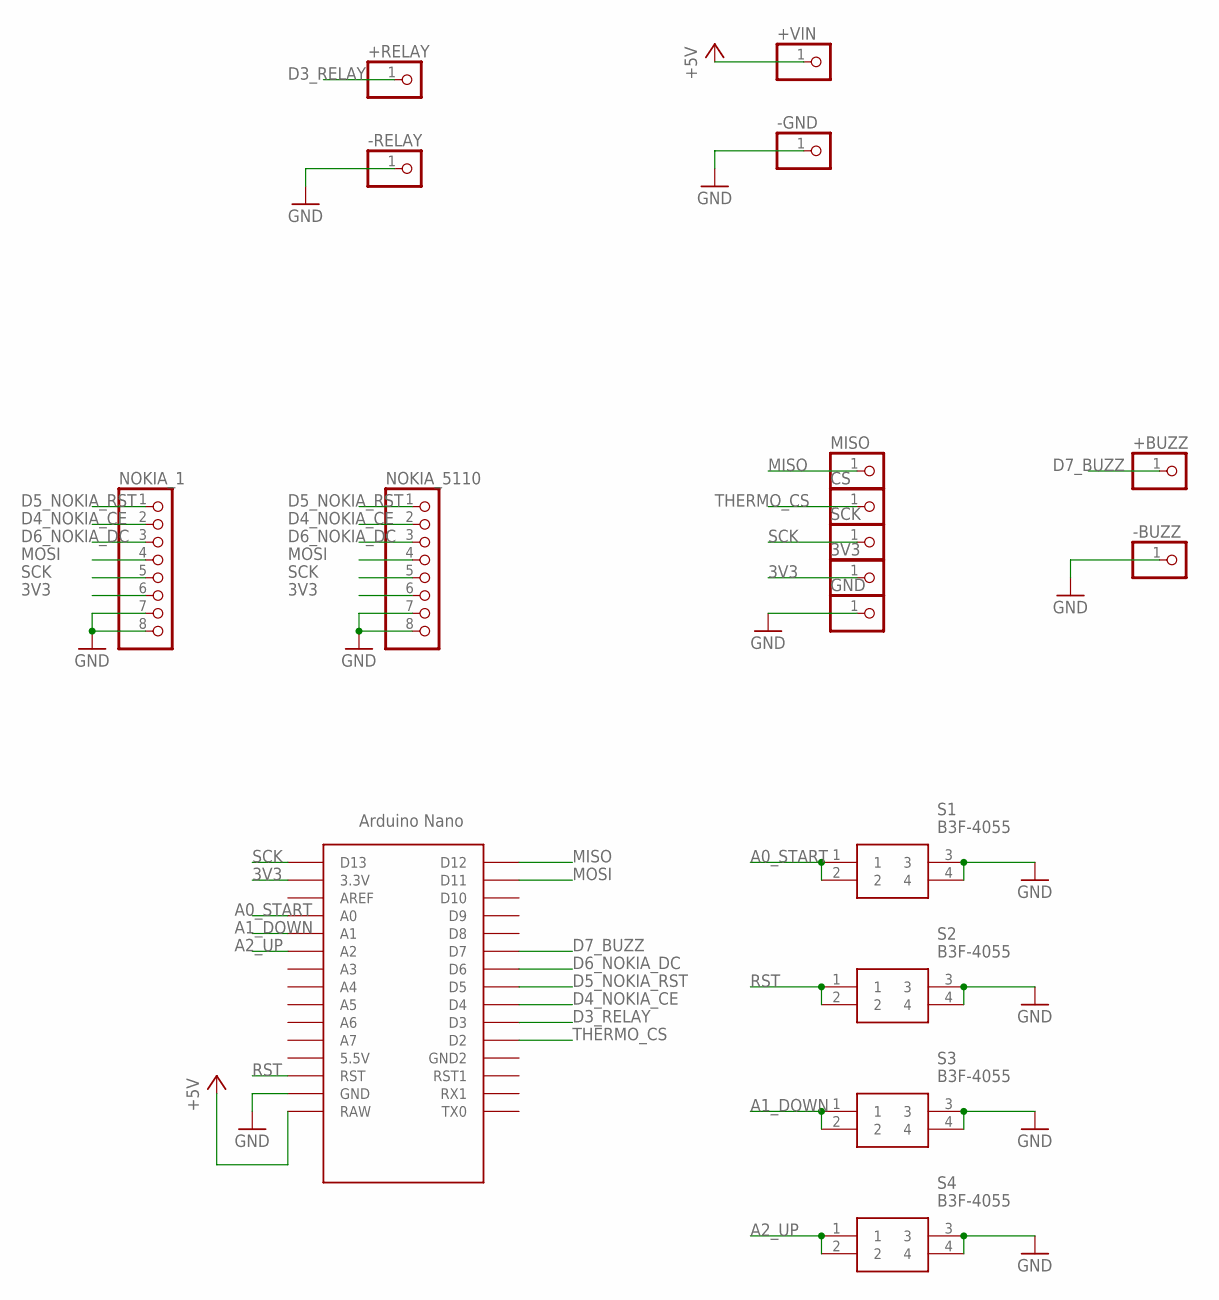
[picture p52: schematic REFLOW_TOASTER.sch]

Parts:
3V3: PINHD-1X1CB; 1X01-CLEANBIG
+BUZZ: PINHD-1X1CB; 1X01-CLEANBIG
+RELAY: PINHD-1X1CB; 1X01-CLEANBIG
+VIN: PINHD-1X1CB; 1X01-CLEANBIG
-BUZZ: PINHD-1X1CB; 1X01-CLEANBIG
-GND: PINHD-1X1CB; 1X01-CLEANBIG
-RELAY: PINHD-1X1CB; 1X01-CLEANBIG
CS: PINHD-1X1CB; 1X01-CLEANBIG
GND: PINHD-1X1CB; 1X01-CLEANBIG
MISO: PINHD-1X1CB; 1X01-CLEANBIG
NOKIA_1, NOKIA_5110: PINHD-1X8CLEANBIG; 1X08-CLEANBIG
S1, S2, S3, S4: B3F-4055
SCK: PINHD-1X1CB; 1X01-CLEANBIG
U$1: NANO

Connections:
3V3: 3V3.1, NOKIA_1.6, NOKIA_5110.6, U$1.3.3V
+5V: +VIN.1, U$1.RAW
A0_START: S1.1, S1.2, U$1.A0
A1_DOWN: S3.1, S3.2, U$1.A1
A2_UP: S4.1, S4.2, U$1.A2
D3_RELAY: +RELAY.1, U$1.D3
D4_NOKIA_CE: NOKIA_1.2, NOKIA_5110.2, U$1.D4
D5_NOKIA_RST: NOKIA_1.1, NOKIA_5110.1, U$1.D5
D6_NOKIA_DC: NOKIA_1.3, NOKIA_5110.3, U$1.D6
D7_BUZZ: +BUZZ.1, U$1.D7
GND: -BUZZ.1, -GND.1, -RELAY.1, GND.1, NOKIA_1.7, NOKIA_1.8, NOKIA_5110.7, NOKIA_5110.8, S1.3, S1.4, S2.3, S2.4, S3.3, S3.4, S4.3, S4.4, U$1.GND
MISO: MISO.1, U$1.D12
MOSI: NOKIA_1.4, NOKIA_5110.4, U$1.D11
RST: S2.1, S2.2, U$1.RST
SCK: NOKIA_1.5, NOKIA_5110.5, SCK.1, U$1.D13
THERMO_CS: CS.1, U$1.D2

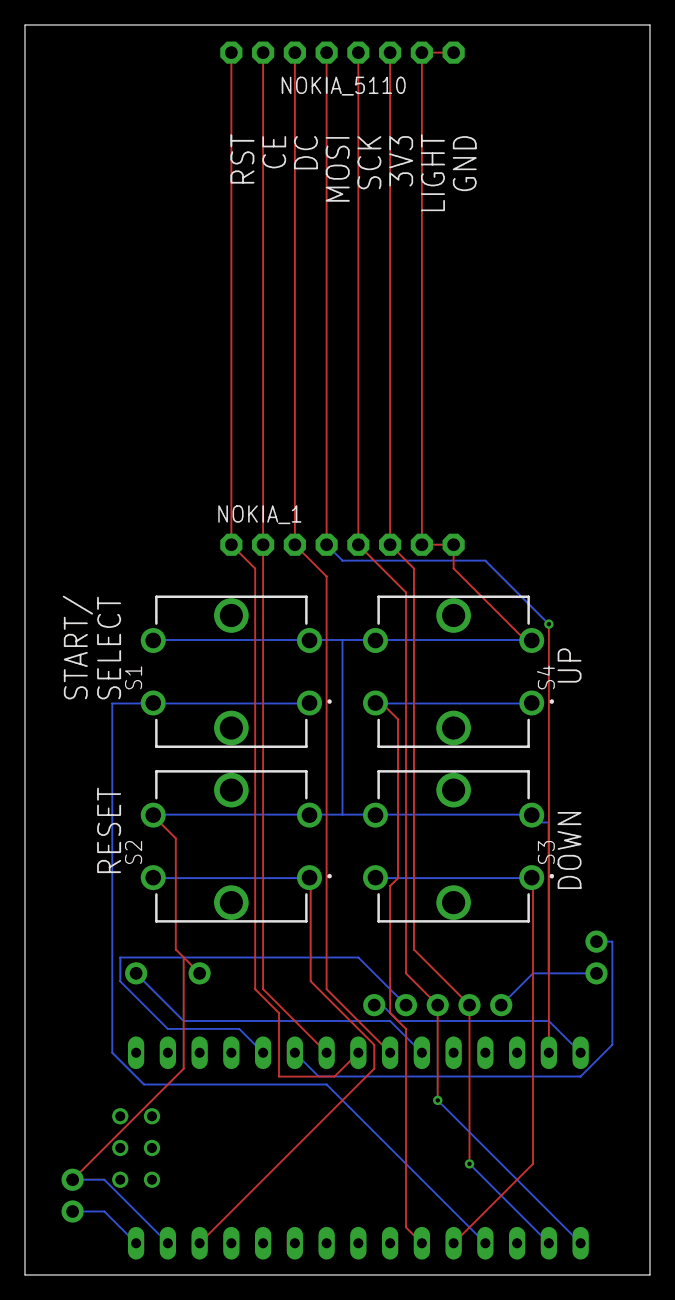
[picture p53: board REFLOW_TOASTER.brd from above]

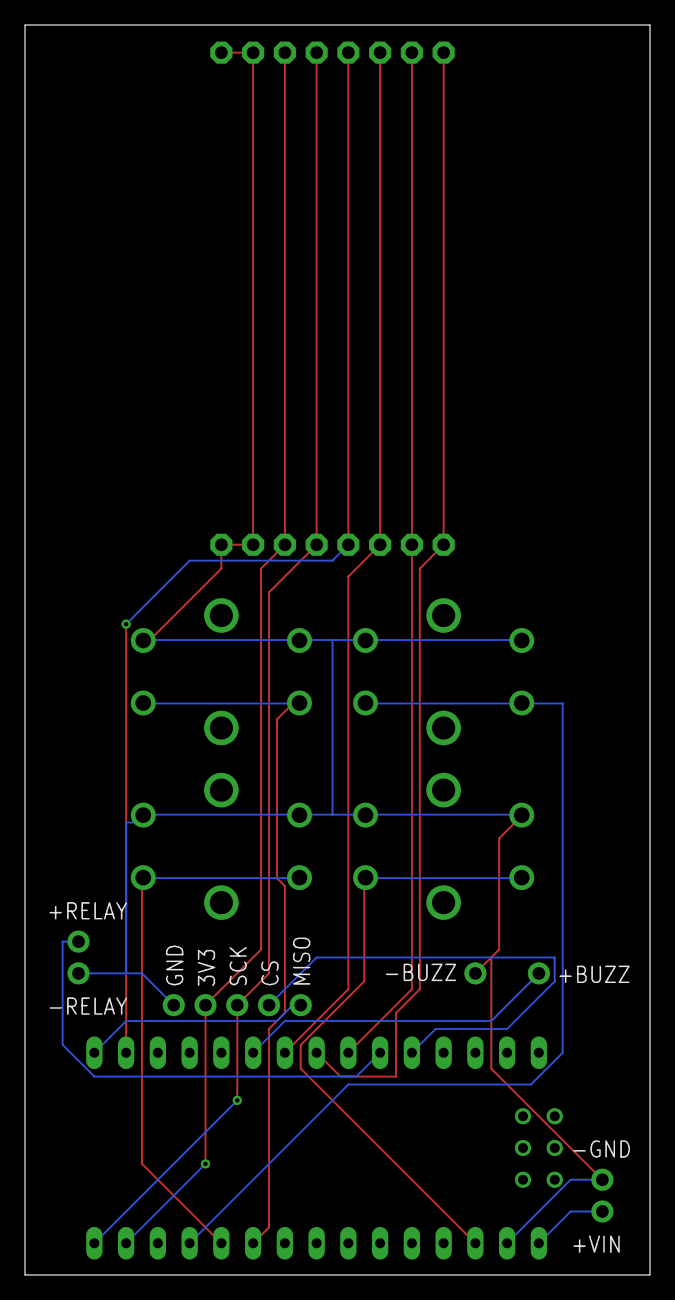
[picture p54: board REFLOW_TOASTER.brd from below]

Board: 2 copper layers, 50.0 x 100.0 mm, 18 parts (5 on the bottom side), 16 nets.

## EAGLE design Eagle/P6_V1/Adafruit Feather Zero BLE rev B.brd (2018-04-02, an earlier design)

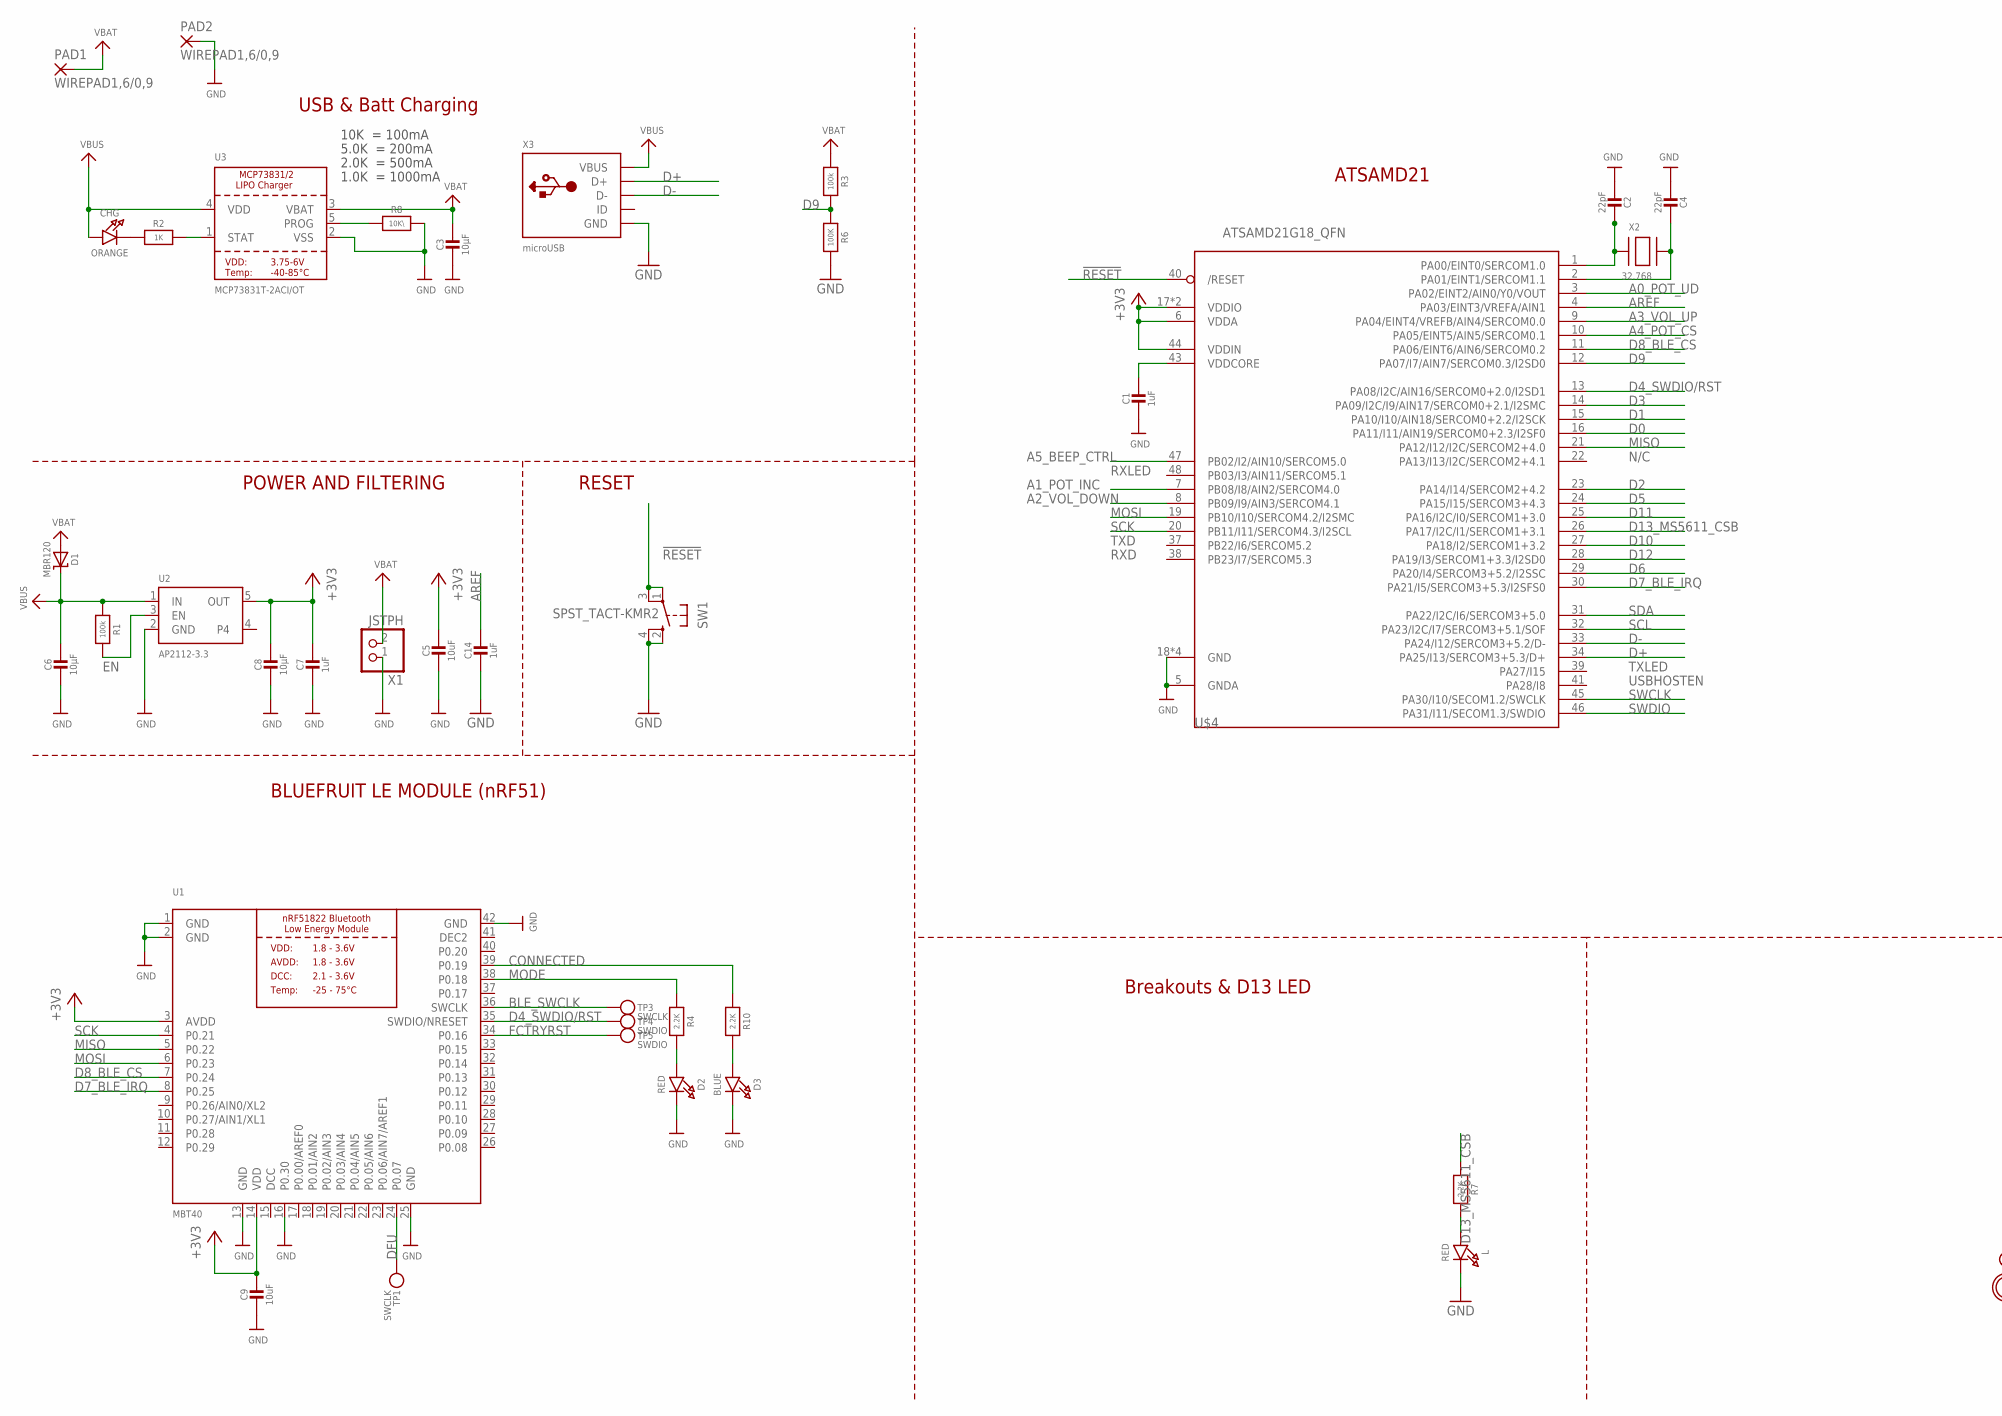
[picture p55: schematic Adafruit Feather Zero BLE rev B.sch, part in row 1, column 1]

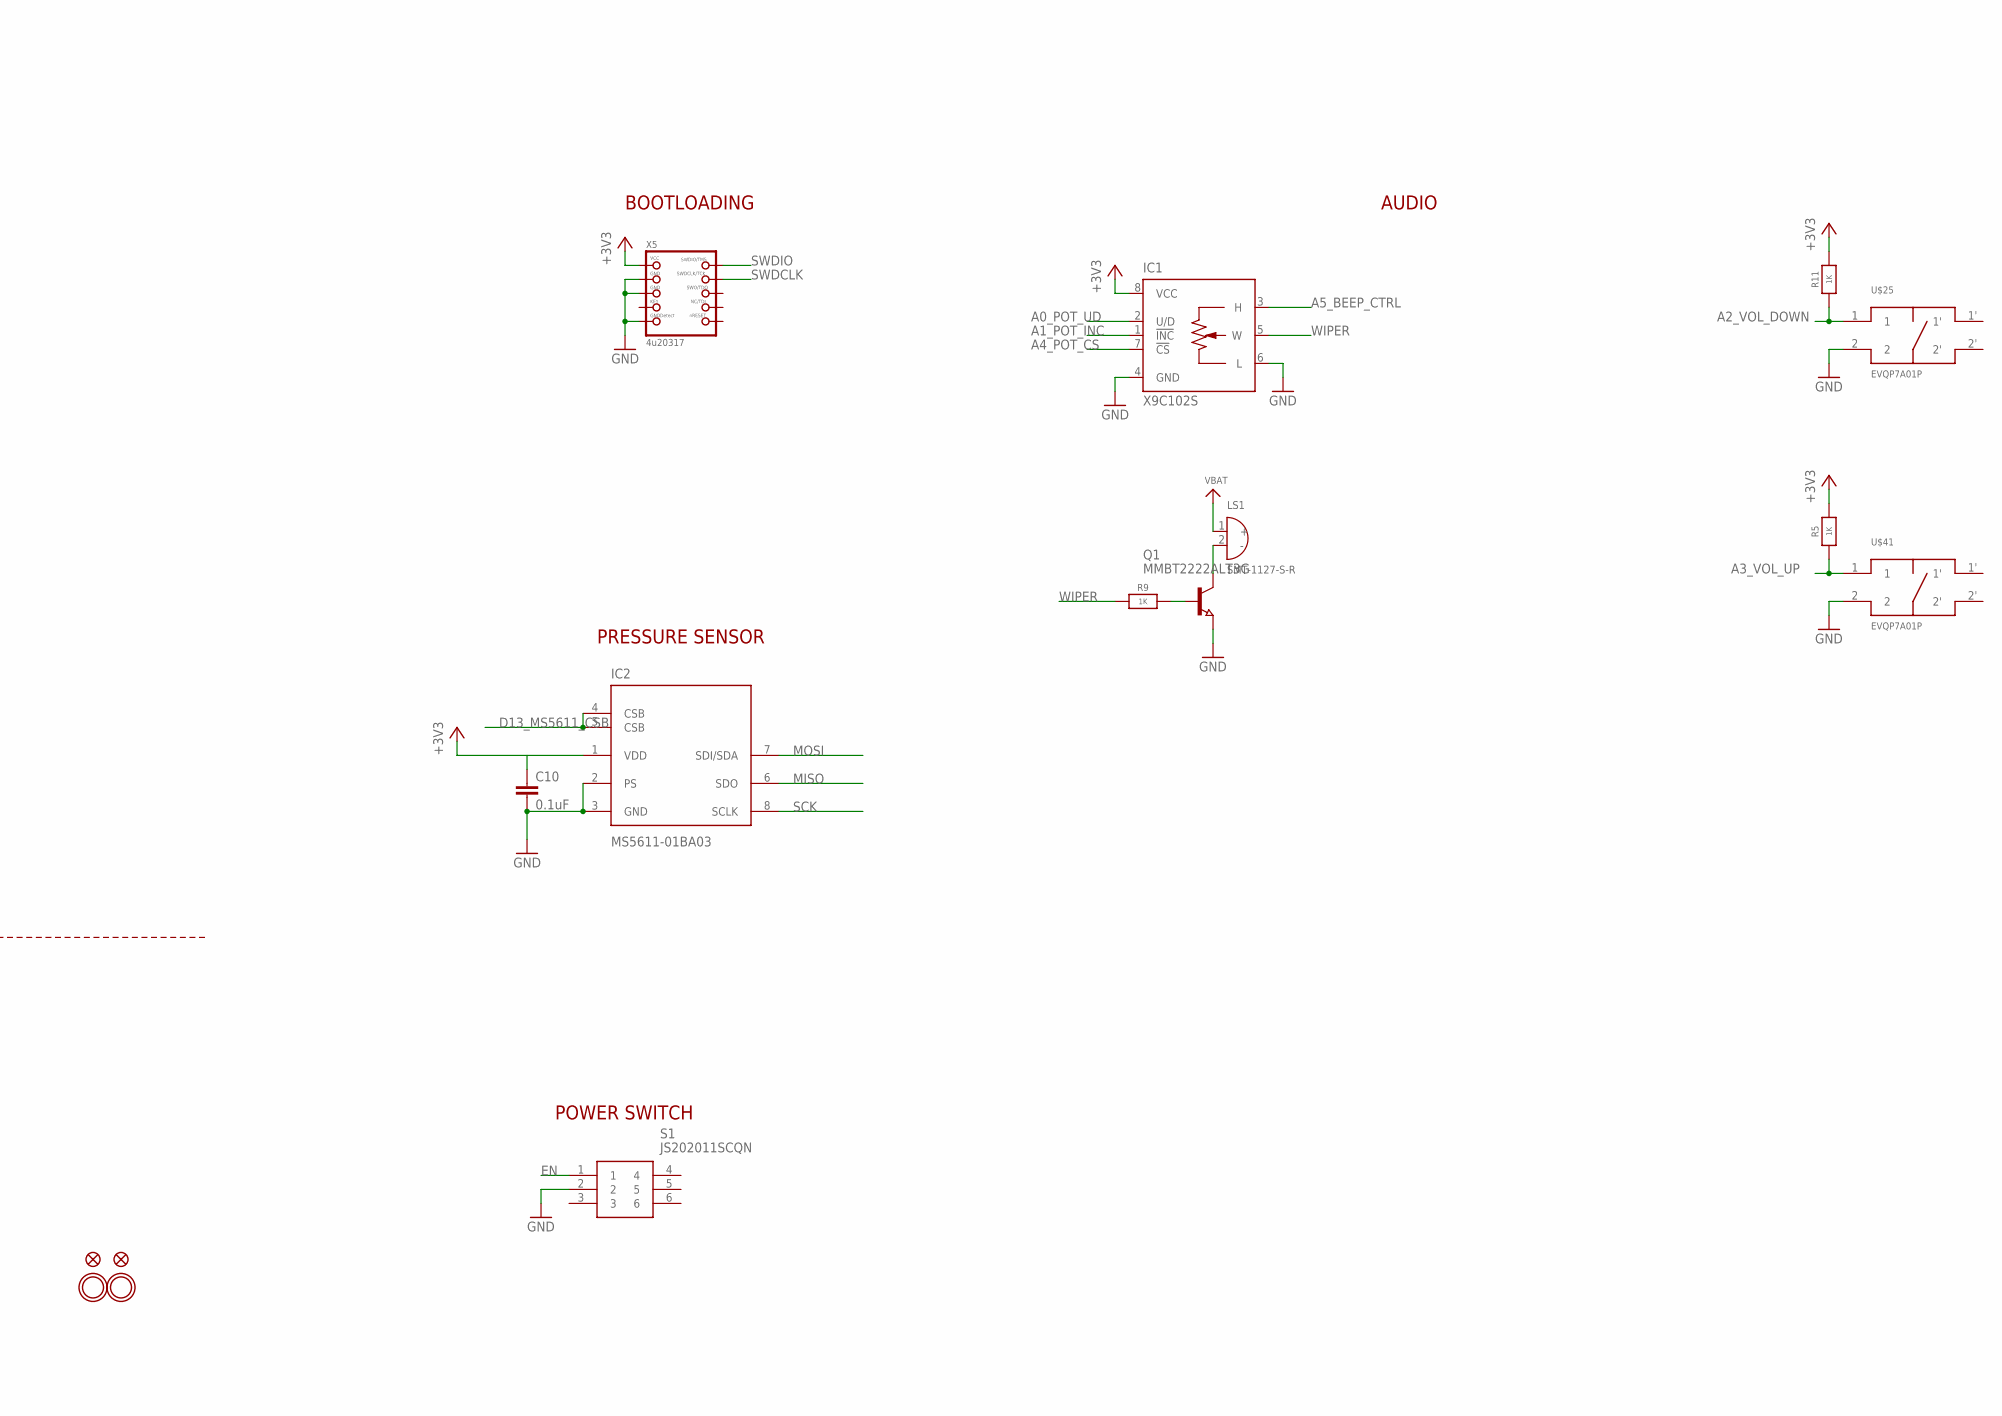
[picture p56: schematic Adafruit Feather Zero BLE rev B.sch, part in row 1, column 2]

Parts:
C1, C7, C14: 1uF; 0603-NO
C2, C4: 22pF; 0603-NO
C3, C6, C8: 10µF; 0805-NO
C5, C9: 10uF; 0805-NO
C10: 0.1uF; C0805K
CHG: ORANGE; CHIPLED_0805_NOOUTLINE
D1: MBR120; SOD-123
D2: RED; CHIPLED_0805_NOOUTLINE
D3: BLUE; CHIPLED_0805_NOOUTLINE
IC1: X9C102S; SOIC08
IC2: MS5611-01BA03; SON125P300X500X100-8N
L: RED; CHIPLED_0805_NOOUTLINE
LS1: SMT-1127-S-R; XDCR_SMT-1127-S-R
PAD1, PAD2: WIREPAD1,6/0,9; 1,6/0,9
Q1: MMBT2222ALT3G; SOT23
R1, R3: 100k; 0603-NO
R2, R5, R9, R11: 1K; 0603-NO
R4, R7, R10: 2.2K; 0603-NO
R6: 100K; 0603-NO
R8: 10K\; 0603-NO
S1: JS202011SCQN
SW1: SPST_TACT-KMR2; KMR2
TP1, TP3: SWCLK; PAD-1.5X2.0
TP4, TP5: SWDIO; PAD-1.5X2.0
U1: MBT40; BLE_MODULE_RAYTAC_MDBT40
U2: AP2112-3.3; SOT23-5
U3: MCP73831T-2ACI/OT; SOT23-5
U$4: ATSAMD21G18_QFN; TQFN48_7MM
U$25, U$41: EVQP7A01P
U$31, U$32: MOUNTINGHOLE2.5; MOUNTINGHOLE_2.5_PLATED
U$34, U$35: FIDUCIAL""; FIDUCIAL_1MM
X1: JSTPH; JSTPH2
X2: 32.768; XTAL3215
X3: microUSB; 4UCONN_20329_V2
X5: 4u20317; 2X05_1.27MM_BOX_POSTS

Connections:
!RESET: SW1.1, SW1.3 (P1), U$4.40 (/RESET)
+3V3: C5.1, C7.1, C8.1, C9.1, C10.1, IC1.8 (VCC), IC2.1 (VDD), R5.2, R11.2, U1.3 (AVDD), U1.14 (VDD), U2.5 (OUT), U$4.6 (VDDA), U$4.17 (VDDIO), U$4.36 (VDDIO), U$4.44 (VDDIN), X5.1 (VCC)
A0_POT_UD: IC1.2 (U/D), U$4.3 (PA02/EINT2/AIN0/Y0/VOUT)
A1_POT_INC: IC1.1 (!INC), U$4.7 (PB08/I8/AIN2/SERCOM4.0)
A2_VOL_DOWN: R11.1, U$4.8 (PB09/I9/AIN3/SERCOM4.1), U$25.1
A3_VOL_UP: R5.1, U$4.9 (PA04/EINT4/VREFB/AIN4/SERCOM0.0), U$41.1
A4_POT_CS: IC1.7 (!CS), U$4.10 (PA05/EINT5/AIN5/SERCOM0.1)
A5_BEEP_CTRL: IC1.3 (H), U$4.47 (PB02/I2/AIN10/SERCOM5.0)
AREF: C14.1, U$4.4 (PA03/EINT3/VREFA/AIN1)
BLE_SWCLK: TP3.P$1, U1.36 (SWCLK)
CONNECTED: R10.1, U1.39 (P0.19)
D0: U$4.16 (PA11/I11/AIN19/SERCOM0+2.3/I2SF0)
D1: U$4.15 (PA10/I10/AIN18/SERCOM0+2.2/I2SCK)
D2: U$4.23 (PA14/I14/SERCOM2+4.2)
D3: U$4.14 (PA09/I2C/I9/AIN17/SERCOM0+2.1/I2SMC)
D4_SWDIO/RST: TP4.P$1, U1.35 (SWDIO/NRESET), U$4.13 (PA08/I2C/AIN16/SERCOM0+2.0/I2SD1)
D5: U$4.24 (PA15/I15/SERCOM3+4.3)
D6: U$4.29 (PA20/I4/SERCOM3+5.2/I2SSC)
D7_BLE_IRQ: U1.8 (P0.25), U$4.30 (PA21/I5/SERCOM3+5.3/I2SFS0)
D8_BLE_CS: U1.7 (P0.24), U$4.11 (PA06/EINT6/AIN6/SERCOM0.2)
D9: R3.2, R6.1, U$4.12 (PA07/I7/AIN7/SERCOM0.3/I2SD0)
D10: U$4.27 (PA18/I2/SERCOM1+3.2)
D11: U$4.25 (PA16/I2C/I0/SERCOM1+3.0)
D12: U$4.28 (PA19/I3/SERCOM1+3.3/I2SD0)
D13_MS5611_CSB: IC2.4 (CSB), IC2.5 (CSB), R7.1, U$4.26 (PA17/I2C/I1/SERCOM1+3.1)
D+: U$4.34 (PA25/I13/SERCOM3+5.3/D+), X3.D+
D-: U$4.33 (PA24/I12/SERCOM3+5.2/D-), X3.D-
DCC: U1.15 (DCC)
DEC2: U1.41 (DEC2)
DFU: TP1.P$1, U1.24 (P0.07)
EN: R1.2, S1.1, U2.3 (EN)
FCTRYRST: TP5.P$1, U1.34 (P0.16)
GND: C1.2, C2.2, C3.2, C4.2, C5.2, C6.2, C7.2, C8.2, C9.2, C10.2, C14.2, D2.C, D3.C, IC1.4 (GND), IC1.6 (L), IC2.2 (PS), IC2.3 (GND), L.C, PAD2.1, Q1.2 (E), R6.2, R8.2, S1.2, SW1.2 (S), SW1.4 (S1), U1.1 (GND), U1.2 (GND), U1.13 (GND), U1.16 (P0.30), U1.25 (GND), U1.42 (GND), U2.2 (GND), U3.2 (VSS), U$4.5 (GNDA), U$4.18 (GND), U$4.35 (GND), U$4.42 (GND), U$4.THERMAL (GND), U$25.2, U$41.2, X1.1, X3.BASE@1 (GND), X3.BASE@2 (GND), X3.GND, X3.SPRT@1 (GND), X3.SPRT@2 (GND), X3.SPRT@3 (GND), X3.SPRT@4 (GND), X5.3 (GND), X5.5 (GND), X5.9 (GNDDETECT)
MISO: IC2.6 (SDO), U1.5 (P0.22), U$4.21 (PA12/I12/I2C/SERCOM2+4.0)
MODE: R4.1, U1.38 (P0.18)
MOSI: IC2.7 (SDI/SDA), U1.6 (P0.23), U$4.19 (PB10/I10/SERCOM4.2/I2SMC)
unnamed: CHG.C, R2.1
unnamed: L.A, R7.2
unnamed: R2.2, U3.1 (STAT)
unnamed: R8.1, U3.5 (PROG)
unnamed: C2.1, U$4.1 (PA00/EINT0/SERCOM1.0), X2.P$1
unnamed: D2.A, R4.2
unnamed: C4.1, U$4.2 (PA01/EINT1/SERCOM1.1), X2.P$2
unnamed: D3.A, R10.2
unnamed: Q1.1 (B), R9.2
unnamed: LS1.2 (-), Q1.3 (C)
SCK: IC2.8 (SCLK), U1.4 (P0.21), U$4.20 (PB11/I11/SERCOM4.3/I2SCL)
SCL: U$4.32 (PA23/I2C/I7/SERCOM3+5.1/SOF)
SDA: U$4.31 (PA22/I2C/I6/SERCOM3+5.0)
SWCLK: U$4.45 (PA30/I10/SECOM1.2/SWCLK)
SWDCLK: X5.4 (SWDCLK)
SWDIO: U$4.46 (PA31/I11/SECOM1.3/SWDIO), X5.2 (SWDIO)
VBAT: C3.1, D1.A, LS1.1 (+), PAD1.1, R3.1, U3.3 (VBAT), X1.2
VBUS: C6.1, CHG.A, D1.C, R1.1, U2.1 (IN), U3.4 (VDD), X3.VBUS
VDDCORE: C1.1, U$4.43 (VDDCORE)
WIPER: IC1.5 (W), R9.1

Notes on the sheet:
POWER AND FILTERING
RESET
10K = 100mA
5.0K = 200mA
2.0K = 500mA
1.0K = 1000mA
N/C
TXLED
USBHOSTEN
RXLED
TXD
RXD
BLUEFRUIT LE MODULE (nRF51)
ATSAMD21
USB & Batt Charging
Breakouts & D13 LED
BOOTLOADING
PRESSURE SENSOR
AUDIO
POWER SWITCH

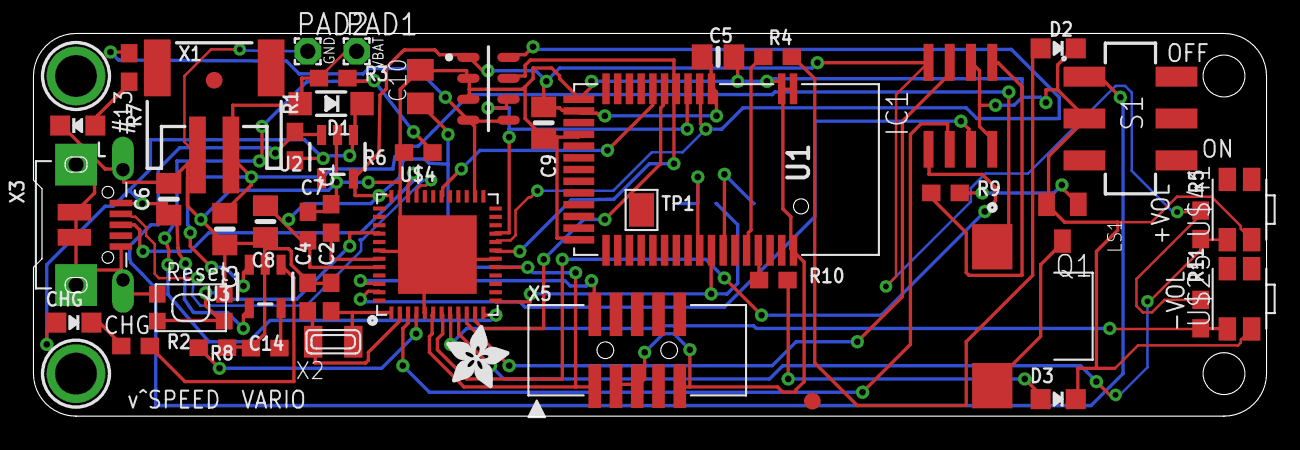
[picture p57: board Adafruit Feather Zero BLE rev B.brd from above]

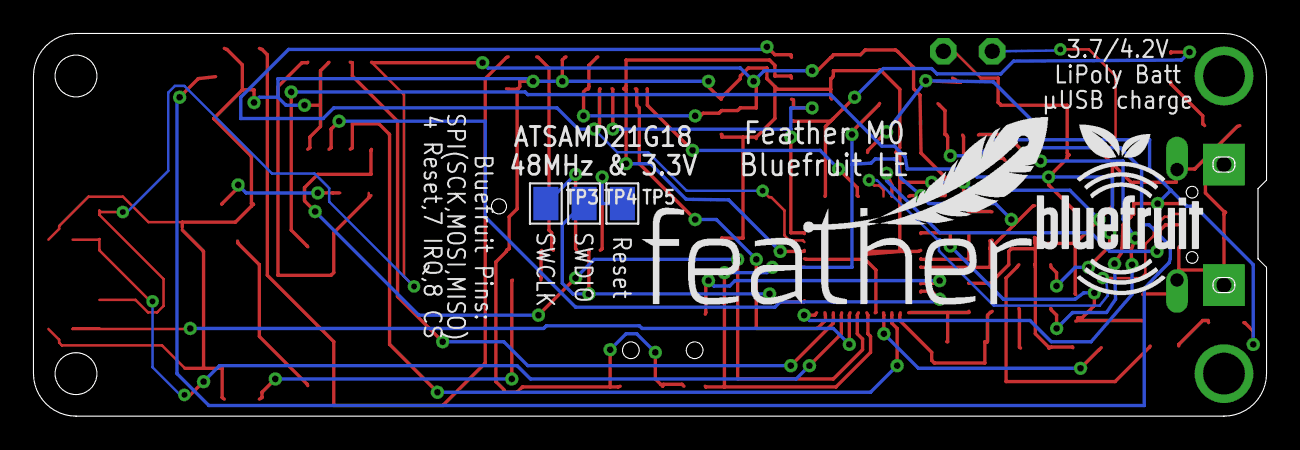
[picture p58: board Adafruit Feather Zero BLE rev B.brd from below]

Board: 2 copper layers, 73.7 x 22.9 mm, 56 parts (5 on the bottom side), 41 nets.

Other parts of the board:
U$7: ADAFRUIT_3.5MM
U$9: FEATHERLOGO
U$26: BLUEFRUITLOGO_100MM

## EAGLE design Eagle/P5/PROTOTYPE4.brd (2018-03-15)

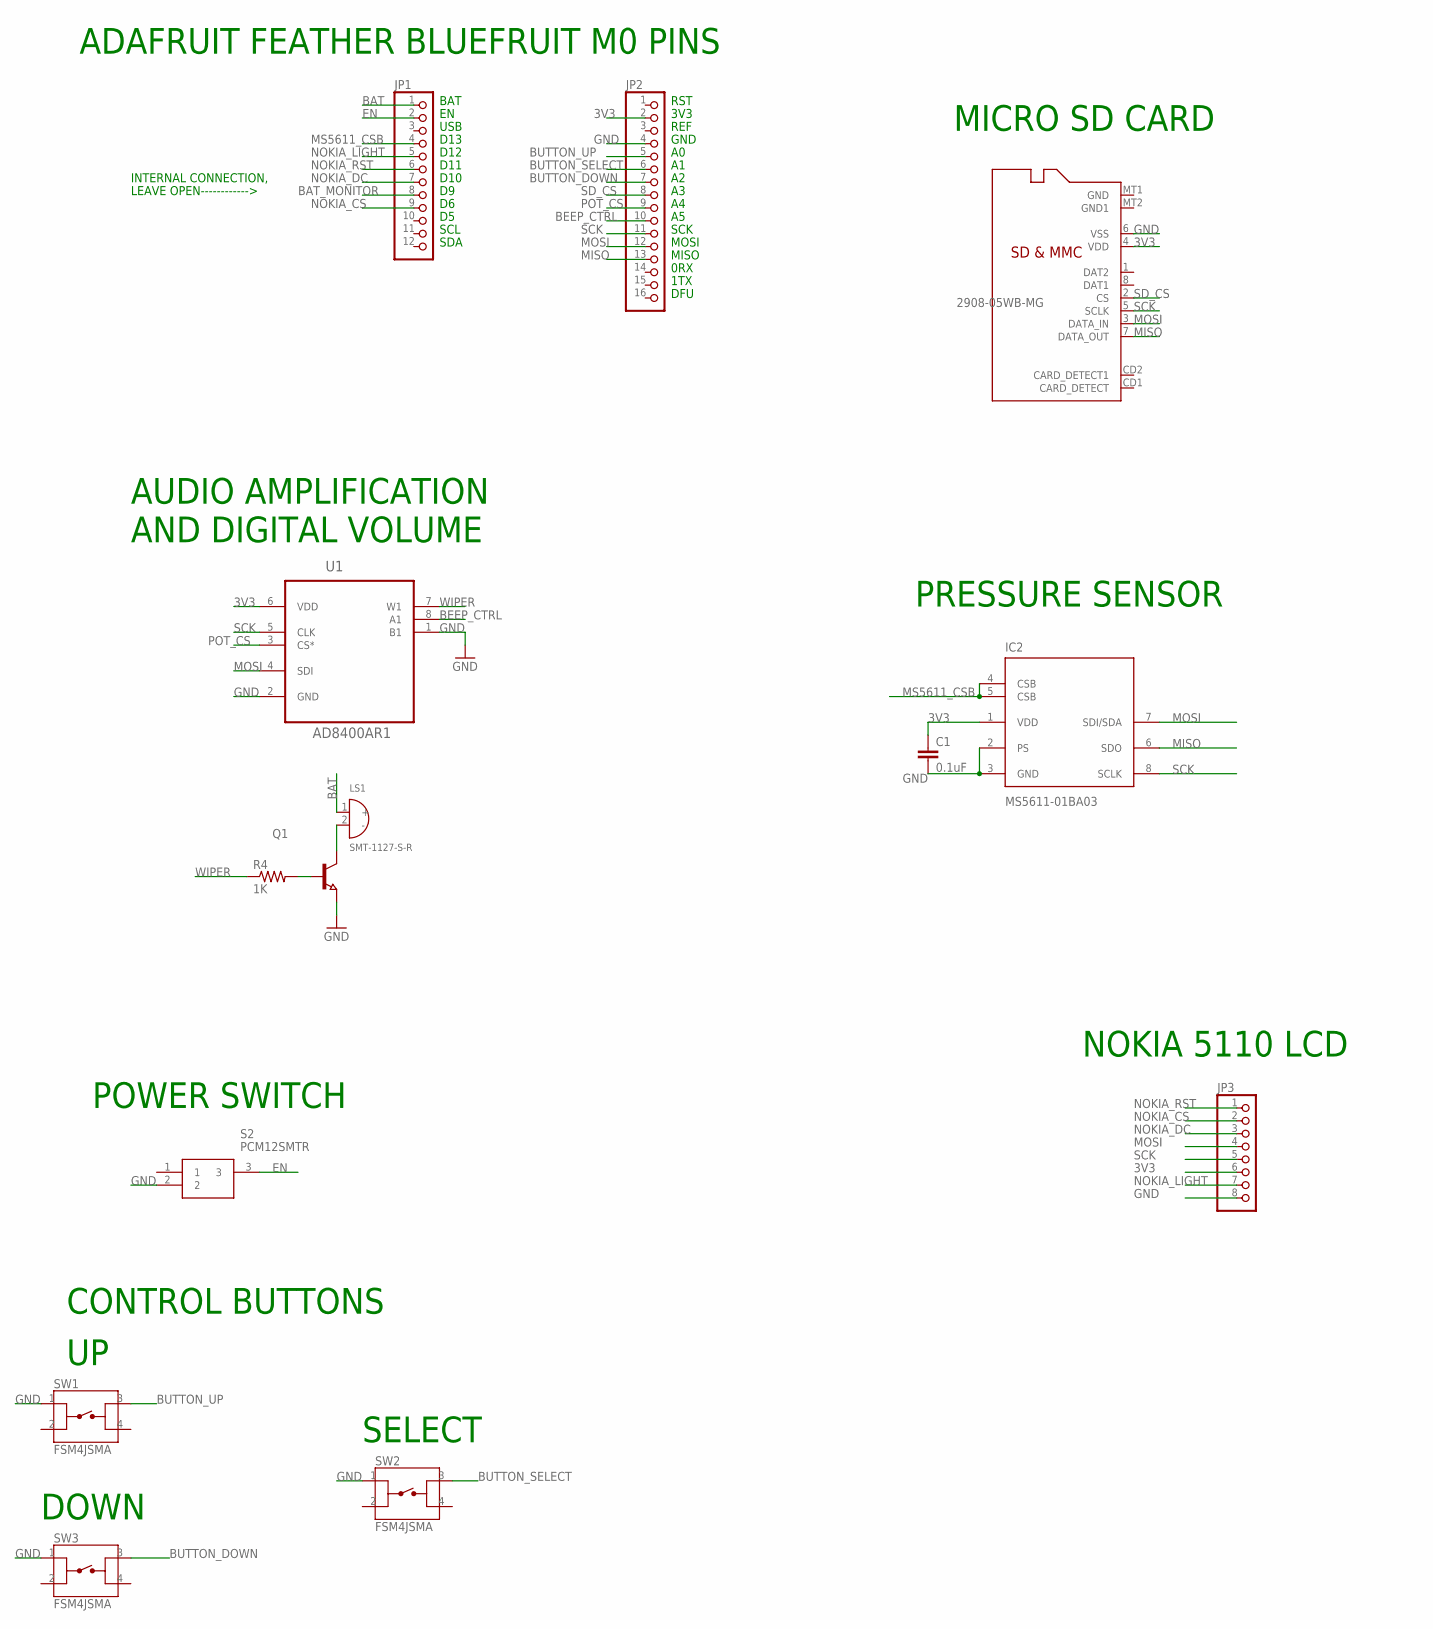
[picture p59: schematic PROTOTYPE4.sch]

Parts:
C1: 0.1uF; C0805K
IC2: MS5611-01BA03; SON125P300X500X100-8N
JP1: PINHD-1X12; 1X12
JP2: PINHD-1X16; 1X16
JP3: PINHD-1X8; 1X08
LS1: SMT-1127-S-R; XDCR_SMT-1127-S-R
Q1: NPN-TRANSISTOR_SOT23; SOT23
R4: 1K; R0805
S2: PCM12SMTR; PCM12SMTR_1
SW1, SW2, SW3: FSM4JSMA; TE_FSM4JSMA
U1: AD8400AR1; SOIC127P600X175-8N
U$1: 2908-05WB-MG; MICROSD

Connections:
3V3: C1.1, IC2.1 (VDD), JP2.2, JP3.6, U1.6 (VDD), U$1.4 (VDD)
BAT: JP1.1, LS1.1 (+)
BAT_MONITOR: JP1.8
BEEP_CTRL: JP2.10, U1.8 (A1)
BUTTON_DOWN: JP2.7, SW3.3
BUTTON_SELECT: JP2.6, SW2.3
BUTTON_UP: JP2.5, SW1.3
EN: JP1.2, S2.3
GND: C1.2, IC2.2 (PS), IC2.3 (GND), JP2.4, JP3.8, Q1.2 (E), S2.2, SW1.1, SW2.1, SW3.1, U1.1 (B1), U1.2 (GND), U$1.6 (VSS)
MISO: IC2.6 (SDO), JP2.13, U$1.7 (DATA_OUT)
MOSI: IC2.7 (SDI/SDA), JP2.12, JP3.4, U1.4 (SDI), U$1.3 (DATA_IN)
MS5611_CSB: IC2.4 (CSB), IC2.5 (CSB), JP1.4
unnamed: Q1.1 (B), R4.2
unnamed: LS1.2 (-), Q1.3 (C)
NOKIA_CS: JP1.9, JP3.2
NOKIA_DC: JP1.7, JP3.3
NOKIA_LIGHT: JP1.5, JP3.7
NOKIA_RST: JP1.6, JP3.1
POT_CS: JP2.9, U1.3 (CS*)
SCK: IC2.8 (SCLK), JP2.11, JP3.5, U1.5 (CLK), U$1.5 (SCLK)
SD_CS: JP2.8, U$1.2 (CS)
WIPER: R4.1, U1.7 (W1)

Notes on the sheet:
ADAFRUIT FEATHER BLUEFRUIT M0 PINS
DOWN
MICRO SD CARD
PRESSURE SENSOR
AUDIO AMPLIFICATION AND DIGITAL VOLUME
NOKIA 5110 LCD
LEAVE OPEN------------>
INTERNAL CONNECTION,
POWER SWITCH
SELECT
CONTROL BUTTONS
D10
D11
D12
D13
USB
BAT
SCL
SDA
RST
3V3
REF
GND
SCK
MOSI
MISO
0RX
1TX
DFU

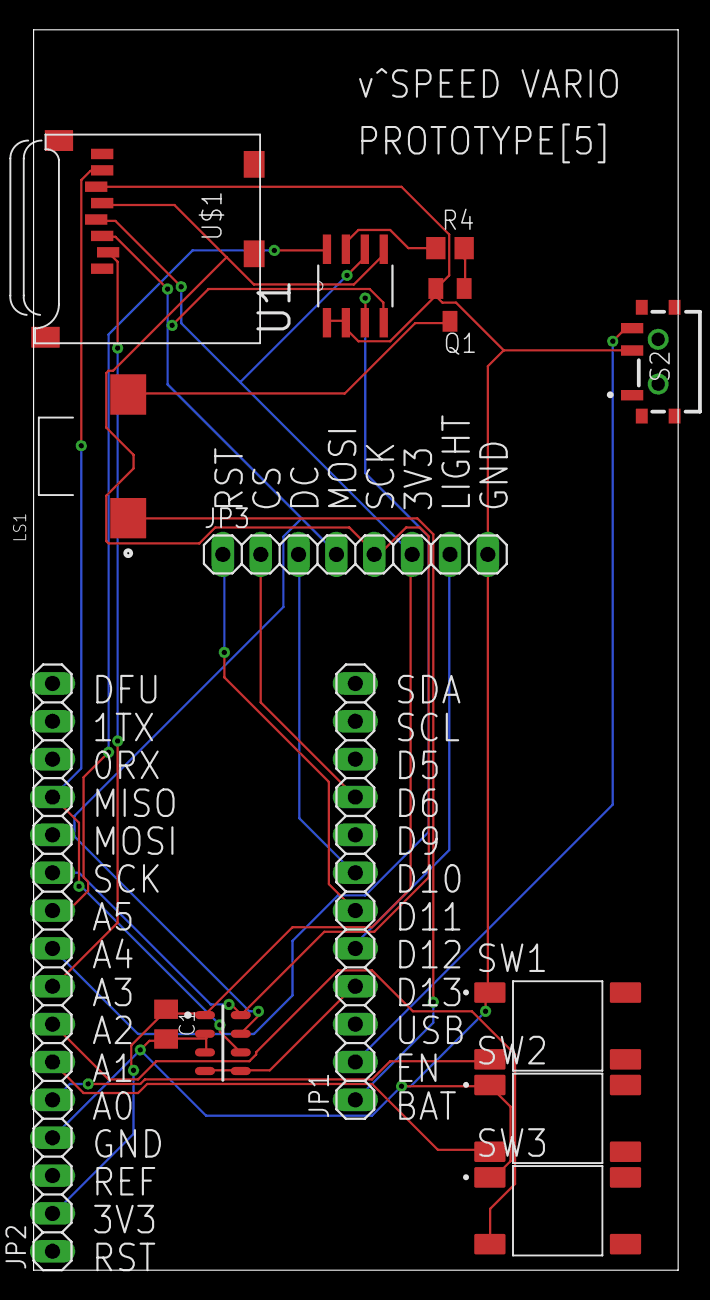
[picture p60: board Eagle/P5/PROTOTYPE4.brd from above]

Board: 2 copper layers, 43.2 x 83.2 mm, 14 parts (0 on the bottom side), 21 nets.

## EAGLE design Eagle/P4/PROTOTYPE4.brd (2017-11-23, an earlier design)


Board: 2 copper layers, 38.0 x 66.0 mm, 48 parts (0 on the bottom side), 23 nets.

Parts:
0RX, 1TX, 3V3: SMD1,27-2,54
A0, A1, A2, A3, A4, A5: SMD1,27-2,54
BAT: SMD1,27-2,54
C1: 0.1uF; C0805K
D5, D6, D9, D10, D11, D12, D13: SMD1,27-2,54
DFU: SMD1,27-2,54
EN: SMD1,27-2,54
EPD_3V3: SMD1,27-2,54
EPD_BUSY: SMD1,27-2,54
EPD_CS: SMD1,27-2,54
EPD_DC: SMD1,27-2,54
EPD_GND: SMD1,27-2,54
EPD_MOSI: SMD1,27-2,54
EPD_RST: SMD1,27-2,54
EPD_SCK: SMD1,27-2,54
GND: SMD1,27-2,54
IC1: 74HC00D; SO14
IC2: MS5611-01BA03; SON125P300X500X100-8N
LS1: SMT-1127-S-R; XDCR_SMT-1127-S-R
MISO: SMD1,27-2,54
MOSI: SMD1,27-2,54
Q1: SOT23
R1, R4: 1K; R0805
R2: 30K; R0805
R3: 10K; R0805
REF: SMD1,27-2,54
RST: SMD1,27-2,54
S1: B3F-31XX
SCK: SMD1,27-2,54
SCL: SMD1,27-2,54
SDA: SMD1,27-2,54
U1: AD8400AR1; SOIC127P600X175-8N
U$1: 2908-05WB-MG; MICROSD
USB: SMD1,27-2,54

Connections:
3V3: 3V3.1, C1.1, EPD_3V3.1, IC2.1, U1.6, U$1.4
BAT: BAT.1, IC1.14, LS1.1, R1.1
BEEP_CTRL: A5.1, U1.8
BUTTON_CTRL: A1.1, R2.1, R3.2
EN: EN.1, IC1.3, IC1.4
EPD_BUSY: D12.1, EPD_BUSY.1
EPD_CS: D6.1, EPD_CS.1
EPD_DC: D10.1, EPD_DC.1
EPD_RST: D11.1, EPD_RST.1
GND: C1.2, EPD_GND.1, GND.1, IC1.7, IC2.2, IC2.3, Q1.2, R2.2, S1.1, U1.1, U1.2, U$1.6
MISO: IC2.6, MISO.1, U$1.7
MOSI: EPD_MOSI.1, IC2.7, MOSI.1, U1.4, U$1.3
MS5611_CSB: D13.1, IC2.4, IC2.5
unnamed: IC1.1, IC1.10, R1.2, S1.2
unnamed: IC1.2, IC1.6
unnamed: IC1.8, R3.1
unnamed: Q1.1, R4.2
unnamed: LS1.2, Q1.3
POT_CS: A3.1, U1.3
PWR_CTRL: A0.1, IC1.5, IC1.9
SCK: EPD_SCK.1, IC2.8, SCK.1, U1.5, U$1.5
SD_CS: A2.1, U$1.2
WIPER: R4.1, U1.7

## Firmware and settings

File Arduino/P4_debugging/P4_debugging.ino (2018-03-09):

#include "MS5611.h"
#include "MS5611_I2C.h"
#include "FILTER.h"
#include "epd2in9.h"
#include "epdpaint.h"
#include "imagedata.h"
#include "BEEP.h"
#include "DEFAULT_SETTINGS.h"
#include "BUTTON.h"


#define BAUD_RATE                 115200    // Serial Monitor baud rate
#define POWER_PIN                     A0    // DEVICE POWERS OFF IF THIS PIN GOES LOW;
#define MS5611_CSB                    13    // Chip/Slave Select Pin
#define D1_OSR                         5    // (Default pressure OSR mode 5) 
#define D2_OSR                         2    // (Default temperature OSR mode 2) 
/*#define EPD_CS                         6
#define EPD_DC                        10
#define EPD_RST                       11
#define EPD_BUSY                      12*/
#define PRESSURE_FILTER_DURATION       0    // (AVERAGING DURATION: 1ms to 2000ms)
#define ALTITUDE_FILTER_DURATION    1000    // (AVERAGING DURATION: 1ms to 2000ms)
#define VSPEED_FILTER_DURATION      1000    // (AVERAGING DURATION: 1ms to 2000ms)
#define TEMPERATURE_FILTER_DURATION    0    // (AVERAGING DURATION: 1ms to 2000ms)
#define POT_CS                        A3
#define BEEP_PIN                      A5    // (Default A5) Pin connected to buzzer 
#define BUTTON_PIN                    A1    // CONNECT THE OTHER BUTTON LEAD TO 3.3V;


MS5611_SPI MS5611;
MS5611_I2C MS5611_I2C; 
FILTER1 FILTER1;
FILTER2 FILTER2;
FILTER3 FILTER3;
FILTER4 FILTER4;
BEEP BEEP;
Default SETTING;
BUTTON BUTTON;

#define COLORED     0
#define UNCOLORED   1
unsigned char image[1024];
Paint paint(image, 0, 0);    // width should be the multiple of 8 
Epd epd;

float temperatureF = 0;
float pressurePa = 0;
float altitudeFt = 0;
float velocityFtPerSec = 0;
unsigned long previousMillis = 0;
unsigned long displayMillis = 0;
int samplesThisSec = 0;    // Used for calculating averaging duration
int samplesPerSec = 0;     // Used for displaying samplesPerSec updated every once second

void adjustVolumeTo(int volLevel);
unsigned long loops = 0;


void setup() {  
  
  pinMode(POWER_PIN, OUTPUT);
  digitalWrite(POWER_PIN, HIGH);  //ONCE THIS PIN GOES LOW, THE DEVICE POWERS OFF; 
  
  Serial.begin(BAUD_RATE);
  //while(!Serial);
  
  //MS5611.begin(MS5611_CSB);
  MS5611_I2C.begin();
  MS5611_I2C.setOversampling(MS5611_HIGH_RES);

  /*BEEP.begin(BEEP_PIN);
  BEEP.setClimbThreshold(SETTING.CLIMB_BEEP_TRIGGER);       //ft climbed
  BEEP.setSinkAlarmThreshold(SETTING.SINK_ALARM_TRIGGER);   //ft/s
  BEEP.setClimbPitchMax(SETTING.CLIMB_PITCH_MAX);           //Hz
  BEEP.setClimbPitchMin(SETTING.CLIMB_PITCH_MIN);           //Hz
  BEEP.setSinkPitchMax(SETTING.SINK_PITCH_MAX);             //Hz
  BEEP.setSinkPitchMin(SETTING.SINK_PITCH_MIN);             //Hz*/  
  //for(int i=0; i<10; i++){
  //SETTING.VOLUME++;
  //if(SETTING.VOLUME>4){SETTING.VOLUME=0;}
  
  //adjustVolumeTo(SETTING.VOLUMES[SETTING.VOLUME]);
  //tone(BEEP_PIN, 400, 250);
  
  //delay(250);
  //}

  //epd.begin(EPD_CS, EPD_DC, EPD_RST, EPD_BUSY);
      //INITIALIZE FULL UPDATE MODE AT START UP TO COMPLETELY ERASE THE SCREEN: 
      if (epd.Init(lut_full_update) != 0) { Serial.println("e-Paper init failed"); }
      else{Serial.println("e-Paper init full success"); }
      //GET RID OF ANY GHOST IMAGE THAT REMAINS BY FLICKERING THE ENTIRE SCREEN:
      epd.ClearFrameMemory(0xFF);   // bit set = white, bit reset = black
      epd.DisplayFrame();
      epd.ClearFrameMemory(0xFF);   // bit set = white, bit reset = black
      epd.DisplayFrame();
      //INITIALIZE PARTIAL UPDATE MODE AFTER GHOST IMAGES ARE CLEARED:
      if (epd.Init(lut_partial_update) != 0) { Serial.println("e-Paper init failed"); }
      else{Serial.println("e-Paper init partial success"); }
      //???GET RID OF ANY GHOST IMAGE THAT REMAINS BY FLICKERING THE ENTIRE SCREEN:
      epd.ClearFrameMemory(0xFF);   // bit set = white, bit reset = black
      epd.DisplayFrame();
      epd.ClearFrameMemory(0xFF);   // bit set = white, bit reset = black
      epd.DisplayFrame();
}

void loop() {
  samplesThisSec++; //increment each time the loop cycles
  if(millis() - previousMillis >= 1000){ // Update value of samplesPerSec once every second:
    previousMillis=millis();
    samplesPerSec = samplesThisSec;
    samplesThisSec=0; 
    //Serial.println(samplesPerSec);  //print debug info
  }

      //====MS5611=================================================================/
        
        //TEMPERATURE:
        if(TEMPERATURE_FILTER_DURATION){
          temperatureF = FILTER4.RUNNING_AVERAGE(
            //MS5611.getTemperatureF(D2_OSR), 
            MS5611_I2C.readTemperature(),
            samplesPerSec, 
            TEMPERATURE_FILTER_DURATION
          );
          //temperatureF = 77;
        }
        else{
          //temperatureF = MS5611.getTemperatureF(D2_OSR);
          temperatureF = MS5611_I2C.readTemperature();
        }
        
        //PRESSURE:
        if(PRESSURE_FILTER_DURATION){
          pressurePa = FILTER1.RUNNING_AVERAGE(
            //MS5611.getPressurePa(D1_OSR),
            MS5611_I2C.readPressure(), 
            samplesPerSec, 
            PRESSURE_FILTER_DURATION
          );
        }
        else{
          //pressurePa = MS5611.getPressurePa(D1_OSR);
          pressurePa = MS5611_I2C.readPressure();
        }
        
        //ALTITUDE:
        if(ALTITUDE_FILTER_DURATION){
          altitudeFt = FILTER2.RUNNING_AVERAGE(
            MS5611.getAltitudeFt(temperatureF, pressurePa), 
            samplesPerSec, 
            ALTITUDE_FILTER_DURATION
          );
        }
        else{
          altitudeFt = MS5611.getAltitudeFt(temperatureF, pressurePa);
        }

        //VERTICAL SPEED:
        if(millis()>6000){
          if(VSPEED_FILTER_DURATION){
            velocityFtPerSec = FILTER3.RUNNING_AVERAGE(
              MS5611.getVelocityFtPerSec(altitudeFt, millis()), 
              samplesPerSec, 
              VSPEED_FILTER_DURATION
            );
          }
          else{
            velocityFtPerSec = MS5611.getVelocityFtPerSec(altitudeFt, millis());
          }
        }
        else{velocityFtPerSec=0;}

        //BEEP:
        //adjustVolumeTo(SETTING.VOLUMES[SETTING.VOLUME]);
        if(SETTING.ENABLE_BEEP && millis() > 7000){                                                                //BEEP
          //if(SETTING.BEEP_TYPE == 1){BEEP.basedOnVelocity(altitudeFt, velocityFtPerSec, millis());}
          //if(SETTING.BEEP_TYPE == 2){BEEP.bufferedDurationIncrements(altitudeFt, velocityFtPerSec, millis());}
        }
        

        //DEBUG:
        //Serial.println(temperatureF); 
        //Serial.println(pressurePa);
        //Serial.println(altitudeFt); 
        //Serial.print(" "); 
        Serial.println(velocityFtPerSec);



      //====EPD====================================================================/
        //WAIT FOR A CERTAIN NUMBER OF LOOPS BEFORE UPDATING THE EPAPER DISPLAY:
        if(loops++%/*1305*/900==0){
          if(!SETTING.ENABLE_OLED){SETTING.ENABLE_OLED=true; Serial.println("EPD ON");}
          else{SETTING.ENABLE_OLED=false; epd.Reset(); Serial.println("EPD OFF");}
        }
        if(SETTING.ENABLE_OLED && /*false &&*/ /*millis()-displayMillis>=1000 &&*/ digitalRead(12)==LOW){
          //delay(10);
          displayMillis = millis();
  /*
   *  
   *   |<------112px------>|
   *   |    |<----86px---->|
   *  _|____|______________|________
   * |_______TOP_BAR_______|______|_----- 18px
   * |     /  \            |      ^
   * |   /       \         |      |
   * |  / VARIO     \      |      |
   * | |              _\___|      |
   * | |_____________|     |      |
   * | |        __,--|_____|     158px
   * | | __,---'           |      |
   * |  \                  |      |
   * |   \                 |      |
   * |_____\_______________|______v_
   * |       ALTITUDE      |      ^_____28px
   * |_____________________|______v_
   * |                     |      ^
   * |       CHART         |      |
   * |                     |     92px
   * |                     |      |
   * |                     |      |
   * |_____________________|______v_
   */          
          // ______________________
          //|_______TOP_BAR:_______|
          //PRINT CLOCK:
          unsigned long time_now_s = (millis()) / 1000;
          char time_string[] = {'0', '0', ':', '0', '0', ':', '0', '0', '\0'};
          // 12:34:56 == 45296_s
          time_string[0] = time_now_s / 60 / 60 / 10 + '0'; //ten hr  ---> 45296 / 60 / 60 / 10 == 1
          time_string[1] = time_now_s / 60 / 60 / 10 + '0'; //one hr  ---> 45296 / 60 / 60 % 10 == 2
          time_string[3] = time_now_s / 60 / 10 + '0';      //ten min ---> 45296 / 60 % 60 / 10 == 3
          time_string[4] = time_now_s / 60 % 10 + '0';      //one min ---> 45296 / 60 % 10      == 4
          time_string[6] = time_now_s % 60 / 10 + '0';      //ten sec ---> 45296 % 60 / 10      == 5
          time_string[7] = time_now_s % 60 % 10 + '0';      //one sec ---> 45296 % 60 % 10      == 6
          paint.SetRotate(ROTATE_180);
          paint.SetWidth(128);
          paint.SetHeight(18);
          paint.Clear(UNCOLORED);
          paint.DrawStringAt(1, 1, time_string, &Font16, COLORED);  
          //TODO -- VOLUME ICON:
          //if(displayLoop%2 && SETTING.ENABLE_BEEP){ for(int j=2; j<=12; j++){ for(int i=0; i<=SETTING.VOLUME; i++){ paint.DrawPixel(110+i,j,COLORED); }}}
          paint.DrawHorizontalLine(0, 17, 128, COLORED);
          epd.SetFrameMemory(paint.GetImage(), 0, 278, paint.GetWidth(), paint.GetHeight());
          
          // _____________________
          //|________VARIO________|
          //PRINT VELOCITY:
          char velocity_string[] = {'-', '0', '0', ' '};
          // -9_ft/s == {' ', '-', '9'};
          if(velocityFtPerSec<=-10){      velocity_string[0] = '-';    velocity_string[1] = abs(velocityFtPerSec/10)+'0';    velocity_string[2] = abs((int)velocityFtPerSec%10)+'0'; }
          else if(velocityFtPerSec<0){    velocity_string[0] = ' ';    velocity_string[1] = '-';                             velocity_string[2] = abs((int)velocityFtPerSec)+'0';    }
          else if(velocityFtPerSec<10){   velocity_string[0] = ' ';    velocity_string[1] = ' ';                             velocity_string[2] = (int)velocityFtPerSec+'0';         }
          else{                           velocity_string[0] = ' ';    velocity_string[1] = (velocityFtPerSec/10)+'0';       velocity_string[2] = ((int)velocityFtPerSec%10)+'0';    }
          paint.SetRotate(ROTATE_180);
          paint.SetWidth(51);
          paint.SetHeight(28);
          paint.Clear(UNCOLORED);
          paint.DrawRectangle(1, 1, 55, 27, COLORED);
          paint.DrawStringAt(1, 4, velocity_string, &Font24, COLORED);
          //paint.DrawHorizontalLine(0, 17, 128, COLORED);
          epd.SetFrameMemory(paint.GetImage(), 0, 170, paint.GetWidth(), paint.GetHeight());
          
          //TODO -- NEEDLE:
          paint.SetRotate(ROTATE_180);
          paint.SetWidth(64);
          paint.SetHeight(120);
          paint.Clear(UNCOLORED);
          //paint.DrawStringAt(1, 1, time_string, &Font16, COLORED);
          paint.DrawHorizontalLine(0,60,64,COLORED);
          paint.DrawLine(0, 59-5*velocityFtPerSec, 64, 59, COLORED);
          paint.DrawLine(0, 60-5*velocityFtPerSec, 64, 60, COLORED);
          paint.DrawLine(0, 61-5*velocityFtPerSec, 64, 61, COLORED);
          epd.SetFrameMemory(paint.GetImage(), 63, 124, paint.GetWidth(), paint.GetHeight());
          
          // _____________________
          //|_______ALTITUDE______|
          //PRINT ALTITUDE:
          //UP TO FIVE DIGITS, OR UP TO FOUR DIGITS WITH A NEGATIVE SIGN:
        
          //TEMPORARILY REMOVE THE NEGATIVE SIGN BEFORE CONVERSION TO ASCII:
          int absNumber = abs(altitudeFt);
          
          //PARSE EACH DIGIT AND CONVERT TO ASCII CHARACTERS:
          int digit[] = {0,0,0,0,0};
          digit[4] = ((absNumber/10000)); //________________________________________________________________________________________________ = 0
          digit[3] = ((absNumber/1000) - (digit[4]*10)); //_________________________________________________________________________ = 4 - 0 = 4
          digit[2] = ((absNumber/100) - (digit[4]*100) - (digit[3]*10)); //___________________________________________________ = 45 - 0 - 40 = 5
          digit[1] = ((absNumber/10) - (digit[4]*1000) - (digit[3]*100) - (digit[2]*10)); //___________________________ = 451 - 0 - 400 - 50 = 1
          digit[0] = ((absNumber) - (digit[4]*10000) - (digit[3]*1000) - (digit[2]*100) - (digit[1]*10)); //___ = 4513 - 0 - 4000 - 500 - 10 = 3
          //EXAMPLE: digit[]={3,1,5,4,0} == ALTITUDE OF 4513;
        
          //SHIFT THE VALUES OF EACH DIGIT TO MATCH WITH ASCII TABLE: (' ' == 0 , '0' == 48 , '2' == 50 , ...)
          for(int i=0; i<=4; i++){digit[i]+=48;}
        
          //RE-INSERT NEGATIVE SIGN IF NEEDED AND TRIM LEADING ZEROS:
          if(altitudeFt<0){
            if(digit[1]=='0' && digit[2]=='0' && digit[3]=='0' && digit[4]=='0'){
              digit[1]='-'; 
              for(int i=2; i<=4; i++){digit[i]=' ';}
            }
            else if(digit[2]=='0' && digit[3]=='0' && digit[4]=='0'){
              digit[2]='-';
              for(int i=3; i<=4; i++){digit[i]=' ';}
            }
            else if(digit[3]=='0' && digit[4]=='0'){
              digit[3]='-';
              digit[4]=' ';
            }
            else{
              digit[4]='-';
            }
          }
        
          //FOR POSITIVE NUMBERS, SIMPLY REMOVE LEADING ZEROS
          else{
            if(digit[1]=='0' && digit[2]=='0' && digit[3]=='0' && digit[4]=='0'){
              for(int i=1; i<=4; i++){digit[i]=' ';}
            }
            else if(digit[2]=='0' && digit[3]=='0' && digit[4]=='0'){
              for(int i=2; i<=4; i++){digit[i]=' ';}
            }
            else if(digit[3]=='0' && digit[4]=='0'){
              for(int i=3; i<=4; i++){digit[i]=' ';}
            }
            else if(digit[4]=='0'){
              digit[4]=' ';
            }    
          }
          
          //DEBUG:
          //while(!Serial){};
          //for(int i=4; i>=0; i--){delay(10); Serial.print(digit[i]);} Serial.println();  
          
          paint.SetRotate(ROTATE_180);
          paint.SetWidth(128);
          paint.SetHeight(28);
          paint.Clear(UNCOLORED);
          //BOUNDING BOX:
          paint.DrawRectangle(1, 1, 88, 27, COLORED);
          for(int i=4; i>=0; i--){int j = 4-i; paint.DrawCharAt(2+(17*j), 4, digit[i], &Font24, COLORED);}
          epd.SetFrameMemory(paint.GetImage(), 0, 92, paint.GetWidth(), paint.GetHeight());
          epd.DisplayFrame();
        }
        else if(!SETTING.ENABLE_OLED){
          //delayMicroseconds(192);
          delay(2);
        }/*end epd*/



    /*if(millis()>10000){BUTTON.PRESS=BUTTON.CHECK(BUTTON_PIN, millis());}
    if(BUTTON.PRESS==BUTTON.CLICK){
      BUTTON.PRESS=BUTTON.NO_ACTION; 
      
      //SETTING.VOLUME++;
      //if(SETTING.VOLUME>4){SETTING.VOLUME=0; SETTING.ENABLE_BEEP=0;}
      //else if(SETTING.VOLUME==1){SETTING.ENABLE_BEEP=1;}
      //adjustVolumeTo(SETTING.VOLUMES[SETTING.VOLUME]);
      //Serial.print("adjustVolumeTo("); 
      //Serial.print(SETTING.VOLUMES[SETTING.VOLUME]); 
      //Serial.println(")");
      
      SETTING.ENABLE_BEEP=!SETTING.ENABLE_BEEP;
      if(SETTING.ENABLE_BEEP){SETTING.ENABLE_OLED=false; epd.Reset();}
      else{SETTING.ENABLE_OLED=true;}
      if(SETTING.ENABLE_BEEP){tone(BEEP_PIN, 400, 250);}
    }
    if(BUTTON.PRESS==BUTTON.HOLD){
      BUTTON.PRESS=BUTTON.NO_ACTION; 
      SETTING.ENABLE_OLED=!SETTING.ENABLE_OLED;
      digitalWrite(POWER_PIN, LOW); //POWER OFF;
    }*/     
       

}/*end loop*/






void adjustVolumeTo(int volLevel){
  
  // take the SS pin low to select the chip:
  digitalWrite(POT_CS, LOW);
  
  //  send in the address and value via SPI:
  int address = 0;
  SPI.transfer(address);
  SPI.transfer(volLevel);
  
  // take the SS pin high to de-select the chip:
  digitalWrite(POT_CS, HIGH);
}

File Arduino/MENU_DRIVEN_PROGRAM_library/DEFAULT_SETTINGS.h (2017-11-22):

#ifndef DEFAULT_SETTINGS_H
#define DEFAULT_SETTINGS_H

class Default{

  public:
  
    bool ENABLE_BEEP                 = 1;    // [1]YES, [0]NO
    int VOLUME                       = 1;    // (0-4);
    int VOLUMES[5] = { 0, 23, 28, 40, 100 };
    int VOLUME_MAX                 = 100;
    int VOLUME_MIN                   = 0;
    
    float CLIMB_BEEP_TRIGGER       = 1.0;    // (Default 1.0 ft)
    float CLIMB_THRESH_MAX        = 10.0;
    float CLIMB_THRESH_MIN         = 1.0;
    
    float SINK_ALARM_TRIGGER      = -1.0;    // (Default -1.0 ft/s)
    float SINK_THRESH_MAX         = -1.0;
    float SINK_THRESH_MIN        = -10.0;
    
    float CLIMB_PITCH_MAX        = 500.0;    // (Default 500.0 Hz)
    float CLIMB_PITCH_MIN        = 300.0;    // (Default 300.0 Hz)
    
    float SINK_PITCH_MAX         = 250.0;    // (Default 250.0 Hz)
    float SINK_PITCH_MIN         = 150.0;    // (Default 150.0 Hz)
    
    int BEEP_TYPE                    = 1;    // DEFAULT [1]BASED_ON_VELOCITY, [2]BUFFERED_INCREMENTS

    bool ENABLE_OLED                 = 1;    // [1]YES, [0]NO
    float CHART_SPEED               = 30;    // Seconds for completion; Live speed if zero;

    bool MEASURE_BATTERY             = 1;    // [1]YES, [0]NO

    bool ENABLE_BLUETOOTH            = 1;    // [1]YES, [0]NO
    int BLUETOOTH_MODE               = 2;    // [1]VSPEED_ANDROID, [2]FLYSKYHY_IOS

    String USER_NAME_1       = "BRAEDIN";
    String USER_NAME_2          = "PAUL";
    int USER                         = 1;
  
};
    
#endif

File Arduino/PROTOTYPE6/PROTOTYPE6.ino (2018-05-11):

#include "MS5611.h"
#include "BEEP.h"
#include "FILTER.h"
#include "vAdafruit_BluefruitLE_SPI.h"
#include "DEFAULT_SETTINGS.h"
//#include "X9C.h"

#define POT_UD                        A0
#define POT_INC                       A1
#define VOL_DOWN                      A2
#define VOL_UP                        A3
#define POT_CS                        A4
#define BEEP_CTRL                     A5
#define MS5611_CSB                    13
#define VBATPIN                        9    // Pin monitors battery level (Pin A7)
#define BLUEFRUIT_SPI_CS               8
#define BLUEFRUIT_SPI_IRQ              7
#define BLUEFRUIT_SPI_RST              4    // Optional but recommended set 4, set to -1 if unused...


#define BAUD_RATE                 115200    // Serial Monitor baud rate
#define D1_OSR                         5    // (Default pressure OSR mode 5) 
#define D2_OSR                         2    // (Default temperature OSR mode 2) 
#define VERBOSE_MODE               true    // If set to 'true' enables debug output
#define PRESSURE_FILTER_DURATION       0    // (AVERAGING DURATION: 1ms to 2000ms)
#define ALTITUDE_FILTER_DURATION    1000    // (AVERAGING DURATION: 1ms to 2000ms)
#define VSPEED_FILTER_DURATION       750    // (AVERAGING DURATION: 1ms to 2000ms)
#define TEMPERATURE_FILTER_DURATION    0    // (AVERAGING DURATION: 1ms to 2000ms)


Default SETTING;
MS5611_SPI MS5611;
FILTER1 FILTER1;
FILTER2 FILTER2;
FILTER3 FILTER3;
FILTER4 FILTER4;
BEEP BEEP;
vAdafruit_BluefruitLE_SPI ble(BLUEFRUIT_SPI_CS, BLUEFRUIT_SPI_IRQ, BLUEFRUIT_SPI_RST);
//X9C X9C;



void SWITCH_BLE_MODE(int bluetoothMode);    // BLE MODULE INITIALIZES ACCORDING TO SPECIFIED BLUETOOTH_MODE;
void receiveCommands();
void transmitVspeed();
void transmitFlySkyHy();
void adjustVolumeTo(int volLevel);  // 0 - 100;
void volumeUp();
void volumeDown();
float getBatteryLvl();    //Volts



float temperatureF = 0;
float pressurePa = 0;
float altitudeFt = 0;
float velocityFtPerSec = 0;
unsigned long previousMillis = 0;
int samplesThisSec = 0;    // Used for calculating averaging duration
int samplesPerSec = 0;     // Used for displaying samplesPerSec updated every once second
int BLUETOOTH_MODE = 0;    // iOS_Flyskyhy[2];  Android_v^SPEED[1]; NONE[0];
long battMillis = -5000;
float batteryLvl = 0;
int batteryPercent = 100;
int estimatedVolume = 0;
int volDelay = 150;   // Volume shall only be changed every 100ms;
unsigned long volMillis = 0;
bool bleFlag = true;
unsigned long bleMillis = 0;
int blePerSec = 30;
int bleInterval = 1000/(float)blePerSec;


void setup() {
  
  pinMode(VBATPIN, INPUT);
  
  pinMode(POT_CS,OUTPUT);
  pinMode(POT_UD,OUTPUT);
  pinMode(POT_INC,OUTPUT);
  digitalWrite(POT_INC,HIGH);
  digitalWrite(POT_UD,LOW);
  digitalWrite(POT_CS,HIGH);

  pinMode(VOL_UP, INPUT);
  pinMode(VOL_DOWN, INPUT);
  
  Serial.begin(BAUD_RATE);

  //X9C.begin(POT_CS, POT_INC, POT_UD);
  
  
  if(!MS5611.begin(MS5611_CSB)){
    Serial.println("MS5611 failed.");
  }
  else{
    Serial.println("MS5611 success.");
  }
  
  BEEP.begin(BEEP_CTRL);
  BEEP.setClimbThreshold(SETTING.CLIMB_BEEP_TRIGGER);       //ft climbed
  BEEP.setSinkAlarmThreshold(SETTING.SINK_BEEP_TRIGGER);    //ft/s
  BEEP.setClimbPitchMax(SETTING.CLIMB_PITCH_MAX);           //Hz
  BEEP.setClimbPitchMin(SETTING.CLIMB_PITCH_MIN);           //Hz
  BEEP.setSinkPitchMax(SETTING.SINK_PITCH_MAX);             //Hz
  BEEP.setSinkPitchMin(SETTING.SINK_PITCH_MIN);             //Hz

  if(SETTING.ENABLE_BLUETOOTH){
    if(analogRead(VOL_DOWN)<500){BLUETOOTH_MODE = 1;} // Android_v^SPEED mode;
    else if(analogRead(VOL_UP)<500){BLUETOOTH_MODE = 2;} // iOS_Flyskyky mode;
    else{
      BLUETOOTH_MODE = SETTING.START_UP_BLUETOOTH_MODE; 
      if(BLUETOOTH_MODE == 0){
        SETTING.ENABLE_BLUETOOTH = false;  // START_UP_BLUETOOTH_MODE DEFINED IN "DEFAULT_SETTINGS.h";
      }
    }   
    
    ble.begin(VERBOSE_MODE);
    SWITCH_BLE_MODE(BLUETOOTH_MODE);  //INITIALIZES THE SPECIFIED BLUETOOTH MODE; 
  }
  
  batteryLvl = getBatteryLvl();
  batteryPercent = (int)(batteryLvl*156.25 - 556.25);  //conversion to percent;
  if(batteryPercent > 99){batteryPercent = 99;}
  else if(batteryPercent < 0){batteryPercent = 0;}

  adjustVolumeTo(SETTING.START_UP_VOLUME);
  estimatedVolume = SETTING.START_UP_VOLUME;

  if(BLUETOOTH_MODE==1){
    tone(BEEP_CTRL, 500, 100);
    delay(1000);
  }
  else if(BLUETOOTH_MODE==2){
    tone(BEEP_CTRL, 500, 100);
    delay(200);
    tone(BEEP_CTRL, 500, 100);
    delay(1000);
  }

  if(batteryPercent>75){
    tone(BEEP_CTRL, 300, 100);
    delay(200);
    tone(BEEP_CTRL, 400, 100);
    delay(200);
    tone(BEEP_CTRL, 500, 100);
    delay(200);
  }
  else if(batteryPercent>50){
    tone(BEEP_CTRL, 400, 100);
    delay(200);
    tone(BEEP_CTRL, 400, 100);
    delay(200);
    tone(BEEP_CTRL, 400, 100);
    delay(200);
  }
  else if(batteryPercent<25){
    tone(BEEP_CTRL, 500, 100);
    delay(200);
    tone(BEEP_CTRL, 400, 100);
    delay(200);
    tone(BEEP_CTRL, 300, 100);
    delay(200);
  }
  
}
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

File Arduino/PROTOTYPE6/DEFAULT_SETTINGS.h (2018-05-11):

#ifndef DEFAULT_SETTINGS_H
#define DEFAULT_SETTINGS_H

class Default{
  public:
  
    bool ENABLE_BEEP                 = 1;    // [1]YES, [0]NO
    int START_UP_VOLUME             = 10;    // (0 to 31)
    int BEEP_TYPE                    = 1;    // DEFAULT [1]BASED_ON_VELOCITY, [2]BUFFERED_INCREMENTS
    
    float CLIMB_BEEP_TRIGGER       = 1.0;    // (Default 1.0 ft)
    float SINK_BEEP_TRIGGER       = -1.0;    // (Default -1.0 ft/s)

    float CLIMB_PITCH_MAX        = 500.0;    // (Default 500.0 Hz)
    float CLIMB_PITCH_MIN        = 350.0;    // (Default 300.0 Hz)
    
    float SINK_PITCH_MAX         = 250.0;    // (Default 250.0 Hz)
    float SINK_PITCH_MIN         = 150.0;    // (Default 150.0 Hz)
    
    bool MEASURE_BATTERY             = 1;    // [1]YES, [0]NO

    bool ENABLE_BLUETOOTH            = 1;    // [1]YES, [0]NO
    int START_UP_BLUETOOTH_MODE      = 1;    // [0]DISABLE, [1]VSPEED_ANDROID, [2]FLYSKYHY_IOS

};
    
#endif

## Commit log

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2017-08-14 Debugged bluetooth transmission completion errors, and defaulted arduino code to transmit samplesPerSec for velocity calculation.
2017-08-15 Don't know why I didn't do this in the first place, but I just replaced the transmission of samplesPerSec to v5avg. Much smoother on the app's liveChart
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2017-08-18 ADDED PROTOTYPE1.5
    SAME AS PROTOTYPE1, BUT WITH ALTITUDE BASED BEEPS FROM MY BEEP LIBRARY.
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2017-08-21 On a more advanced device than my tracfone, the beeps don't make the app crash. otherwise, even with my tracfone, I fixed most of the issue by removing the overlapping tones. Just avoid fast calls to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
2017-08-24 drawing colored velocity dots on perimeter of ThermalBearing liftWidget. (not tested yet)
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2017-09-06 my custom parts now available
    [1.2.4 CASE - BACK COVER.STL, 1.2.4 CASE - FRONT SHELL.STL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]
2017-09-06 See the "Shared Parts List" tab
    [INVENTORY.xlsx]
2017-09-06 see "Shared Parts List" tab
    also see "PCB and PINOUTS" tab for brief assembly. TODO -- insert exploded views of assembly.
    [INVENTORY.xlsx]
2017-09-06 custom parts from solidworks and fritzing
    [INVENTORY.xlsx]
2017-09-07 V2 CASING FOR PROTOTYPE2
    [1.2.4 CASE - BACK COVER.STL, 1.2.4 CASE - FRONT SHELL.STL]
2017-09-07 FULL SOLIDWORKS PARTS AND ASSEMBLY FILES
    [1.2.4 CASE - BACK COVER.STL, 1.2.4 CASE - FRONT SHELL.STL, P2_0.66 INCH OLED.SLDPRT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]
2017-09-07 custom parts
    [P2_CASE - BACK COVER.SLDPRT, P2_CASE - FRONT SHELL.SLDPRT]
2017-09-08 THINKING ABOUT BLACK CASING
    [1.2.4 CASE - BACK COVER.STL, 1.2.4 CASE - FRONT SHELL.STL]
2017-09-08 SOLIDWORKS PARTS
    [INVENTORY.xlsx, P2_0.66 INCH OLED.SLDPRT, P2_1 PIN MALE HEADER.SLDPRT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]
2017-09-08 Exploded View
    [P2_0.66 INCH OLED.SLDPRT, P2_1 PIN MALE HEADER.SLDPRT, P2_1.2.4 CASE - BACK COVER.SLDPRT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]
2017-09-10 iOS bluetooth support
    commands:
    "a" = transmit only integer value of altitude.
    "s" = transmit only integer value of vertical speed.
    "i"= transmit normal data. (exit iOS mode)
    I can't afford an Apple Developer membership, so I had to make due with what is already available in the app store. 1) Adafruit Bluefruit LE Connect to adjust settings of the Variometer, then 2) swit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
    [INVENTORY.xlsx]
2017-09-12 14sps for proto1 and averaged per 1sec (for my dad)
    [INVENTORY.xlsx]
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2017-09-14 Purchased flyskyhy on my wife's phone
    [INVENTORY.xlsx]
2017-09-15 Trying to make PROTOTYPE3 code work.
    TODO -- FIGURE OUT WHY THE M0 GLITCHES AND LAGS... POSSIBLY HARDWARE BUGS? SOLDER JOINTS?
    [INVENTORY.xlsx]
2017-09-16 Inventory of Parts
    [INVENTORY.xlsx]
2017-09-16 error message if newData doesn't seem correct
    [FILTER.cpp, FILTER.h]
2017-09-16 Still... No luck getting rid of the M0 clock glitches
    Other smaller sketches work just fine. But then when I add the PROTOTYPE2 or 3 sketch, things go berzerk.. :(
    //TODO -- KEEP DIAGNOSING!!!
2017-09-16 THE GLITCHES HAPPEN WHEN BLE IS ENABLED!!! //--to solve
    [FILTER.cpp, FILTER.h, MS5611.cpp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]
2017-09-23 Adafruit's Bluefruit Library
    I hope to simplify as much as possible, but this would only be useful if using on a feather 32u4, where the memory is maxed out using the PROTOTYPE3 sketch. The M0 handles the sketch just fine, with 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
2017-09-23 its always an option to change pressure at sea level according to local airports
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2017-10-08 BOM
    //TODO -- Redesign PROTOTYPE4 with the NOKIA 5110 LCD screen instead of 0.66 inch OLED.
    //TODO -- Continue investigating compatibility with Flyskyhy iPhone app for Paragliding.
    [INVENTORY.xlsx]
2017-10-10 BOUGHT A NEW PRESSURE SENSOR FOR PROTOTYPE2. CURRENT ONE MALFUNCTIONED. MAYBE DEBRIS GOT INTO THE SENSOR?
    [INVENTORY.xlsx]
2017-10-19 Designing a new PCB
    [PROTOTYPE4.fzz]
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2017-10-19 This would explain several of the crashes at startup. It was measuring 90 samples per second after I did some additional tasks in the setup();
    [FILTER.h]
2017-10-19 I put a lower limit on the pitch so it wouldn't go negative and crash the vario.
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2017-10-23 bought a digital potentiometer
    [INVENTORY.xlsx]
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2017-11-01 new parts
    [INVENTORY.xlsx]
2017-11-01 DESIGNING PROTOTYPE4
    [P4_0.66 INCH OLED.SLDPRT, P4_1 PIN MALE HEADER.SLDPRT, P4_1PIN_8.25_LONG_SOCKET.SLDPRT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]
2017-11-03 TAKING A HUGE LEAP IN THE DARK TO ADD A MENU DRIVEN PROGRAM, AND HAVING SETTINGS SAVED TO A MICRO SD
    [2017-11-01T21-27-10.csv, INVENTORY.xlsx, P4_0.66 INCH OLED.SLDPRT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]
2017-11-05 Starting to roll a little bit with menu driven program. (not even close to finished)
    [MENU_DRIVEN_PROGRAM_FLOWCHART.xlsx]
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2017-11-07 FIGURING OUT POWER/CONTROL BUTTON
    [INVENTORY.xlsx, PARTS_FOR_FEATHER_POWER_BUTTON.xlsx]
2017-11-08 STILL WORKING ON A SIMPLIFIED MENU DRIVEN PROGRAM. SUCCESSFUL SO FAR!
    [MENU_DRIVEN_PROGRAM_FLOWCHART.xlsx]
2017-11-08 PARTS TO TRY AND BUILD A POWER BUTTON FOR THE ADAFRUIT FEATHER
    [INVENTORY.xlsx]
2017-11-09 MENU DRIVEN PROGRAM IS ON FIRE RIGHT NOW
    [MENU_DRIVEN_PROGRAM_FLOWCHART.xlsx]
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2017-11-11 Controlling a digital volume control with the menu... SUCCESSFULLY!
    TODO-- IMPLEMENT WITH MICRO SD
    TODO-- FINISH IMPLEMENTING WITH THE REMAINING TASKS (MS5611, BLE, FLITER, etc...)
    [2017-11-01T21-27-10.csv, INVENTORY.xlsx, MENU_DRIVEN_PROGRAM_FLOWCHART.xlsx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]
2017-11-22 AN ENTIRELY NEW CONCEPT... EPAPER
    [INVENTORY.xlsx, P4_0.66 INCH OLED.SLDPRT, P4_1 PIN MALE HEADER.SLDPRT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]
2017-11-22 ONE MORE STEP CLOSER TO REALISTIC
    [P4_2.9_EPD.SLDASM, P4_2.9_EPD.SLDPRT, P4_2.9_EPD_CASE_BACK.SLDPRT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]
2017-11-23 PROTOTYPE4 IN PROGRESS
    [P2_1.2.4 CASE - BACK COVER.SLDPRT, P2_1.2.4 CASE - FRONT SHELL.SLDPRT, P2_PROTOTYPE2.SLDASM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]
2017-11-23 CONCEPT FOR RISER MOUNTING
    [ALÇA.SLDPRT, CARABINER SUP AIR Ø12.SLDASM, GATILHO.SLDPRT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]
2017-11-25 stuffs gettin real (rendered) in solidworks with P4
    [ALÇA.SLDPRT, CARABINER SUP AIR Ø12.SLDASM, GATILHO.SLDPRT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]
2017-11-29 ORGANIZED A BIT MORE
    [0.66 INCH OLED.SLDPRT, 1 PIN MALE HEADER.SLDPRT, 2 PIN MALE HEADER.SLDPRT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]
2017-11-29 p2 is same as p3 except printed case and m0
    [P2_0.66 INCH OLED.SLDPRT, P2_1 PIN MALE HEADER.SLDPRT, P2_1.2.4 CASE - BACK COVER.SLDPRT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]
2017-11-29 github is eating all my SolidWorks Part files!!! (TEST)
    [Part1.SLDPRT]
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2018-03-09 P4 is having major issues. Moving on to P5.
    [CARABINER SUP AIR.SLDASM, CARABINER_ARM.SLDPRT, CARABINER_MAIN.SLDPRT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]
2018-04-16 REFLOW TOASTER
    [54510334.csv, 76541515665364985.xlsx, P6_BOM.xlsx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]
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2018-05-03 published app
    [Adafruit Feather Zero BLE rev B.GBL, Adafruit Feather Zero BLE rev B.GBO, Adafruit Feather Zero BLE rev B.GBP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]
2018-05-11 bugs with sinkBeep options fixed
    [BEEP.cpp, BEEP.h, DEFAULT_SETTINGS.h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]
2018-12-19 updated bom
    [P6_BOM.xlsx, P6_SEEED_BOM.xlsx, P6_SEEED_BOM_V2.xlsx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]

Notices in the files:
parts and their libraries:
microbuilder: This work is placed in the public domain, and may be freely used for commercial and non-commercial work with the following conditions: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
